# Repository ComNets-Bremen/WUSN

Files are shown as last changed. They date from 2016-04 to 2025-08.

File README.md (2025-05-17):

# MoleNet: A Wireless Underground Sensor Network Platform

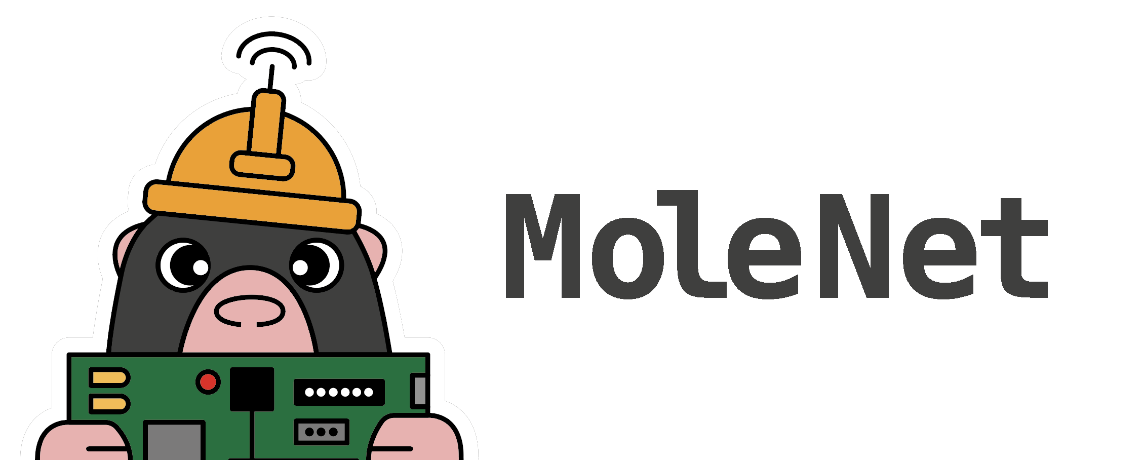
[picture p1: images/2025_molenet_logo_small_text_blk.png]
MoleNet Logo


**MoleNet** is a versatile Wireless Underground Sensor Network (WUSN) platform designed for education and low-power environmental monitoring.
This repository contains all relevant resources, including PCB layouts, source code, and examples to test and evaluate the platform.

Further information can be found on the official [MoleNet Website](https://molenet.org/)!

> ⚠️ **Note:** This is an active project. The files and directory structure are subject to change.

## New ESP32-based MoleNet!

After a long journey, we are finally at a point where we are testing the current version on a larger scale.
The latest version of MoleNet features several key improvements:

- **ESP32-S3 microcontroller**: A powerful yet energy-efficient processor that supports various development ecosystems including [MicroPython](https://micropython.org/), [Arduino](https://www.arduino.cc/), and [RiotOS](https://www.riot-os.org/)
- **SDI-12 sensor interface**: Compatible with high-quality environmental sensors
- **Micro-SD card support**: Enables extensive local data storage
- **SX1276-based LoRa transceiver**: Provides long-range wireless communication
- **On-board BME280 sensor**: Measures temperature, barometric pressure, and humidity [BME280](https://www.bosch-sensortec.com/products/environmental-sensors/humidity-sensors-bme280/)
- **Low-power design**: Ensures long battery life for extended deployments
- **qwiic connectivity**: Simplifies integration of I2C-based sensors, as, for
  example, available here: [Sparkfun](https://www.sparkfun.com/qwiic)

## Older Versions

Documentation for the ATMEGA-based MoleNet boards can be found in the [documentation directory](docs/MoleNet_ATMEGA.md).

## Changelog

The list of changes and the evolution of MoleNet is listed in the
[changelog](CHANGELOG.md).

## Publications

The following list gives some MoleNet-related publications:

- Gellhaar, M., Dede, J., Koehler, H., & Förster, A. (2016, February). Design and Evaluation of Underground Wireless Sensor Networks for Reforestation Monitoring. [In EWSN (pp. 229-230)](https://dl.acm.org/doi/10.5555/2893711.2893747).
- Zaman, I., Dede, J., Gellhaar, M., Koehler, H., & Foerster, A. (2016). Molenet: A new sensor node for underground monitoring. [IEEE SenseApp](https://www.researchgate.net/publication/309397324_MoleNet_A_New_Sensor_Node_for_Underground_Monitoring).
- Zaman, I., Gellhaar, M., Dede, J., Koehler, H., & Foerster, A. (2016, November). Design and evaluation of MoleNet for wireless underground sensor networks. In 2016 IEEE 41st conference on local computer networks workshops (LCN workshops) (pp. 145-147), [2016 IEEE 41st Conference on Local Computer Networks Workshops (LCN Workshops), Dubai, United Arab Emirates, 2016, pp. 145-147](https://doi.org/10.1109/LCN.2016.040).
- Dede, J., Helms, D., & Förster, A. (2021). MoleNet: An Underground Sensor Network for Soil Monitoring. [Electronic Communications of the EASST, 80](https://doi.org/10.14279/tuj.eceasst.80.1132)
- Sambo, D. W., Dede, J., Mitton, N., & Förster, A. (2023). FuzDeMa: A portable Fuzzy-based Decision-Making tool for reliable communication in Wireless Underground Sensor Networks. [ITU Journal on Future and Evolving Technologies, 4(3), 419-433](https://www.doi.org/10.52953/IXIP2995).

## I Want to Have MoleNet!

MoleNet is a dynamic project that is constantly evolving. At its current stage, we do not offer a ready-to-use, fully certified product with complete end-user support.

If you would like to contribute to the development of MoleNet and need hardware for testing and further development, you have two options:

1. **Build the hardware yourself.** All the necessary resources can be found in this repository.
2. **Order evaluation boards** from our partner [Intergalactic Circuits](https://intergalactic-circuits.de) for personal use.

## Contributors

Many students and researchers contribute to the MoleNet project.
See the full list of contributors in [CONTRIBUTORS.md](CONTRIBUTORS.md).

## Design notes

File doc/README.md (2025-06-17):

# Documentation

This directory contains the documentation of MoleNet. For the previous
versions, please refer to the [ATMEGA](ATMEGA) or [stm32](stm32) directory, respectively.

# The Hardware

MoleNet 6.1 with all available components assembled. Click on the image for a
high resolution version.

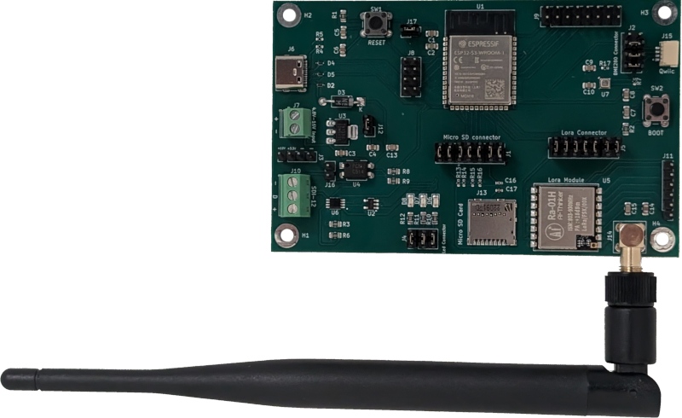
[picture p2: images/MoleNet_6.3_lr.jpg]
The MoleNet 6.3 hardware


## Available Components

- LoRa (SX1276) via Ra-01H module
- BME280
- SD-card holder
- qwiic for external I2C components
- LEDs
- SDI-12 for environmental sensors
- Additional pins (analog and digital)

## Components and their Connections

MoleNet contains various different on-board parts. The following tables lists
the connections and other relevant information for the major parts. For further
details, refer to [schematics of the board](../PCB-Layouts/). The table lists
the part of the board revision 6.3.

| **Part** | **Part Number** | **Description** | **Pins** |
|---|---|---|---|
| SW1 | SKHHARA010 | Reset button (enable) for ESP32 | EN |
| SW2 | SKHHARA010 | Boot mode button for ESP32 | GPIO0 |
| U1 | [ESP32-S3-WROOM-1-N16](https://www.espressif.com/sites/default/files/documentation/esp32-s3-wroom-1_wroom-1u_datasheet_en.pdf) | ESP32-S3 | |
| U3 | [TLV76133DCYR](https://www.ti.com/product/de-de/TLV761/part-details/TLV76133DCYR) | Voltage regulator 3V3 | |
| U5 | Ra-01H | LoRa Module ([SX1276](https://www.semtech.com/products/wireless-rf/lora-connect/sx1276)) | RESET=GPIO15, NSS=GPIO48, MOSI=GPIO47, MISO=GPIO21, SCK=GPIO14, DIO0=GPIO46 |
| U7 | [BME280](https://www.bosch-sensortec.com/products/environmental-sensors/humidity-sensors-bme280/) | Sensor for humidity, barometric pressure and ambient temperature | I2C, SCL=GPIO8, SDA=GPIO9, address=0x76 |
| D6 | NCD0805R1 | User LED | GPIO38 |
| D7 | NCD0805R1 | User LED | GPIO2 |
| D8 | NCD0805R1 | Power LED | Power |
| J1 | | Enable SD-card via jumpers | Power=GPIO7 (optional), MOSI=GPIO11, MISO=GPIO13, SCK=GPIO12, CS=GPIO10 |
| J2 | | Enable BME280 connection via jumpers | |
| J3 | | Power out | GND, 3V3, Vin |
| J4 | | Enable LEDs via jumpers | |
| J5 | | Enable LoRa via jumpers | |
| J6 | | USB connector | |
| J7 | | Power in | |
| J8 | | Misc. pins (ADC etc.) | |
| J9 | | Unused GPIOs | |
| J10 | | SDI-12 connector | Uses the following GPIOs: Power=GPIO1, SDI_RX_ENABLE=GPIO36, SDI_RX=GPIO18, SDI_TX_ENABLE=GPIO35, SDI_TX=GPIO17, SDI_MARKING=GPIO37 |
| J11 | | Remaining DIOs from LoRa transceiver | |
| J12 | | Power connector for energy measurements of the entire board. Connect via jumper | |
| J13 | | Micro SD card holder | |
| J14 | SMA-KWE902 | SMA connector for LoRa | |
| J15 | | qwiic connector for I2C devices | SCL=GPIO8, SDA=GPIO9 (shared with BME280) |
| J16 | | Power SDI-12 interface via jumper. Alternative: switch using GPIO1 | |
| J17 | | Jumper for ESP32 power supply. Used to measure only the power consumption of the ESP. Connect via jumper. | |

## Pins on the ESP32

For the usage of the pins, please refer to the hardware section in this
document or the schematics of the corresponding versions available in [the PCB-Layouts directory](../PCB-Layouts/).

# Setup using Arduino

1) Install **Arduino IDE** -> [arduino.cc](https://www.arduino.cc/en/software/)
2) Install the **esp32** package by Espressif via the **Boards Manager** in the IDE
3) Select the **ESP32S3 Dev Module** as the board
4) Select the corresponding USB port
5) Set USB CDC On Boot: Enabled
6) Set USB Mode: USB-OTG (Tiny USB)

**⚠️ Attention: Different ports!**

Different ports are created at various times when the MoleNet platform is connected to the computer. One port is to flash the firmware, while the second is to access the MoleNet Platform’s serial port. The first is the default after a reset. The second is usually entered if the boot button is pressed during reset or when powering up the board.

Usually, you have to setup the board twice according to the settings above. Be
aware that the port identifier can change depending on your operating system.

# Setup using MicroPython

Please use the documentation for the ESP32 available at
[micropython.org](https://micropython.org/download/ESP32_GENERIC_S3/).

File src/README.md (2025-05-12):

MoleNet Sourcecode
==================

The sourcecode of MoleNet. For older Versions, i.e. the ATMEGA-based versions,
please check the directory [ATMEGA-based](ATMEGA-based).

The other directories contain the code examples for the ESP32-based versions.

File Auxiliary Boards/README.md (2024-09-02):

This folder contains files for auxiliary pcbs related to Molenet project.

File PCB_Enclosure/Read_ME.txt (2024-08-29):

The PCB Enclousre is designed for the Molenet_V5.2 PCB Design. The enclosure is designed in Freecad 0.19.

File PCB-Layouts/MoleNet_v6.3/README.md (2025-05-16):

This folder contain Kicad files of Molenet V6.3 Board.

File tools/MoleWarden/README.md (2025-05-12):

MoleWarden - The MoleNet Maintanance Tool
=========================================

This tool is kind of proof of concept. It should automatize the repeating tasks
for

- Setting up and testing new devices
- Repeating testing existing devices (returned from test campaigns etc.)
- Install the MicroPython VM
- Keep track of the devices: When have they been tested last time?

Start the script
================

This script is tested using Debian Linux.

1) Create a venv: `python -m venv venv`
2) Activate the venv: `. ./venv/bin/activate`
3) Install the requirements: `pip install -r requirements.txt`
4) Run the script: `./run.py`

Update the requirements.txt
===========================

To update the [requirements.txt](requirements.txt), follow those steps:

1) Make sure pipreqs is installed: `pip install pipreqs`
2) Save the requirements: `pipreqs .`

Ideally, everything should be located in a `venv`, `pipenv` etc.

Authors
=======

- Jens Dede <jd@comnets.uni-bremen.de>, Sustainable Communication Networks,
  University of Bremen

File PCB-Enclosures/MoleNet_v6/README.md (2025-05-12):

A case / desktop stand for MoleNet v6
=====================================

printed with 15% infill no support needed.

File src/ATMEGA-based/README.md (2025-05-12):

# This directory contains the sourcecode for the ATMEGA-based MoleNet boards

## MoleNet_1.0

This directory contains the first working version with the most important
functionalities

## MoleNet_1.1

Current development version with some improvements in the libraries

## MoleNet_2.0

This directory contains the improved version, supporting static routing, wireless configuration and many other functionalities

## Maintenance

This directory contains a maintenance app for MoleNet to
- Get / set the time
- Set the node id
- Erase the flash

## wusnExampleServer

An (outdated) webserver based on Django to store and display the measurements
collected by MoleNet 1.0 boards.

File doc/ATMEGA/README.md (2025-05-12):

# ATMEGA-based MoleNet

The first versions of MoleNet were quite similar to Arduino Uno boards.
Therefore, programming was based on that ecosystem. Those steps are required to
get MoleNet v1, v2 and v3 up and running.

## Prerequisites

The following Arduino libraries are required:

- LowPower: <https://github.com/LowPowerLab/LowPower>
- RFM69: <https://www.github.com/lowpowerlab/rfm69>
- RV8523: <https://github.com/watterott/Arduino-Libs>
- spieep: <https://bitbucket.org/spirilis/spieep/>

## MoleNet (rev. 1.0)

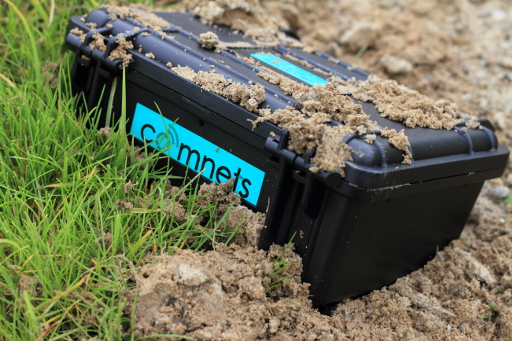
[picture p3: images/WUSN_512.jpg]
The WUSN node


### Settings for the Arduino IDE

Arduino IDE:

- Tools -> Board: "Arduino Pro or Pro Mini"
- Tools -> Processor: "ATmega328 (3.3V, 8MHz)"
- Tools -> Port: (USB port to which the programmer is attached)

Baud-rates:

- reading from MoleNet node: 1200 Baud (don't change!!!)
- reading from MoleNet simple Gateway: 115200 Baud
- setting the RTC: 9600 Baud (could also be changed)

### Data Format (simple Gateway)

The app just listens for packets and print the payload with correct formatting
The data format is as follows:

    #[PACKETNUMBER][NODEID] 'D'YEAR/MONTH/DAY 't'HOUR:MINUTE 'W'VWCRAWVALUE 'T'TEMPRAWVALUE CHECKSUM SUCCESSINDICATOR   ['RX_RSSI:'VALUE] - 'ACK sent.'

example:

    #[2][2] D16/3/30 t15:36 W0468 T0594 68 1    [RX_RSSI:-28] - ACK sent.

### Set the RTC time (Set_RTC)
The program prints current time of RTC to serial port every second. The time
can be changed by sending the new value using the serial line and terminate it
with a carriage return. Possible commands are:

- y : change the year, enter full year (e.g., 2016)
- M : change the month
- d : change the day
- h : change the hour
- m : change the minute
- s : change the second
- w : change the weekday (0: Monday, 1: Tuesday...)

### Manually trigger a measurement

Pull pin `Int1` at the RTC to ground. One tip is enough

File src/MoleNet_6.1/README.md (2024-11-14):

This directory contains the code and library files that are used for testing Molenet V6.1 Board.

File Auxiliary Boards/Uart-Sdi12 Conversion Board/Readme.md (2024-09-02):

This folder contains Kicad project files for Uart-Sdi12 conversion pcb.

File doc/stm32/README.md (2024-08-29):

This manual worked on Manjaro Linux, no guarantee for other distros/operations systems.
# Installing Micropython on STM32 board

1. Install micropython unix from https://github.com/micropython/micropython
    1. Clone repository

        ```
        git clone https://github.com/micropython/micropython
        ```
    2. Build micropython

        ```
        $ cd ports/unix
        $ make submodules
        $ make
        ```
    3. check installation

        ```
        $ ./micropython
        ```
    4. Run complete testsuite

        ```
        $ make test
        ```
2. Install STM32 version
    1. Build:

        ```
        $ cd ports/stm32
        $ make submodules
        $ make
        ```
    2. Install pyusb if not done already

        ```
        $ pip3 install pyusb
        ```
    3. put board in DFU mode
        1. Either by running the command `machine.bootloader()` in REPL
        2. Or by pulling BOOT0 to 3.3V and reset the board
    4. Flash the code via USB DFU to your device

        ```
        $ make BOARD=NUCLEO_L073RZ deploy-stlink
        ```
    5. If 4. doesn’t work:
        1. install STM32CubeProgrammer
        2. press connect and go to Erasing & Programming then install /micropython/ports/stm32/build-NUCLEO_L073RZ/firmware.bin  which you built in step 4

# Running Code

1. Connect board to PC
2. Find the path the Board is connected to
    1. usually it is at ttyACM0
    2. sudo dmesg | grep tty often helps, the entire list of devices can be found using /sys/class/tty
3. For testing purposes you can install rshell
    1. run rshell -p /dev/ttyACM0 (adjust the path name accordingly)
    2. enter the command repl
    3. now you can run some commands for testing, for example:
        1. Hello World

            ```
            print(„Hello world“)
            ```
        2. Toggle LED:

            ```
            >>> import pyb
            >>> pyb.LED(1).on()
            >>> pyb.LED(1).off()
            ```
4. Now configure your IDE i.e. VS Code by installing the pymakr extension
    1. If you have troubles, try adding yourself to the dialout group

        ```
        sudo usermod -a -G dialout <your-username>
        ```
5. If 4 doesn’t work, files can be uploaded via rshell by using the command

    ```
    cp filename.py /pyboard
    ```

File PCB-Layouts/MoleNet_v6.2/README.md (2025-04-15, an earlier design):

This folder contain Kicad files of Molenet V6.2 Board.

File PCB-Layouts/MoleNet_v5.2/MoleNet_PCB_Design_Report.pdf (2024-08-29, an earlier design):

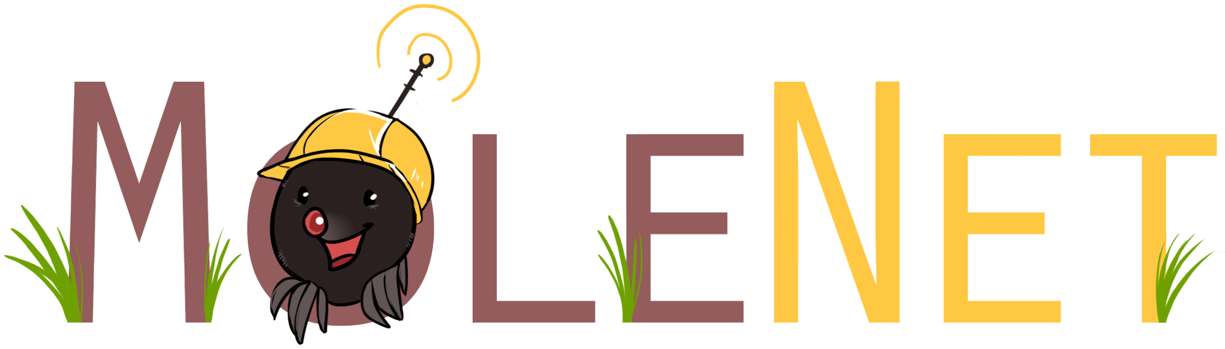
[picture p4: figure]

# MoleNet PCB Design

## Eenesh Chavan

Comnets | PCB Design

## Contents

1 PCB Design | 2
1.1 SMD components | | 2
1.2 | Trace Width | | 2
1.3 RTC Backup Calculation | | 4
1.4 DRC | | 4

## List of Figures

1 | MoleNet PCB V5.2 | | 2
2 | Trace width calculation | | 3
3 | Trace Length | | 3
4 | Trace Impedance Matching | | 4
5 | DRC parameters | | 5
6 | DRC Result | | 5

1

Comnets | PCB Design

## 1. PCB Design

The MoleNet PCB V5.2 was designed in KiCad 6.0.

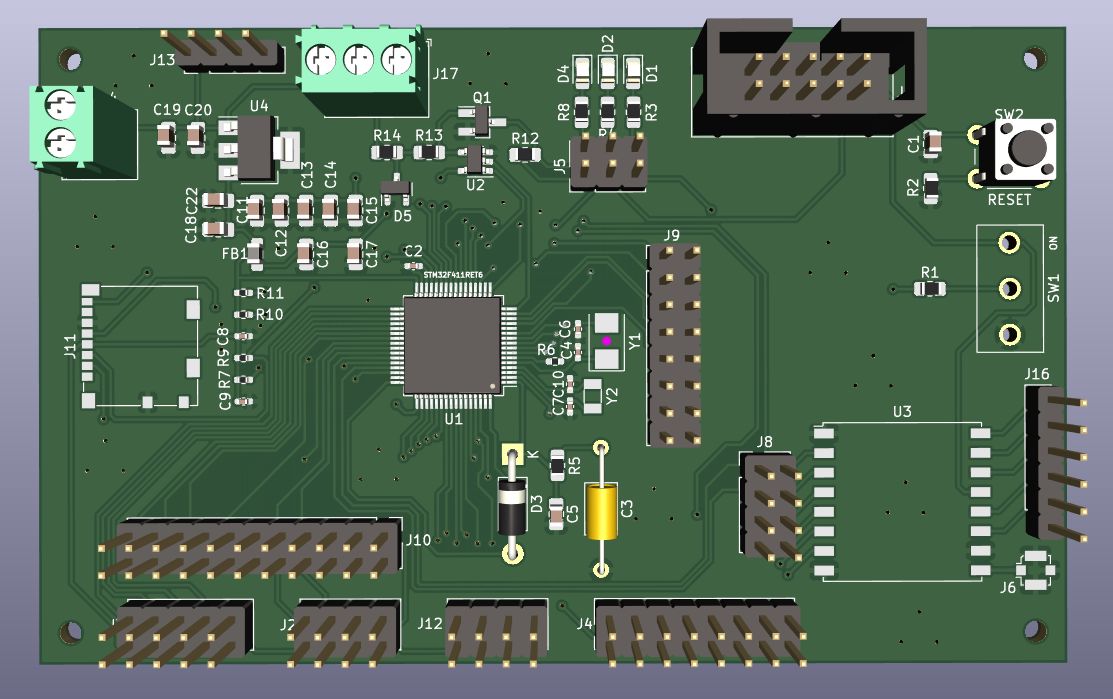
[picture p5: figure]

Figure 1: MoleNet PCB V5.2

### 1.1. SMD components

The Hand solder pad footprint has been used for the 0402 and 0805 SMD components. That is the reason the pads are elongated below the components.

The parts used on the PCB are currently (03/08/2022) all available on JLCPCB Assembly Parts Library. The list of the parts chosen can be found here: [1]. This list is not the exported BOM of the designed PCB, but this sheet was maintained to have an updated Part list during the designing process.

### 1.2. Trace Width

The trace width for all the traces used is 0.254 mm. The value used was based on the Calculator Tools (available in KiCad 6.0) result 2.

2

Comnets | PCB Design

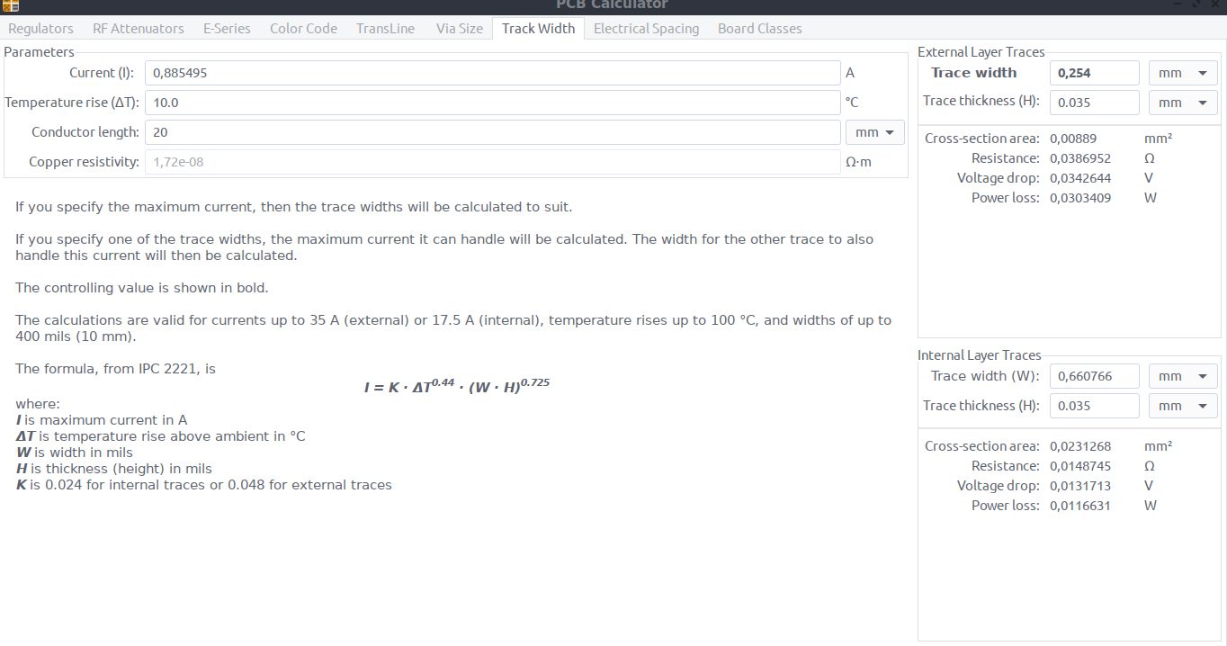
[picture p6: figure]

Figure 2: Trace width calculation

The length of the Trace connecting the RF output port of the RFM Module and the U. FL connector is 4.10 mm 3.

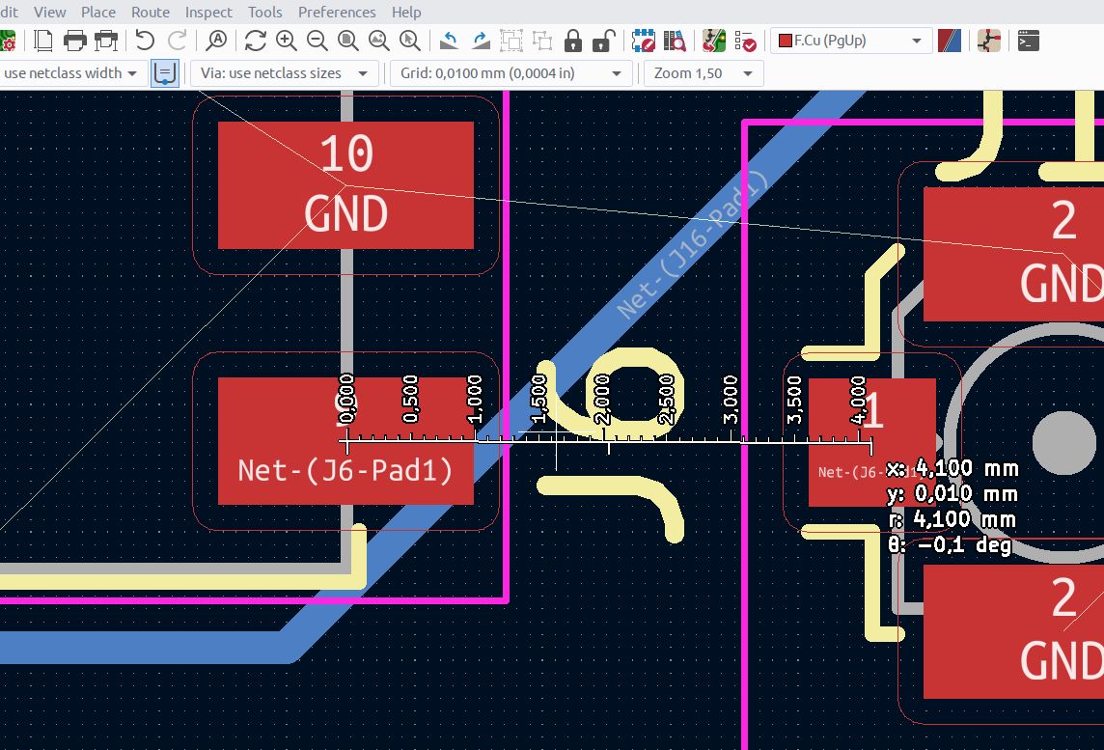
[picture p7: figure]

Figure 3: Trace Length

The width of the RF Trace was chosen as per the result from the Calculator Tools result, to keep the impedance of the trace equal to 50Ohms for impedance matching 4.

3

Comnets | PCB Design

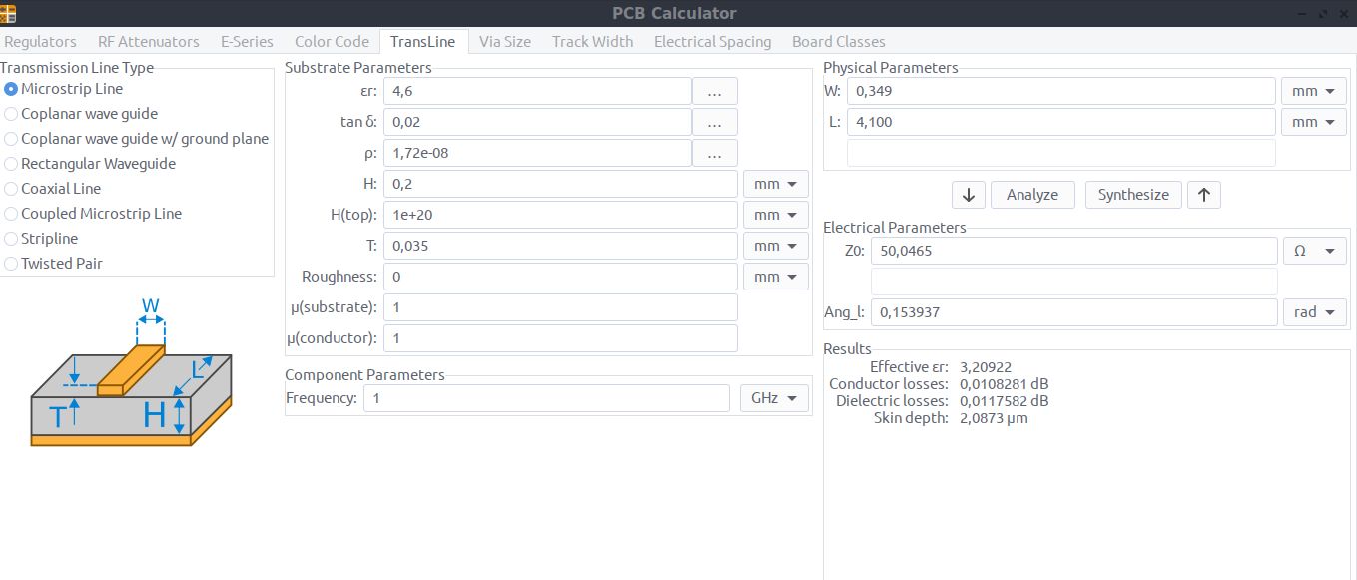
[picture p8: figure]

Figure 4: Trace Impedance Matching

### 1.3. RTC Backup Calculation

The Backup power supply to maintain the RTC function of the MCU is designed to last around 10days. The VBAT supply ckt. uses 1F supercapacitor for this. The capacity of the capacitor is calculated as:

C = I.t/∆V

I = 1.6uA

t = 864000s

∆V = 1.1V

The value for I and ∆V was chosen based on the Table 31, on page 76 of the STM32F411x Datasheet [2]. The circuit is made from the reference: [3].

### 1.4. DRC

There were no errors or warnings in the DRC (in KiCad). The parameters for the DRC were set according to the JLCPCB PCB Manufacturing Capabilities found here: [4].

4

Comnets | PCB Design

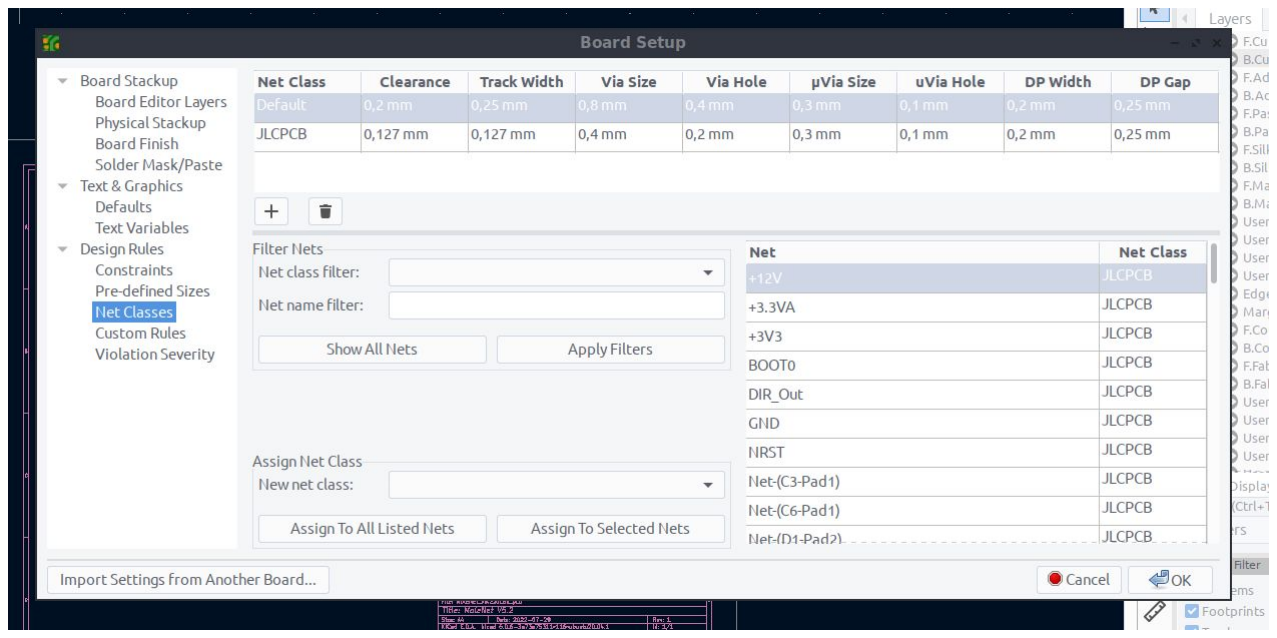
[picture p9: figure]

Figure 5: DRC parameters

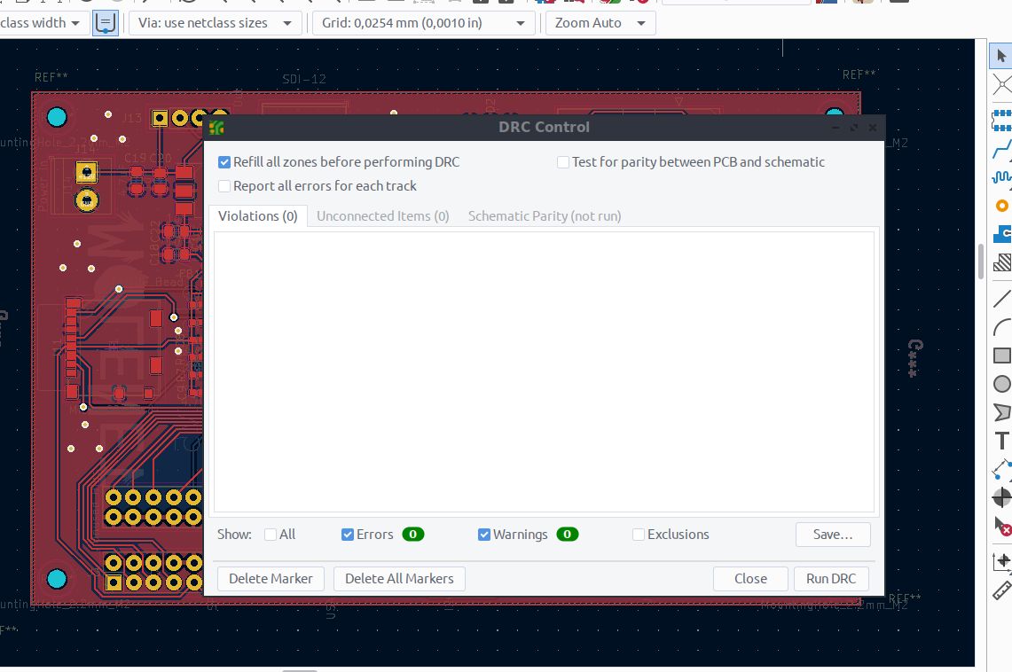
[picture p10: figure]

Figure 6: DRC Result

## References

[1] Eenesh Chavan. Part List. url: https://docs.google.com/spreadsheets/d/1JT8qHO8G_W_1jqCkwKPx2EyGsKR18wwE71jqyKe1d2M/edit?usp=sharing (https://docs.google.com/spreadsheets/d/1JT8qHO8G_W_1jqCkwKPx2EyGsKR18wwE71jqyKe1d2M/edit?usp=sharing) (visited on 08/03/2022).
[2] STMicroelectronics. STM32F411RET6 Datasheet. url: https://www.st.com/en/microcontrollers-microprocessors/stm32f411.html# (https://www.st.com/en/microcontrollers-microprocessors/stm32f411.html#) (visited on 08/03/2022).
[3] electronics.stackexchange. RTC backup on STM32. url: https://electronics.stackexchange.com/questions/129405/supercap-charging-circuit-for-rtc-backup-on-stm32 (https://electronics.stackexchange.com/questions/129405/supercap-charging-circuit-for-rtc-backup-on-stm32) (visited on 08/03/2022).
[4] JLCPCB. PCB Manufacturing Assembly Capabilities. url: https://jlcpcb.com/capabilities/pcb-capabilities (https://jlcpcb.com/capabilities/pcb-capabilities) (visited on 08/03/2022).

5

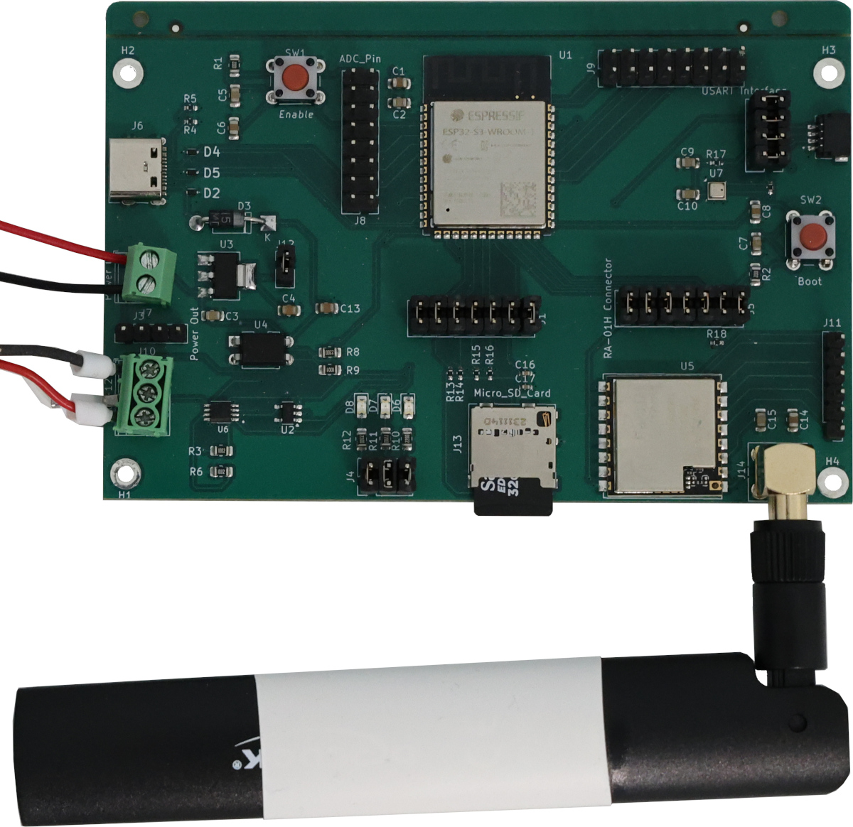
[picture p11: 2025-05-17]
images/MoleNet_6.1.jpg

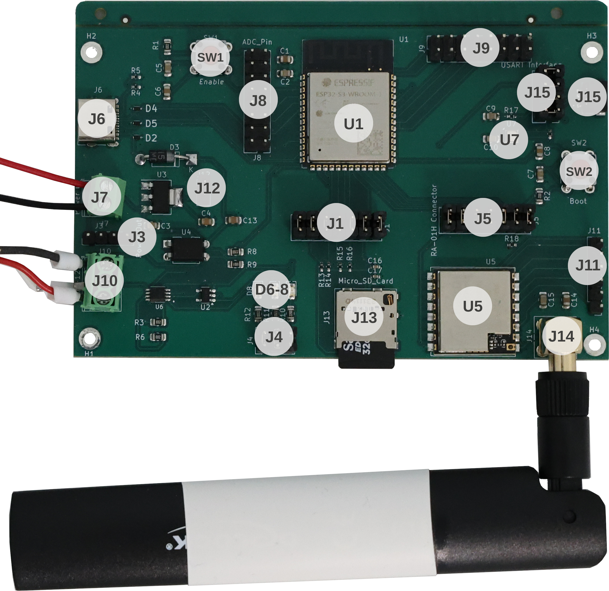
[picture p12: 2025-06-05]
images/MoleNet_6.1_labels_hq.jpg

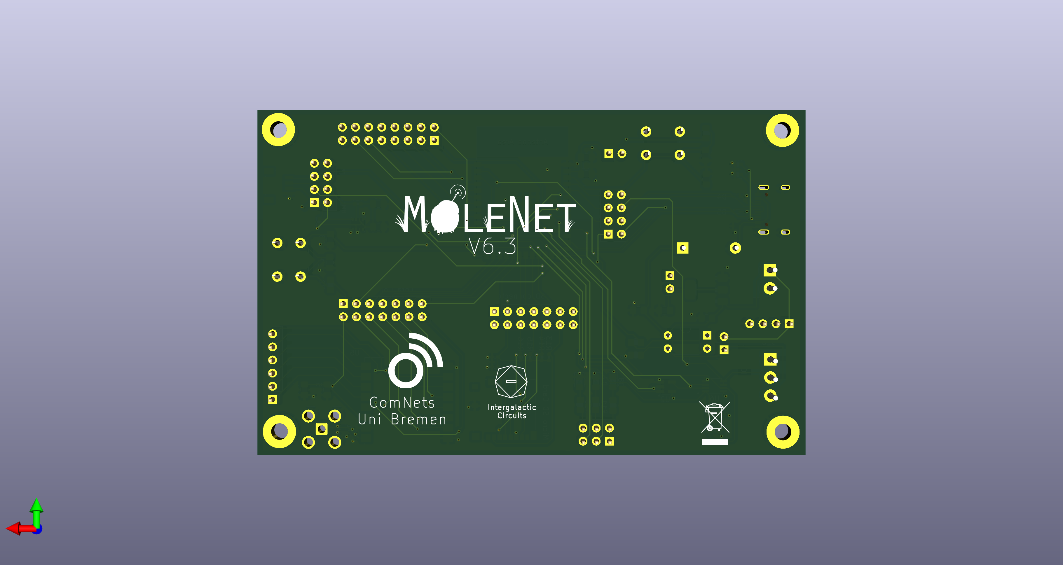
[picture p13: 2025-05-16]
PCB-Layouts/MoleNet_v6.3/Back_View_Molenet_V6.3_15_05_25.png

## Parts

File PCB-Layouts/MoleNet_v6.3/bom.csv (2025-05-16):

Designator | Footprint | Quantity | Value | LCSC Part #
C1, C14 | 0805 | 2 | 22uF
C10, C5, C7, C9 | 0805 | 4 | 0.1uF
C13 | 0805 | 1 | 10uF
C15, C2 | 0805 | 2 | 100nF
C16 | 0402 | 1 | 22uF
C17 | 0402 | 1 | 100nF
C3, C6, C8 | 0805 | 3 | 1uF
C4 | 0805 | 1 | 2.2uF
D2, D4, D5 | LESD5D50CT1G | 3 | LESD5D5.0CT1G
D3 | D_DO-41_SOD81_P10.16mm_Horizontal | 1 | 1N5819
D6, D7, D8 | 0805 | 3 | LED
H1, H2, H3, H4 | MountingHole_3.2mm_M3_Pad | 4 | MountingHole_Pad
J1 | PinHeader_2x07_P2.54mm_Vertical | 1 | Micro SD connector
J10 | TerminalBlock_Phoenix_PT-1,5-3-3.5-H_1x03_P3.50mm_Horizontal | 1 | SDI-12
J11 | PinHeader_1x06_P2.54mm_Vertical | 1 | RA_01_DIO
J12, J16, J17 | PinHeader_1x02_P2.54mm_Vertical | 3 | Conn_01x02
J13 | microSD_HC_Molex_104031-0811 | 1 | Micro SD Card
J14 | SMA_Amphenol_901-143_Horizontal | 1 | Conn_Coaxial
J15 | SPARKFUN_PRT-14417 | 1 | Qwiic
J2 | PinHeader_2x04_P2.54mm_Vertical | 1 | BME280 Connector
J3 | PinHeader_1x04_P2.54mm_Vertical | 1 | Power Out
J4 | PinHeader_2x03_P2.54mm_Vertical | 1 | Led Connector
J5 | PinHeader_2x07_P2.54mm_Vertical | 1 | Lora Connector
J6 | USB_C_Receptacle_G-Switch_GT-USB-7010ASV | 1 | USB_C_Receptacle_USB2.0
J7 | TerminalBlock_Phoenix_PT-1,5-2-3.5-H_1x02_P3.50mm_Horizontal | 1 | 4.8V-16V Input
J8 | PinHeader_2x04_P2.54mm_Vertical | 1 | ~
J9 | PinHeader_2x08_P2.54mm_Vertical | 1 | Unused Pin
R1, R2, R3, R6 | 0805 | 4 | 10k
R10, R11, R12, R8 | 0805 | 4 | 220
R13, R14, R15, R16 | 0402 | 4 | 10K
R17, R7 | 0402 | 2 | 4.7K
R4, R5 | 0402 | 2 | 5.1k
R9 | 0805 | 1 | 1k
SW1 | SW_PUSH_6mm_H4.3mm | 1 | RESET
SW2 | SW_PUSH_6mm_H4.3mm | 1 | BOOT
U1 | ESP32-S3-WROOM-1 | 1 | ESP32-S3-WROOM-1
U2 | SC-74A-5_1.55x2.9mm_P0.95mm | 1 | 74AHC1G00
U3 | SOT-223-3_TabPin2 | 1 | TLV76133DCY
U4 | DIP-4_W7.62mm | 1 | PC817
U5 | Ai-Thinker-Ra-01-LoRa | 1 | Lora Module
U6 | SOP65P400X130-8N | 1 | 74LVC2G241
U7 | Bosch_LGA-8_2.5x2.5mm_P0.65mm_ClockwisePinNumbering | 1 | BME280

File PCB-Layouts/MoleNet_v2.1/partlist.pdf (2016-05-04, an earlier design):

partlist

Page 1

Part | Value | RS | Reichelt | Comments
C1 | 4,7uF | 711-1223 | RAD 4,7/35
C2 | 1uF | 789-9251 | Z5U-5 1,0µ
C3 | 1uF | 789-9251 | Z5U-5 1,0µ
C4 | 100nF | 699-5027 | Z5U-2,5 100N
C5 | 100nF | 699-5027 | Z5U-2,5 100N
C6 | 100nF | 699-5027 | Z5U-2,5 100N
C7 | 22pF | 811-8360 | KERKO 22P
C8 | 22pF | 811-8360 | KERKO 22P
C9 | 100nF | 699-5027 | Z5U-2,5 100N
C10 | 100nF | 699-5027 | Z5U-2,5 100N
C11 | 100nF | 699-5027 | Z5U-2,5 100N
C12 | 100nF | 699-5027 | Z5U-2,5 100N
IC1 | 25LC512 | 454-179 | 25LC512-I/P | at the moment very expensive at Reichelt!!!
IC1 | IC-Socket 8pin | 197-2647 | GS 8P
JP1 | PINHD-1X2 | 156-049 | SL 1X50G 2,54
JP2 | PINHD-2X3 | 279-9853 | | pinhead 2x3 (similar to JP6) + jumper or: jumper switches from RS
JP3 | PINHD-1X3 | 156-049 | SL 1X50G 2,54
JP4 | PINHD-1X3 | 156-049 | SL 1X50G 2,54
JP5 | PINHD-1X4 | 156-049 | SL 1X50G 2,54
JP6 | PINHD-2X5 | 251-8294 | SL 2X50G 2,54
JP7 | PINHD-1X6 | 156-049 | SL 1X50G 2,54
JP8 | PINHD-1X3 | 156-049 | SL 1X50G 2,54
K1 | | | AST 025-03
L1 | 10mH | 489-0009 | 09P 10M
Q1 | BS250 | 215-6688 | BS 250
Q2 | BS170 | 671-4736 | BS 170
Q3 | 8MHz | 478-9347 | 8,0000-HC49U-S
R1 | 10k | 148-736 | METALL 10,0K
R2 | 100k | 148-972 | METALL 100K
RTC | | | | Watterott: 20111062
U1 | MCP1703-5002E/DB | 669-4897 | MCP 149-2-002-F0 | SOT-223 package
U2 | ATMEGA328P-PU | 696-2260 | ATMEGA 328P-PU

partlist

Page 2

U2 | IC-Socket 28pin | 801-796 | GS 28P-S
U3 | RFM69CW | | | Pollin: 810 302
X1 | SMA-142-0711-821/826 | 616-3422 | SMA BU P

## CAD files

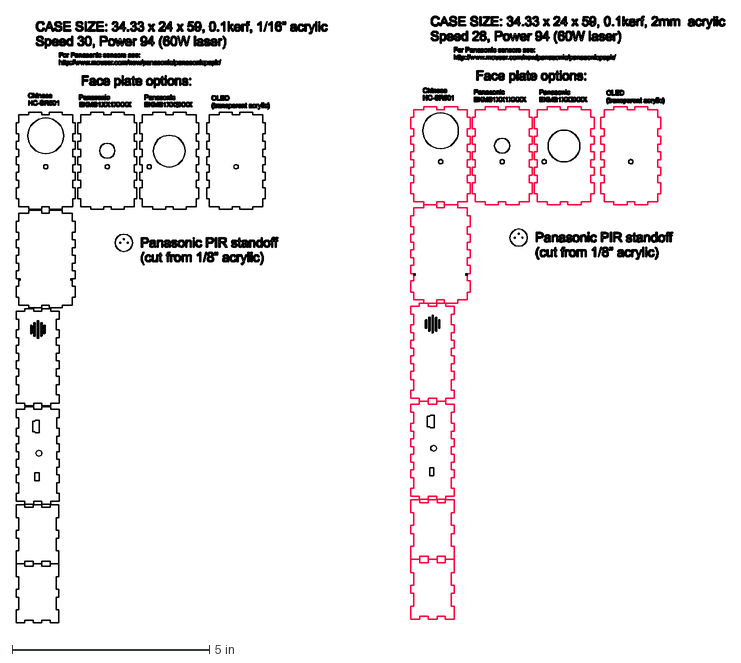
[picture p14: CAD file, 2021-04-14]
experiments/LoRa_Gateway_for_WUSN/Modified Libraries/RFM69_LowPowerLab/Examples/MotionMote/LasercutCase_R3.dxf
18.0 x 15.4 in

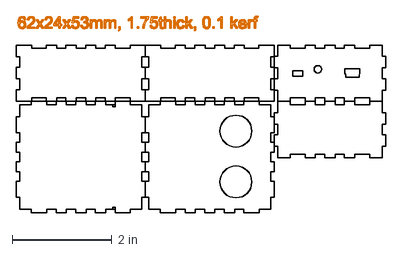
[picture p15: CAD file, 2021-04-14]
experiments/LoRa_Gateway_for_WUSN/Modified Libraries/RFM69_LowPowerLab/Examples/SonarMote/SonarMote_lasercut plans_1.75mm acrylic.dxf
7.41 x 3.94 in

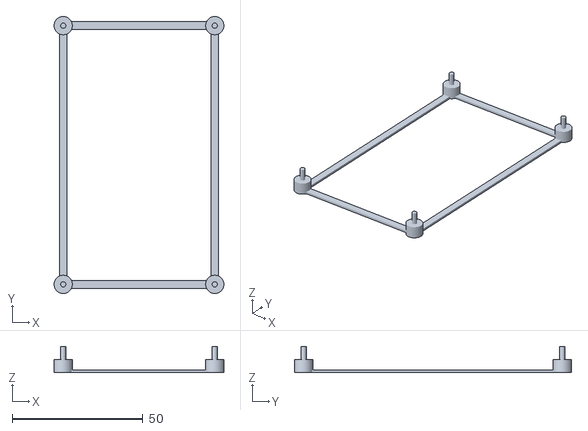
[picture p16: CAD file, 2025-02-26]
PCB-Enclosures/MoleNet_v6/Simple_Desk_Saver/Simple_Molenet_Desk_Saver.stl
65.0 x 106.0 x 10.0

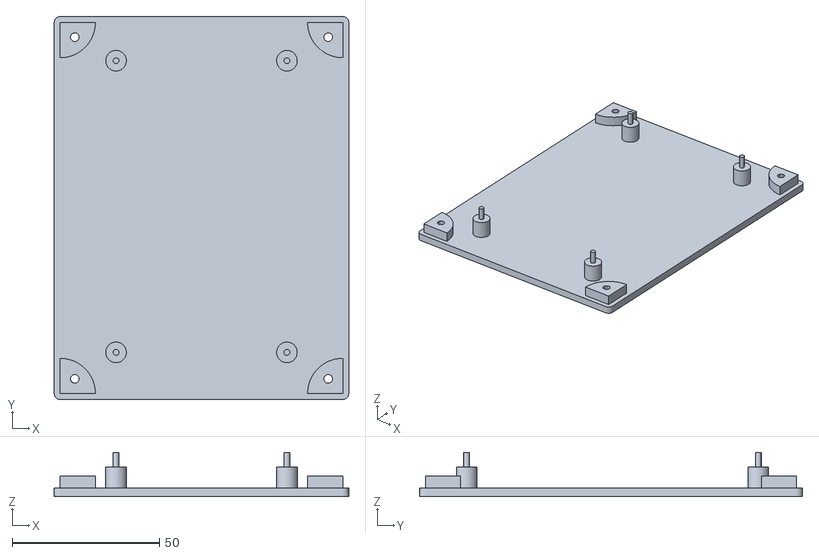
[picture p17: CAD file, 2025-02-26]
PCB-Enclosures/MoleNet_v6/Mounting_Plate/Molenet_V6_style_previousversion_2mm_Pillars.stl
100.0 x 130.0 x 15.0

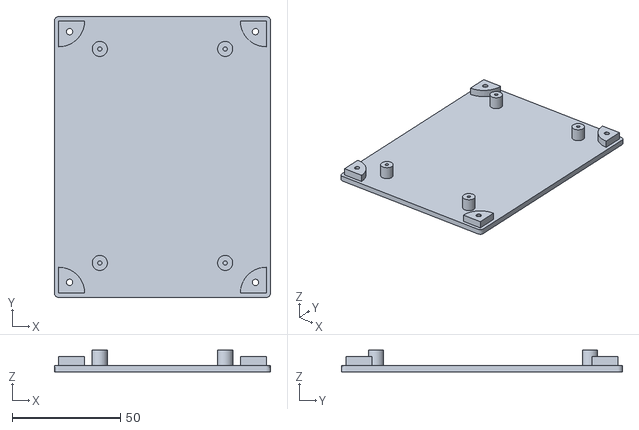
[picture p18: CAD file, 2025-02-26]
PCB-Enclosures/MoleNet_v6/Mounting_Plate/Molenet_V6_style_previousversion_2mm_holes.stl
100.0 x 130.0 x 10.0

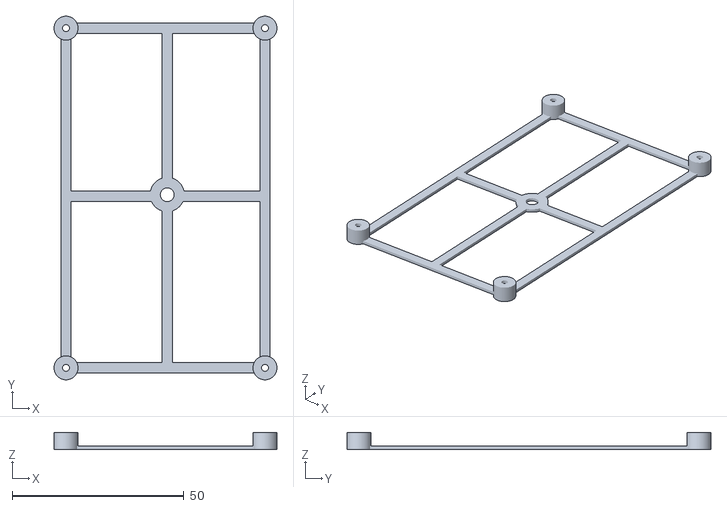
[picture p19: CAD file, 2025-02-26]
PCB-Enclosures/MoleNet_v6/Mounting_Plate/Simple_Molenet_V6_Mount_Single_Screw_2mm_Holes.stl
65.0 x 106.0 x 5.00

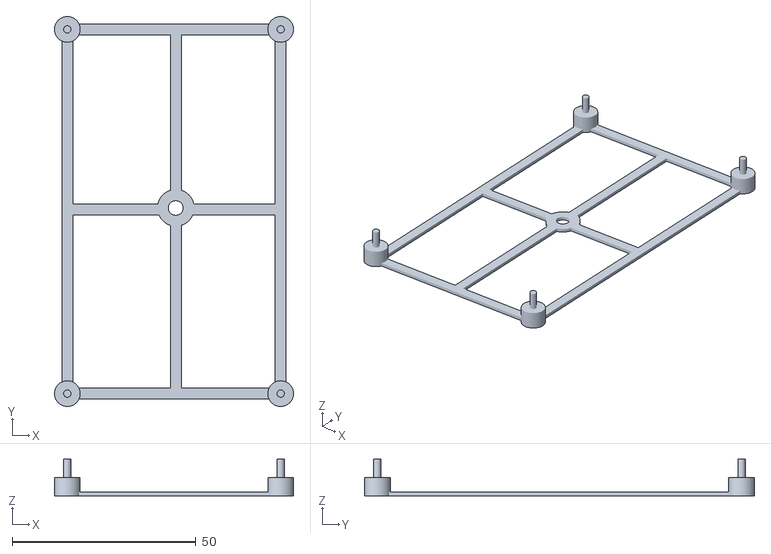
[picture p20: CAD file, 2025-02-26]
PCB-Enclosures/MoleNet_v6/Mounting_Plate/Simple_Molenet_V6_Mount_Single_Screw_Pillars.stl
65.0 x 106.0 x 10.0

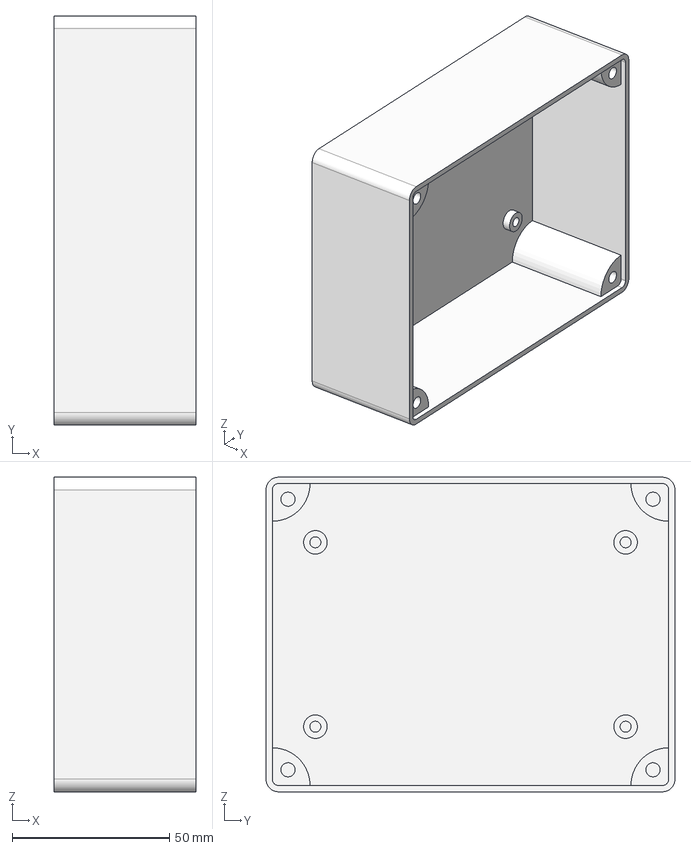
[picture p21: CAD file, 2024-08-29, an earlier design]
PCB-Enclosures/MoleNet_v5.2/PCB_Enclosure-Body.step
45.0 x 130.0 x 100.0 mm

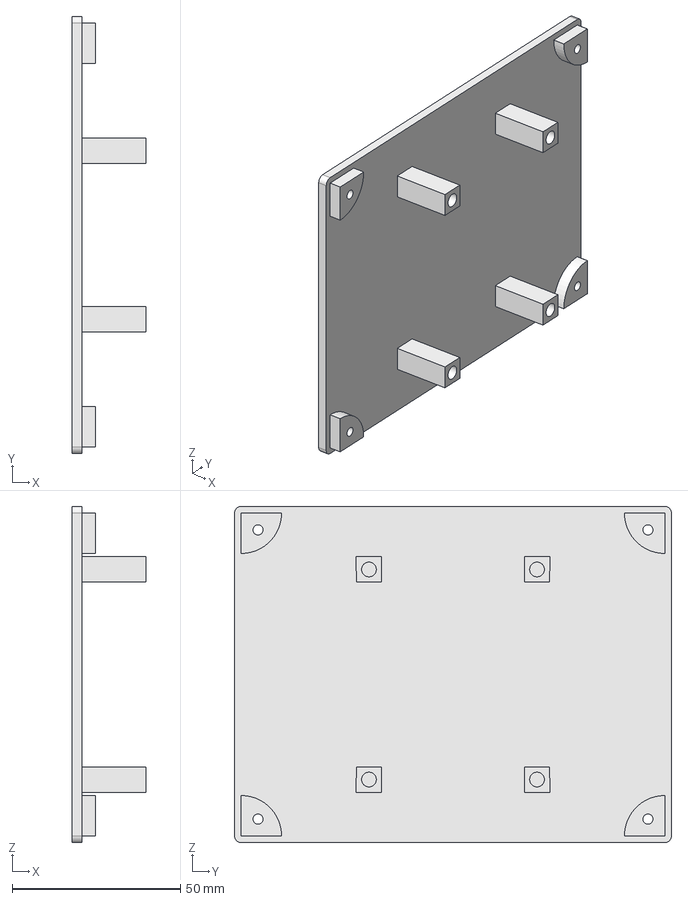
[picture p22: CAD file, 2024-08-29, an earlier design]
PCB-Enclosures/MoleNet_v5.2/PCB_Enclosure.FCStd
22.0 x 130.0 x 100.0 mm

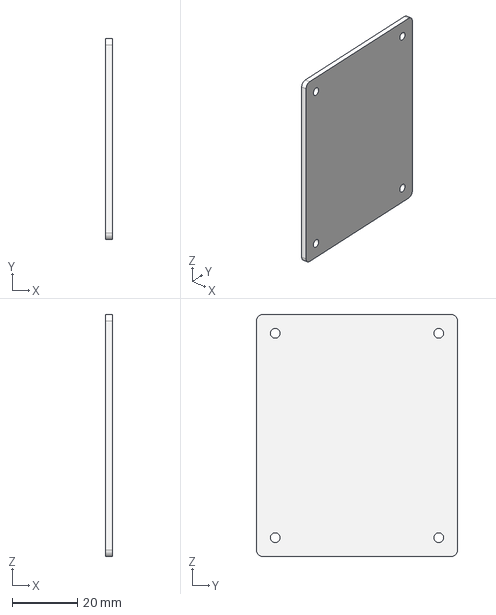
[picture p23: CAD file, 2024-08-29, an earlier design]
PCB-Enclosures/MoleNet_v5.2/PCB_Enclosure-Body002.step
2.00 x 61.5 x 74.0 mm

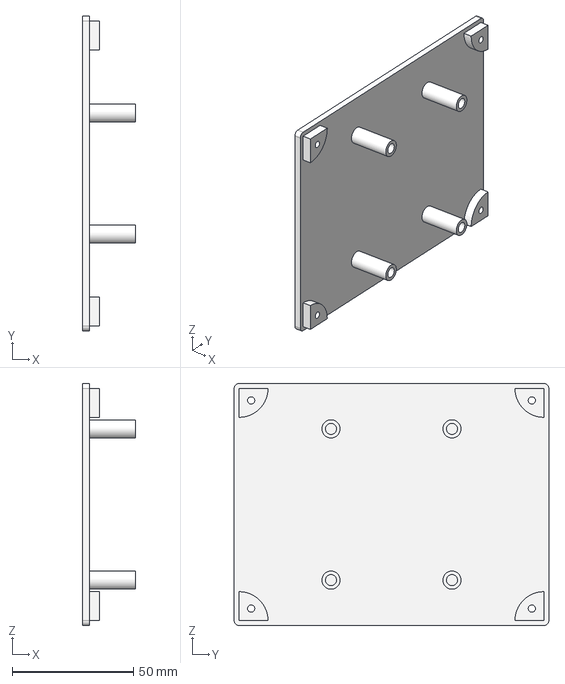
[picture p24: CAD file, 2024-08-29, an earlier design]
PCB-Enclosures/MoleNet_v5.2/PCB_Enclosure-Body001.step
22.0 x 130.0 x 100.0 mm

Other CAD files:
PCB-Enclosures/MoleNet_v5.2/PCB_Enclosure-Body003.step

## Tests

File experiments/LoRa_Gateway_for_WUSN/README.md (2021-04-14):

# LoRa Gateway for WUSN

LoRa Gateway for WUSN, created by Daniel Helms <dhelms@uni-bremen.de>, https://github.com/B00mb0x/LoRa_Gateway_for_WUSN

It is based on the PyCom boards / ESP32 with LoRa transceiver. https://pycom.io/

## Versions

This repository contains two versions of the gateway:

1) **Deepsleep** is a Python based version which uses the deep sleep
functionality. This version has a higher delay and should not be used for
scenarios, where messages are sent frequently.

2) **Lightsleep** is an Arduino-based version of the gateway. It requires more
energy but also higher packet rates.

## Field experiment
The measured data of the field experiment can be found in the folder Field_Experiment

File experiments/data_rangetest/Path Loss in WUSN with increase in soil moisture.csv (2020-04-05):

Distance(m) | Path Loss at 15% moisture(dBm) | Path Loss at 20% moisture(dBm) | Path Loss at 25% moisture(dBm) | Path Loss at 30% moisture(dBm) | Path Loss at 35% moisture(dBm) | Path Loss at 40% moisture(dBm) | Path Loss at 45% moisture(dBm) | Path Loss at 50% moisture(dBm)
1 | 6.8864027368 | 8.8712269051 | 12.7435628885 | 15.3584636433 | 17.3061728707 | 18.8497287574 | 20.1269693065 | 21.2177421733
2 | 44.3525257904 | 51.6108034796 | 55.9150434693 | 59.0757628112 | 61.6480041713 | 63.8684815963 | 65.8570735615 | 67.68174414
3 | 57.6570160806 | 65.7749035886 | 71.0511891112 | 75.1339904783 | 78.5464053888 | 81.5257846081 | 84.2006164803 | 86.6484084422
4 | 65.3716970945 | 73.2456432976 | 78.4224528168 | 82.4550150442 | 85.8364764852 | 88.792240364 | 91.4456763375 | 93.872178947
5 | 71.0797973323 | 78.7092827128 | 83.7602837335 | 87.7144410816 | 91.0416637523 | 93.9573366754 | 96.5797564032 | 98.9814550644
6 | 75.6566998413 | 83.0748911227 | 88.0125791488 | 91.8945440306 | 95.1711817479 | 98.0491751924 | 100.6423000888 | 103.0204876455
7 | 79.4925779001 | 86.7277574302 | 91.5637966734 | 95.3796715215 | 98.6093688472 | 101.4520537066 | 104.0175215076 | 106.3733807952
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

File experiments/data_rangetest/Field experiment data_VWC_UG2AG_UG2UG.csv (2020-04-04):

Time | VWC | UG2AG | UG2UG
'10/11/19 16:17:29' | 41.2 | -76 | -103
'10/11/19 16:32:28' | 41.2 | -75 | -103
'10/11/19 16:32:28' | 41.2 | -75 | -103
'10/11/19 16:47:28' | 41.16 | -76 | -103
'10/11/19 16:47:28' | 41.16 | -75 | -104
'10/11/19 17:02:28' | 41.18 | -75 | -103
'10/11/19 17:02:29' | 41.18 | -75 | -103
'10/11/19 17:17:28' | 41.16 | -75 | -104
'10/11/19 17:17:29' | 41.16 | -75 | -103
'10/11/19 17:32:28' | 41.16 | -74 | -102
'10/11/19 17:32:29' | 41.16 | -75 | -104
'10/11/19 17:47:28' | 41.24 | -75 | -102
'10/11/19 17:47:29' | 41.24 | -75 | -106
'10/11/19 18:02:28' | 41.2 | -75 | -104
'10/11/19 18:02:29' | 41.2 | -74 | -102
'10/11/19 18:17:28' | 41.24 | -74 | -104
'10/11/19 18:17:28' | 41.24 | -75 | -103
'10/11/19 18:32:28' | 41.18 | -75 | -103
'10/11/19 18:32:29' | 41.18 | -74 | -104
'10/11/19 18:47:28' | 41.2 | -74 | -102
'10/11/19 18:47:28' | 41.2 | -75 | -102
'10/11/19 19:02:28' | 41.18 | -74 | -105
'10/11/19 19:02:29' | 41.18 | -75 | -104
'10/11/19 19:17:28' | 41.24 | -75 | -103
'10/11/19 19:17:29' | 41.24 | -74 | -104
'10/11/19 19:32:28' | 41.26 | -75 | -104
'10/11/19 19:32:29' | 41.26 | -75 | -103
'10/11/19 19:47:28' | 41.2 | -74 | -103
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

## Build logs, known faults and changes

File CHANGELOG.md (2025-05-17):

# Changelog

## Hardware

The different layouts are located in the [PCB-Layouts](PCB-Layouts) directory.
Each directory (should) contain a `*_schematic.pdf` file with the corresponding
schematic.

### MoleNet v6.3

- Changed the LoRa reset pin to GPIO15: This one keeps the state during reset
  and therefore, keeps the LoRa module in sleep mode
- Add more logos at the back
- Improved the labels on the PCB

**Known issues**

- Not yet

### MoleNet v6.2

- Fixed the SDI-12 interface
- Fixed some labels (reset button, BME enable pins)
- Increase size of mounting holes from M2 to M3

**Known issues**

- Reset pin of LoRa not working. Bugfix: Keep the jumper for reset on J5 empty

### MoleNet v6.1

- Fixed the broken LED
- Add a QWIC connector for I2c-based devices
- Add an on-board BME280 temperature, humidity, ambient pressure sensor
- SD card power can be switched via a GPIO

### MoleNet v6.0

Redesign based on ESP32-S3, first version:

- The ESP supports MicroPython and Arduino
- All major components can be disconnected
- Direct ESP32 support for RTC
- SDI-12 interface, SD-card reader, native USB-port

**Known issues**

- Missing resistor on LED D7 (center)
- SDI-12 interface not working

### MoleNet v5.2.2

Change in USART interface, new HF connector

### MoleNet v5.2

Add more jumpers for the LEDs

### MoleNet v5.1

Minor improvements, add connections for jumpers to completely disconnect the
transceiver module

### MoleNet v5.0

Redesign with the STM32L073RZT6 and an on-board SD-card interface,
well-optimized to low power applications.

### MoleNet v3.0

A redesign now based on the ATMEGA1284P, using an on board analog battery monitor, an MCP7940M RTC, improved SDI-12 interface, power enable pins etc.
This version offers more computing capabilities compared to the previous ones.

### MoleNet v2.1

Minor improvements for the SDI-12 sensor interface

### MoleNet v2.0

This version has additional GPIO (analog and digital) available. Further, the
EEPROM access has been improved.

### MoleNet v1.0

First version of MoleNet. This version is based on an ATMEGA328P-PU and is
programmed using the Arduino IDE. Further, it has an RFM69VW radio transceiver,
an EEPROM, an SDI-12 sensor interface and a connector for an external RV8523 RTC
module.

## Software

TODO

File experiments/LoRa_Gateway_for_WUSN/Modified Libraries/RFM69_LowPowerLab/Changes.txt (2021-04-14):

Changed line 110 in RFM69.cpp from SPI.begin() to SPI.begin(5,19,27,26)

Added uint8_t slaveSelectPin, uint8_t interruptPin, bool isRFM69HW to initialize

commented out some Settings between lines 485 and 492

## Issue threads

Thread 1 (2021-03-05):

replace SPIEEP

jdede, 2021-03-05:
The node lib for accessing the EEPROM uses an old version which is not supported / available any more. Replace this lib by a newer one.

jdede, 2021-06-30:
Connected to #5 : Use the lib to implement a proper ring buffer

jdede, 2025-05-12:
Outdated code, we focus on the ESP32-based boards.

Closed 2025-05-12.

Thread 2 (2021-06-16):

Check SDI-12 interface

jdede, 2021-06-16:
Depending on the SDI-12 sensor, the power consumption increases drastically. Check and fix

jdede, 2025-05-12:
Outdated hardware. We will not fix this issue as we focus on the ESP32-based boards.

Closed 2025-05-12.

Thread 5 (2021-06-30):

Packets not sent in order / packets missing

jdede, 2021-06-30:
Data packets are not properly resent after being stored in die EEPROM:

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

Solution: implement a proper ring buffer

jdede, 2025-05-12:
Outdated code, will not be fixed. We focus on the ESP32-S3-based MoleNet versions.

Closed 2025-05-12.

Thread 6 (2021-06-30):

Improvement of success code: always 1, convert success code to int

jdede, 2021-06-30:
The received success code is always `1` but should be different in case of a successful transmission, c.f. https://github.com/ComNets-Bremen/WUSN/blob/66d6b345920135b9d19f20454e2d9cff508c35cf/sources/MoleNet_1.0/MoleNet_node/MoleNet_node.ino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

    //suc == '0' : crc-check and transmission failed
    //suc == '1' : crc-check successful, but transmission failed
    //suc == '2' : crc-check failed, transmission successful
    //suc == '3' : crc-check and transmission successful

furthermore, the success code is handles as a char, not as an int.

jdede, 2025-05-12:
Outdated software. We focus on the ESP32-based versions of MoleNet

Closed 2025-05-12.

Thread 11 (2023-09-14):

Micropython: Is the SD-Card working?

jdede, 2023-09-14:

Wolfestin123, 2023-09-14:
If you're encountering errors and have come across SD card designs in TI reference designs, it's worth noting that some of them may not include populated or mounted pull-up resistors for the SD_CLK signal. To troubleshoot the issue further, you can try disabling or removing the pull-up resistor associated with the SD_CLK signal. This can be done by unmounting the SD_CLK pull-up resistor from the circuit.

FarukKollar, 2023-10-16:
Found problem in the Sd card connection in the schematics. Pin 7 and 8 was swapped according to reference designs. Corrected the pins. Afterwards checked with different size Sd cards to write and read, it works as expected. (Faruk&Karun)

B00mb0x, 2024-02-16:
Works for MoleNetv6

jdede, 2024-02-16:
Here is a MWE for MoleNetv6 & Python.

```
import machine, os
sd = machine.SDCard(slot=2, sck=machine.Pin(12), miso=machine.Pin(13), mosi=machine.Pin(11), cs=machine.Pin(10))
sd.info()
os.mount(sd, "/sd")
os.listdir('/sd')
os.umount("/sd")
```

Closed 2024-02-16.

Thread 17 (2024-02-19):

MoleNetv6: Arduino testing

jdede, 2024-02-19:
Test the following things:

- [ ] Upload
- [ ] Blinking
- [ ] Debug output
- [ ] RTC
- [ ] SD-card
- [ ] SDI-12
- [ ] LoRa
- [ ] Low power / wakeup

jdede, 2025-05-12:
I think there were some examples for Arduino, but I can not find them in the repo. @B00mb0x , @FarukKollar  do you know where they are?

B00mb0x, 2025-05-13:
@jdede I have only ever worked with MicroPython, so unfortunately no.

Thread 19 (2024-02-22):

Low power / wakeup

Wolfestin123, 2024-02-22:

jdede, 2024-02-22:
Please add some content: Is the low power working or failing?

Wolfestin123, 2024-02-29:
The power consumption measurement of MoleNet V6 is attached in the pdf below.
[MoleNet - V6_power_consumption.pdf](https://github.com/ComNets-Bremen/WUSN/files/14448364/MoleNet.-.V6_power_consumption.pdf)
The code used :
`
from machine import deepsleep
from machine import lightsleep
from time import sleep

print('Im awake. Going to sleep in 10 seconds')
sleep(10)
print('Going to 10 sec light sleep now')
lightsleep(10000)
sleep(10)
print('Going to 10 sec deep sleep now')
deepsleep(10000)

`

jdede, 2024-02-29:
2 mA with LoRa and SD powered up is too high. Please set the LoRa-module into deep sleep mode and check the current drawn by the pull-up resistors.

Wolfestin123, 2024-04-03:
I have put the LoRa module to sleep and measured the current consumption. The results indicate a reduction in current consumption of the LoRa chip (RA-01H) by **2mA** during sleep. Please find the attached code and results for reference.
[MoleNet - V6_power_consumption_with_LORA_sleep.pdf](https://github.com/ComNets-Bremen/WUSN/files/14852768/MoleNet.-.V6_power_consumption_with_LORA_sleep.pdf)

`import LoRaSender
import LoRaReceiver

from config import *
from machine import Pin, SPI, SoftSPI
from sx127x import SX127x
from machine import lightsleep
from time import sleep
from machine import deepsleep

device_spi = SoftSPI(
    baudrate = 200000,
    polarity = 0, phase = 0, bits = 8, firstbit = SPI.MSB,
    sck = Pin(device_config['sck'], Pin.OUT, Pin.PULL_DOWN),
    mosi = Pin(device_config['mosi'], Pin.OUT, Pin.PULL_UP),
    miso = Pin(device_config['miso'], Pin.IN, Pin.PULL_UP))

Pin(device_config['reset'], Pin.OUT, value=1)
lora = SX127x(device_spi, pins=device_config, parameters=lora_parameters)

print("going to light sleep")

lightsleep(10000) # 10 seconds light sleep
print("lora on")
sleep(20)

lora.sleep()  # Lora is on sleep mode
print("lora off")

lightsleep(10000) # 10 seconds light sleep

deepsleep(20000) # 20 seconds deep sleep

`

jdede, 2025-05-12:
Correct me if I'm wrong: The reason for this issue was the wrong voltage regulator. With the newer version, this should be fine. @Wolfestin123 @FarukKollar @B00mb0x can you confirm?

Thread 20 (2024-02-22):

One SPI for LoRa and SD?

jdede, 2024-02-22:
Right now, we use two SPI for the SD and the LoRa. Is it possible to use a shared SPI? Please evaluate:

- Any drawbacks regarding performance?
- SPI speed compatible?
- Other restrictions?

Maybe we can combine MOSI, MISO, SCK of both and get three additional pins for the next board?

B00mb0x, 2024-02-22:
-     Other restrictions?
 The builtin SDCard library doesn't return the SPI object. So in order to use SD and LoRa on the same SPI you have to either sideload an old SDCard library written in micropython or terminate the SPI connection after each usage.

jdede, 2025-05-12:
Okay, so we keep it as it is. Thanks for taking care :-)

Closed 2025-05-12.

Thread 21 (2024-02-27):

Add an BME280?

jdede, 2024-02-27:
Does it make sense to add an BME280 (temp, hum, pressure) to the board:

- high quality and low power sensor
- good to monitor the inside conditions of the board
- Easy start with some hardware directly attached to the board

What do you think @B00mb0x @FarukKollar @Wolfestin123 ? Alternative ideas?

Wolfestin123, 2024-02-27:
In my suggestion Utilizing the BME280 sensor in I2C mode would be advantageous as it avoids potential hardware limitations. Additionally, its low sleep and standby current consumption (less than 1 µA) enhances its suitability for this application.

FarukKollar, 2024-02-28:
I also think it is a good idea. We can use on board sensor for test and possible troubleshooting in future. We can add jumpers to the pins and left it connected if we want to observe the condition of the board under ground, otherwise we can disconnect by removing jumpers.

Closed 2025-04-17.

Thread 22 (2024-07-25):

Missing resistor for LoRa interface

jdede, 2024-07-25:
Karun just reminded me: We require an additional resistor for LoRa. Right now, this is fixed in Software. Did someone take care of this?

FarukKollar, 2025-04-04:
It is added for the next version of board.

Closed 2025-04-17.

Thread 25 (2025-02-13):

Check size of mounting holes

jdede, 2025-02-13:
They seem to bee quite narrow with 2.2mm

FarukKollar, 2025-04-04:
You're right. I increased the mounting hole size to 3.2mm for the nest versions.

Closed 2025-04-17.

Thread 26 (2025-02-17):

Add Information for headers and power + & - on silkscreen

Hawkeye-253481, 2025-02-17:
Some headers are "upside down" in comparison to the shematic. For the power terminal maybe add + & - and also the possible input voltage range if it gets to small maybe put that information on the backside

FarukKollar, 2025-04-04:
@Hawkeye-253481 , I am not sure what do you mean by headers are "upside down"?
I already added the + & - signs for the ordered V6.2. I will try to fit the voltage range as well for the next version.

Closed 2025-04-17.

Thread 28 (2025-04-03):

check labels für led D6

jdede, 2025-04-03:
-  Label D6: GPIO_9_LED
-  J5: Mapping to GPIO_38

-> Please adapt the labels für D6 accordingly. Also X-check the others.

FarukKollar, 2025-04-17:
Labels are corrected.

Closed 2025-04-17.

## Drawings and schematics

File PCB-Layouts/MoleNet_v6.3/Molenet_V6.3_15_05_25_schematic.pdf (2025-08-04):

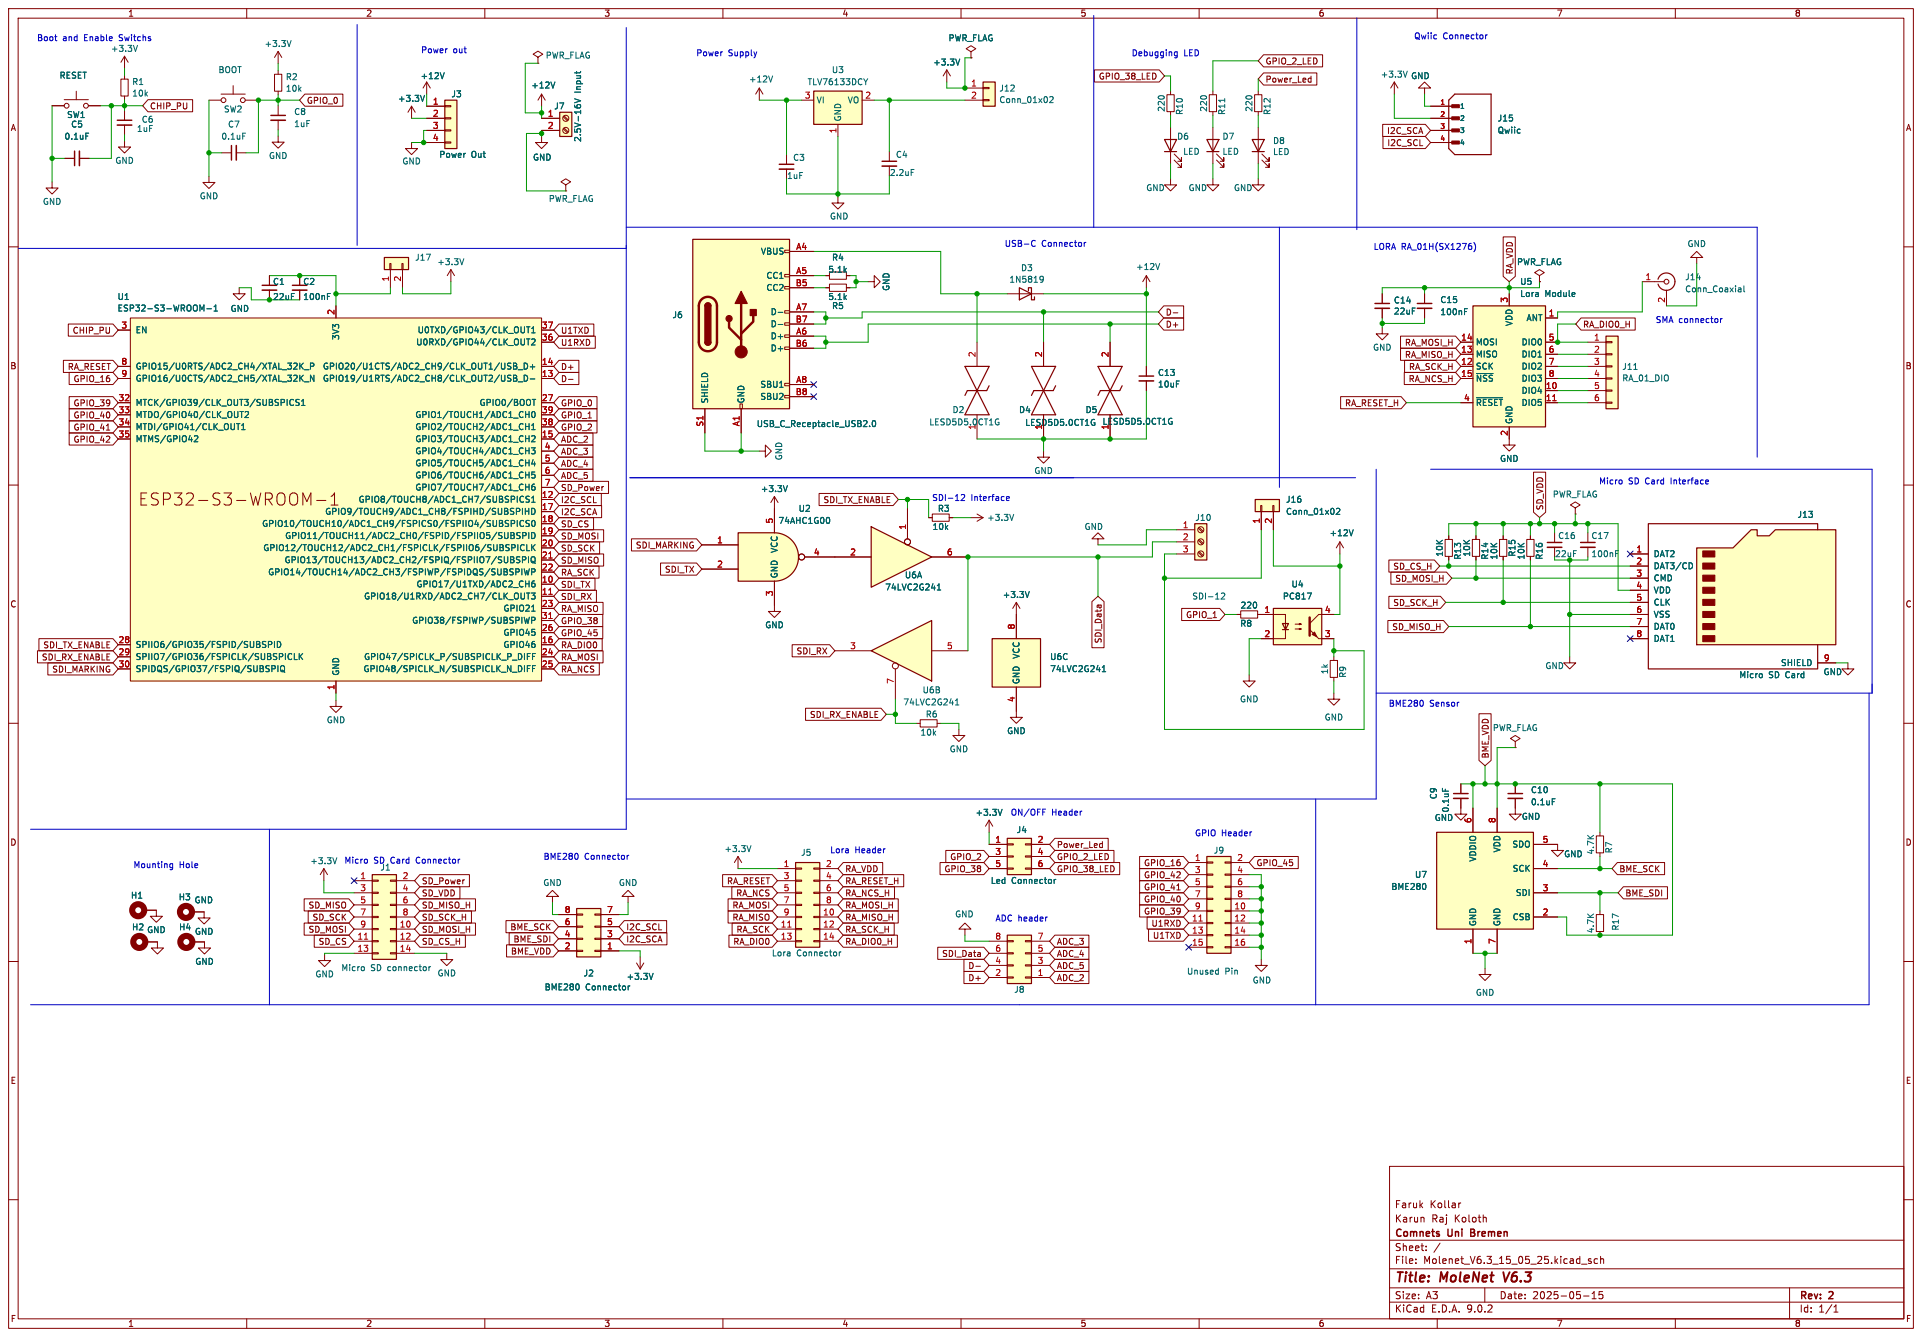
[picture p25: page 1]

Boot and Enable Switchs

1 U0TXD/GPIO43/CLK_OUT1 37 U0RXD/GPIO44/CLK_OUT2 36 GPIO20/U1CTS/ADC2_CH9/CLK_OUT1/USB_D+ 14 GPIO19/U1RTS/ADC2_CH8/CLK_OUT2/USB_D- 13 GPIO0/BOOT 27 GPIO1/TOUCH1/ADC1_CH0 39 GPIO2/TOUCH2/ADC1_CH1 38 GPIO3/TOUCH3/ADC1_CH2 15 GPIO4/TOUCH4/ADC1_CH3 4 GPIO5/TOUCH5/ADC1_CH4 5 GPIO6/TOUCH6/ADC1_CH5 6 GPIO7/TOUCH7/ADC1_CH6 7 GPIO8/TOUCH8/ADC1_CH7/SUBSPICS1 12 GPIO9/TOUCH9/ADC1_CH8/FSPIHD/SUBSPIHD 17 GPIO10/TOUCH10/ADC1_CH9/FSPICS0/FSPIIO4/SUBSPICS0 18 GPIO11/TOUCH11/ADC2_CH0/FSPID/FSPIIO5/SUBSPID 19 GPIO12/TOUCH12/ADC2_CH1/FSPICLK/FSPIIO6/SUBSPICLK 20 GPIO13/TOUCH13/ADC2_CH2/FSPIQ/FSPIIO7/SUBSPIQ 21 GPIO14/TOUCH14/ADC2_CH3/FSPIWP/FSPIDQS/SUBSPIWP 22 GPIO17/U1TXD/ADC2_CH6 10 GPIO18/U1RXD/ADC2_CH7/CLK_OUT3 11 GPIO21 23 GPIO38/FSPIWP/SUBSPIWP 31 GPIO45 26 GPIO46 16 GPIO47/SPICLK_P/SUBSPICLK_P_DIFF 24 GPIO48/SPICLK_N/SUBSPICLK_N_DIFF 25 U1ESP32-S3-WROOM-1 GND GND GND GND
GND ESP32-S3-WROOM-1

1 U0TXD/GPIO43/CLK_OUT1 37 U0RXD/GPIO44/CLK_OUT2 36 GPIO20/U1CTS/ADC2_CH9/CLK_OUT1/USB_D+ 14 GPIO19/U1RTS/ADC2_CH8/CLK_OUT2/USB_D- 13 GPIO0/BOOT 27 GPIO1/TOUCH1/ADC1_CH0 39 GPIO2/TOUCH2/ADC1_CH1 38 GPIO3/TOUCH3/ADC1_CH2 15 GPIO4/TOUCH4/ADC1_CH3 4 GPIO5/TOUCH5/ADC1_CH4 5 GPIO6/TOUCH6/ADC1_CH5 6 GPIO7/TOUCH7/ADC1_CH6 7 GPIO8/TOUCH8/ADC1_CH7/SUBSPICS1 12 GPIO9/TOUCH9/ADC1_CH8/FSPIHD/SUBSPIHD 17 GPIO10/TOUCH10/ADC1_CH9/FSPICS0/FSPIIO4/SUBSPICS0 18 GPIO11/TOUCH11/ADC2_CH0/FSPID/FSPIIO5/SUBSPID 19 GPIO12/TOUCH12/ADC2_CH1/FSPICLK/FSPIIO6/SUBSPICLK 20 GPIO13/TOUCH13/ADC2_CH2/FSPIQ/FSPIIO7/SUBSPIQ 21 GPIO14/TOUCH14/ADC2_CH3/FSPIWP/FSPIDQS/SUBSPIWP 22 GPIO17/U1TXD/ADC2_CH6 10 GPIO18/U1RXD/ADC2_CH7/CLK_OUT3 11 GPIO21 23 GPIO38/FSPIWP/SUBSPIWP 31 GPIO45 26 GPIO46 16 GPIO47/SPICLK_P/SUBSPICLK_P_DIFF 24 GPIO48/SPICLK_N/SUBSPICLK_N_DIFF 25 H2 H4 GND

J13 Micro SD Card GND

7 SDO 5 SCK 4 SDI 3 CSB 2 U7 BME280 C10

7 SDO 5 SCK 4 SDI 3 CSB 2 C10

ON/OFF Header ADC header

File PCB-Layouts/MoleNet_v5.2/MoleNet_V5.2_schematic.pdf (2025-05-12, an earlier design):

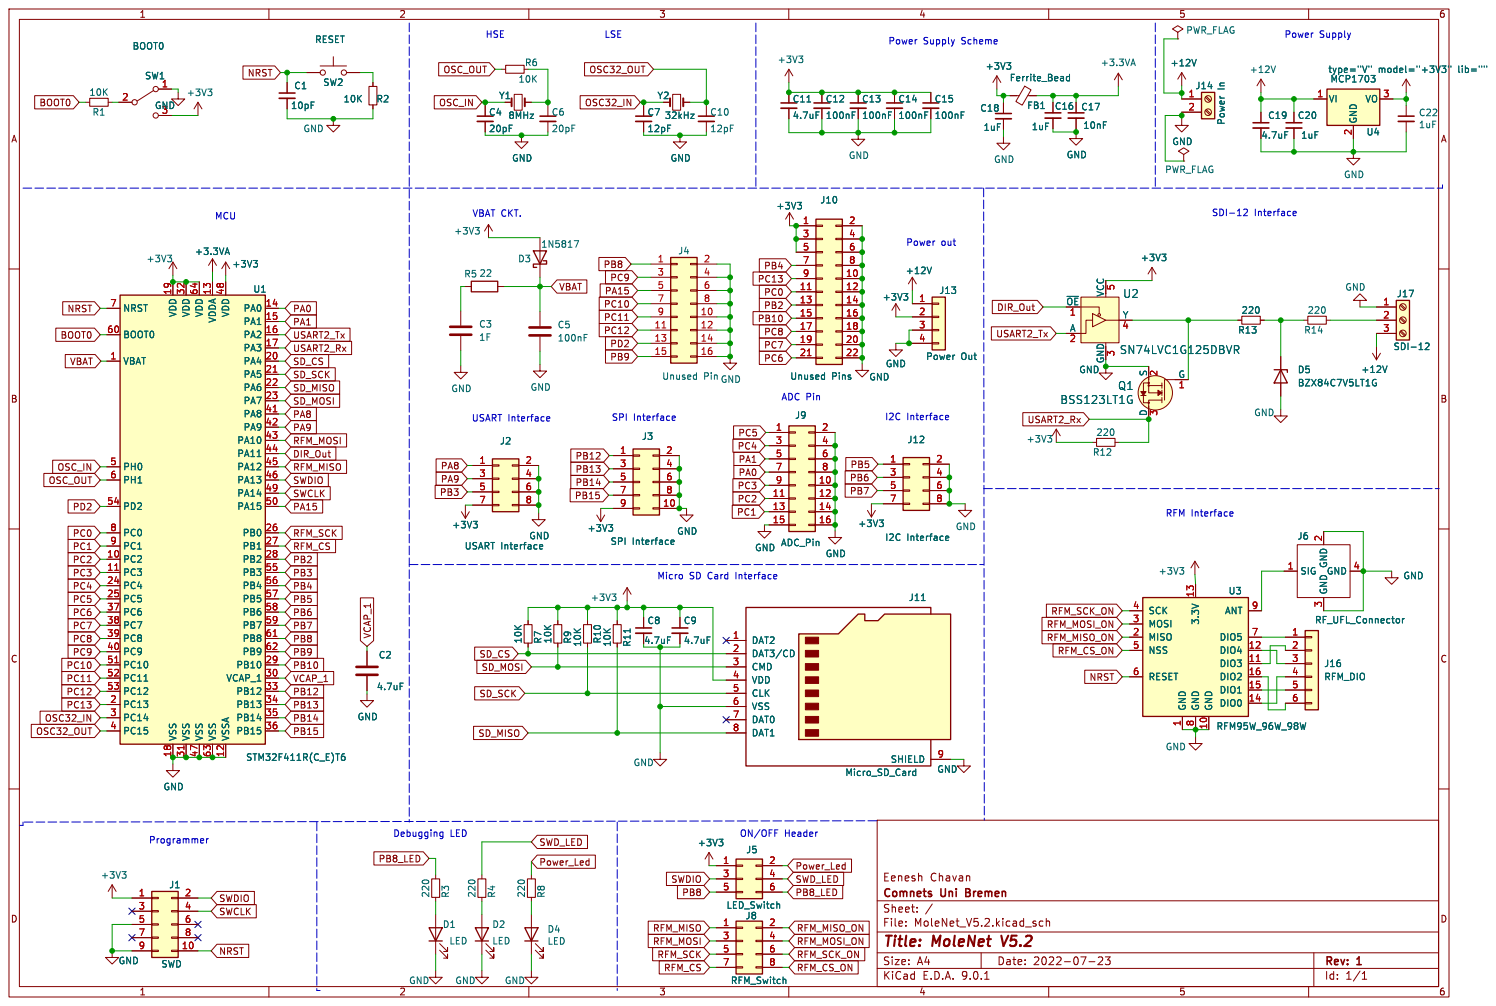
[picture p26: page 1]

Power Supply Power Supply Scheme

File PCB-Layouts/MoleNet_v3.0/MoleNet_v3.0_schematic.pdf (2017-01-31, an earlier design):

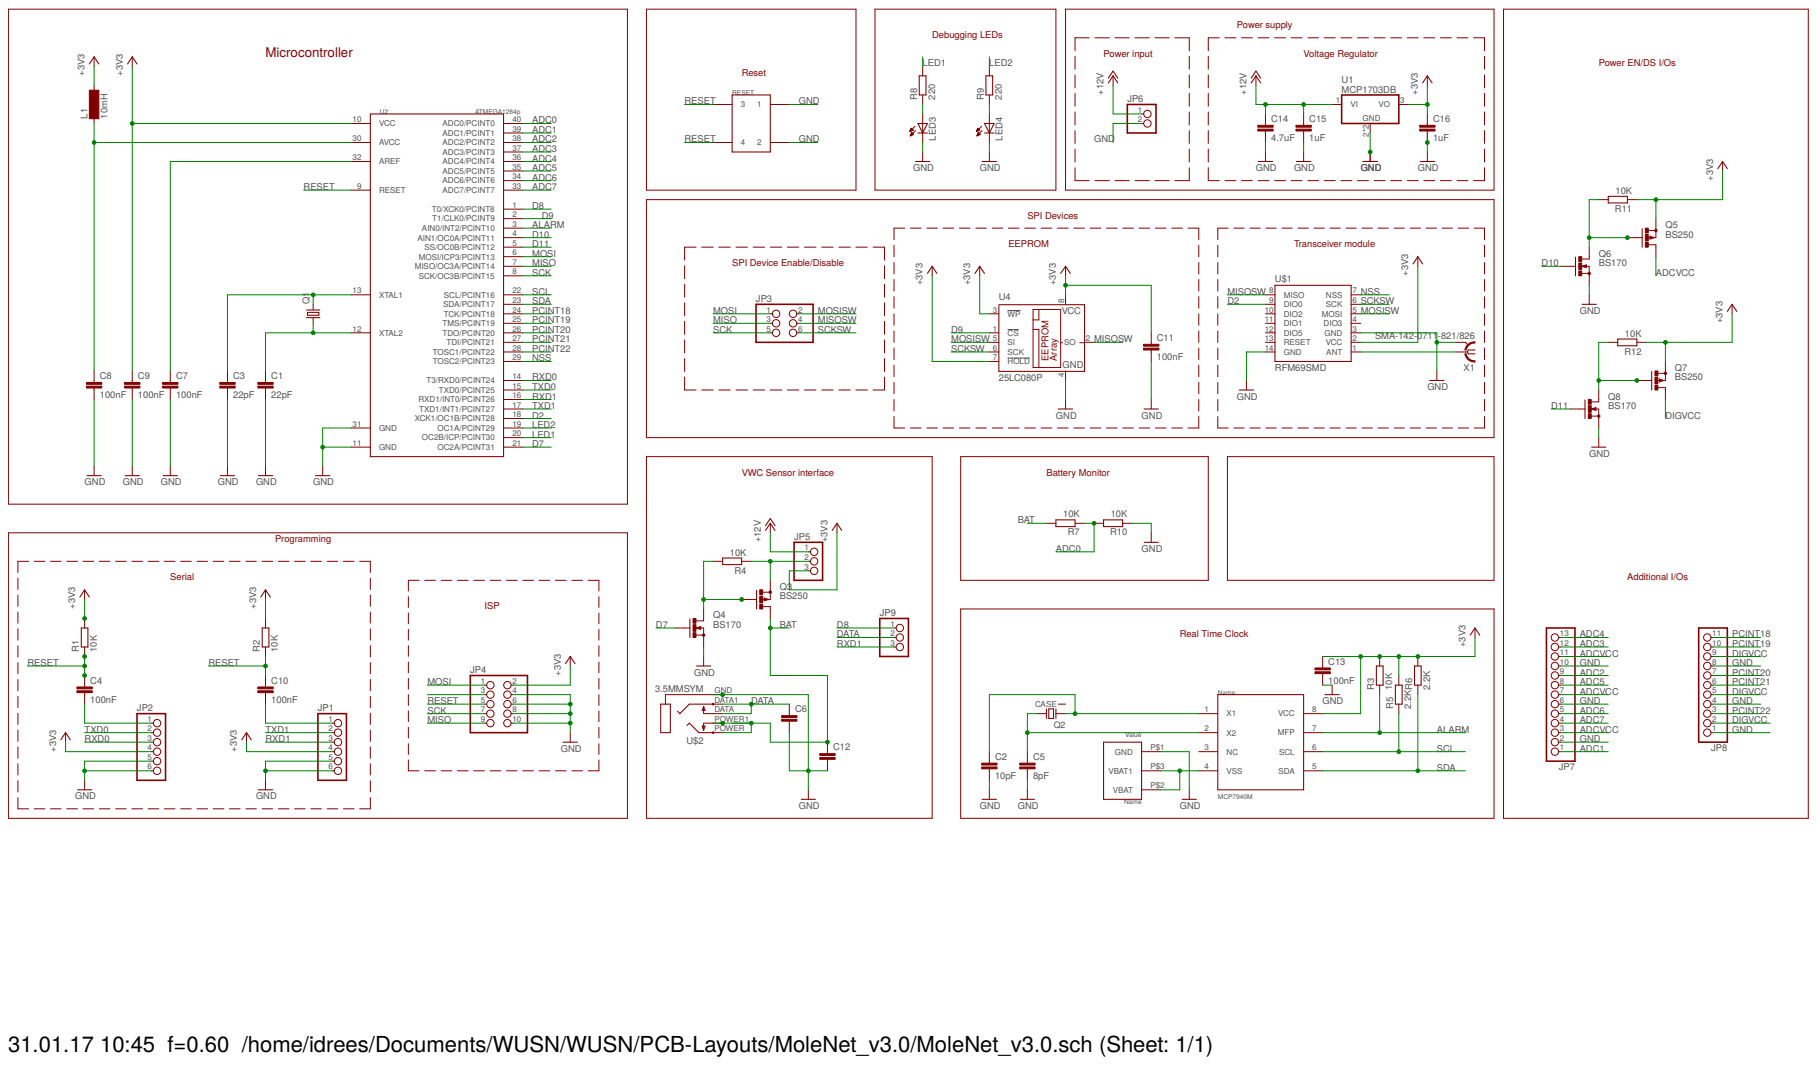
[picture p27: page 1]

Power EN/DS I/Os

31.01.17 10:45 f=0.60 /home/idrees/Documents/WUSN/WUSN/PCB-Layouts/MoleNet_v3.0/MoleNet_v3.0.sch (Sheet: 1/1)

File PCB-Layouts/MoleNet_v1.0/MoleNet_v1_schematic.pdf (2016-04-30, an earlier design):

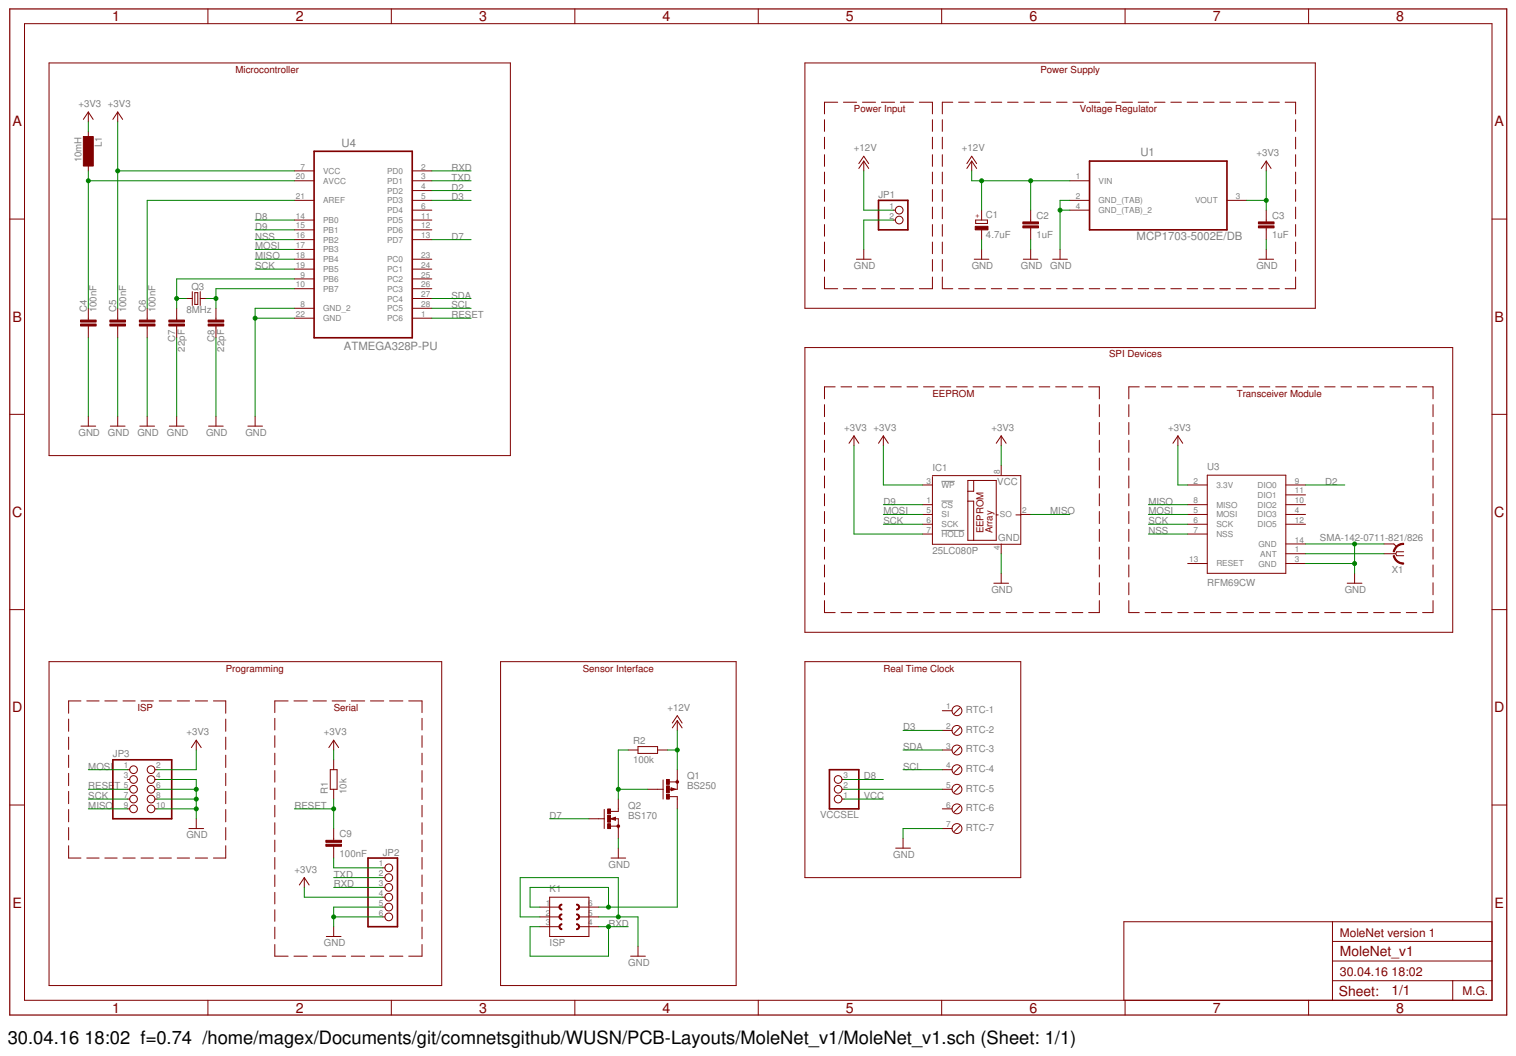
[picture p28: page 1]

4 | GND

MoleNet version 1

30.04.16 18:02 f=0.74 /home/magex/Documents/git/comnetsgithub/WUSN/PCB-Layouts/MoleNet_v1/MoleNet_v1.sch (Sheet: 1/1)

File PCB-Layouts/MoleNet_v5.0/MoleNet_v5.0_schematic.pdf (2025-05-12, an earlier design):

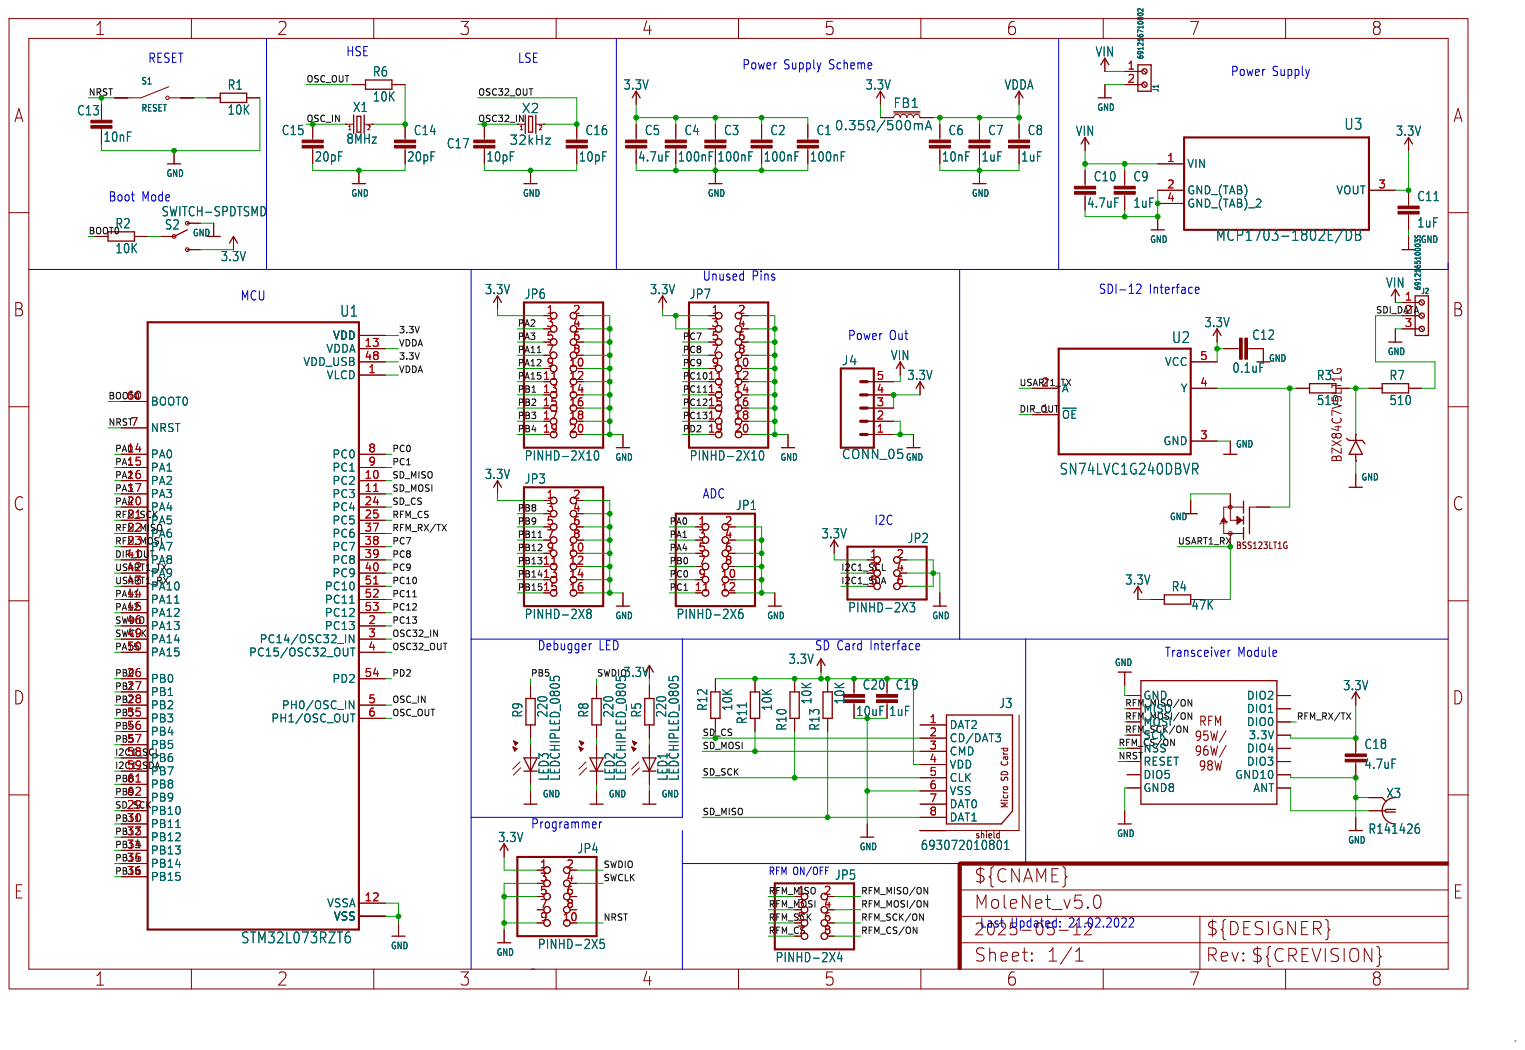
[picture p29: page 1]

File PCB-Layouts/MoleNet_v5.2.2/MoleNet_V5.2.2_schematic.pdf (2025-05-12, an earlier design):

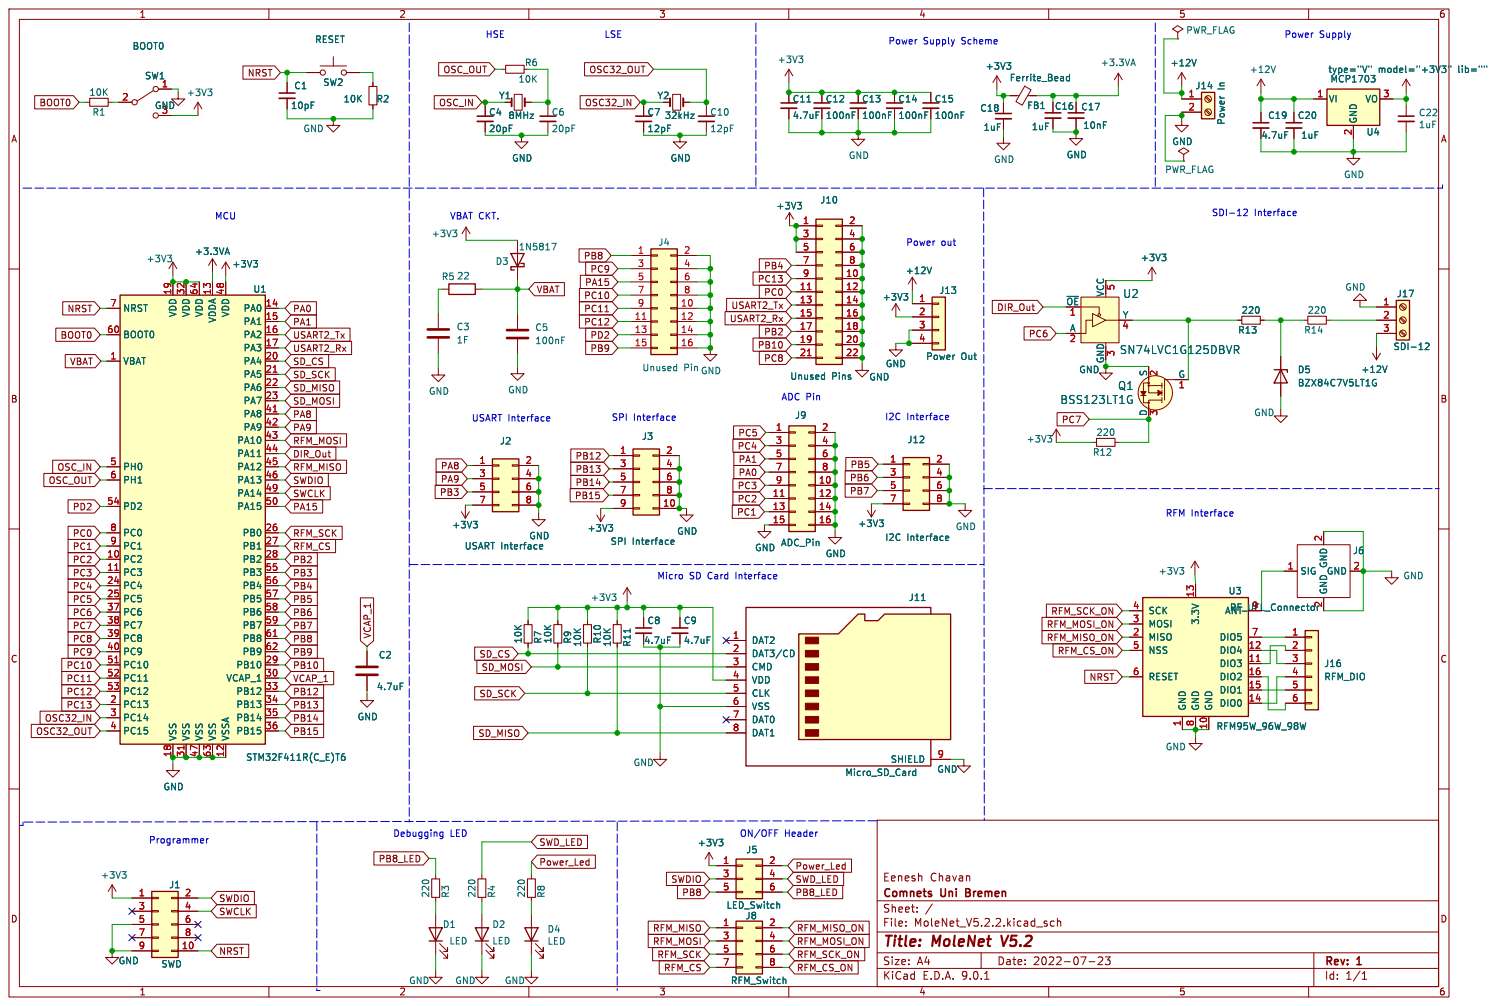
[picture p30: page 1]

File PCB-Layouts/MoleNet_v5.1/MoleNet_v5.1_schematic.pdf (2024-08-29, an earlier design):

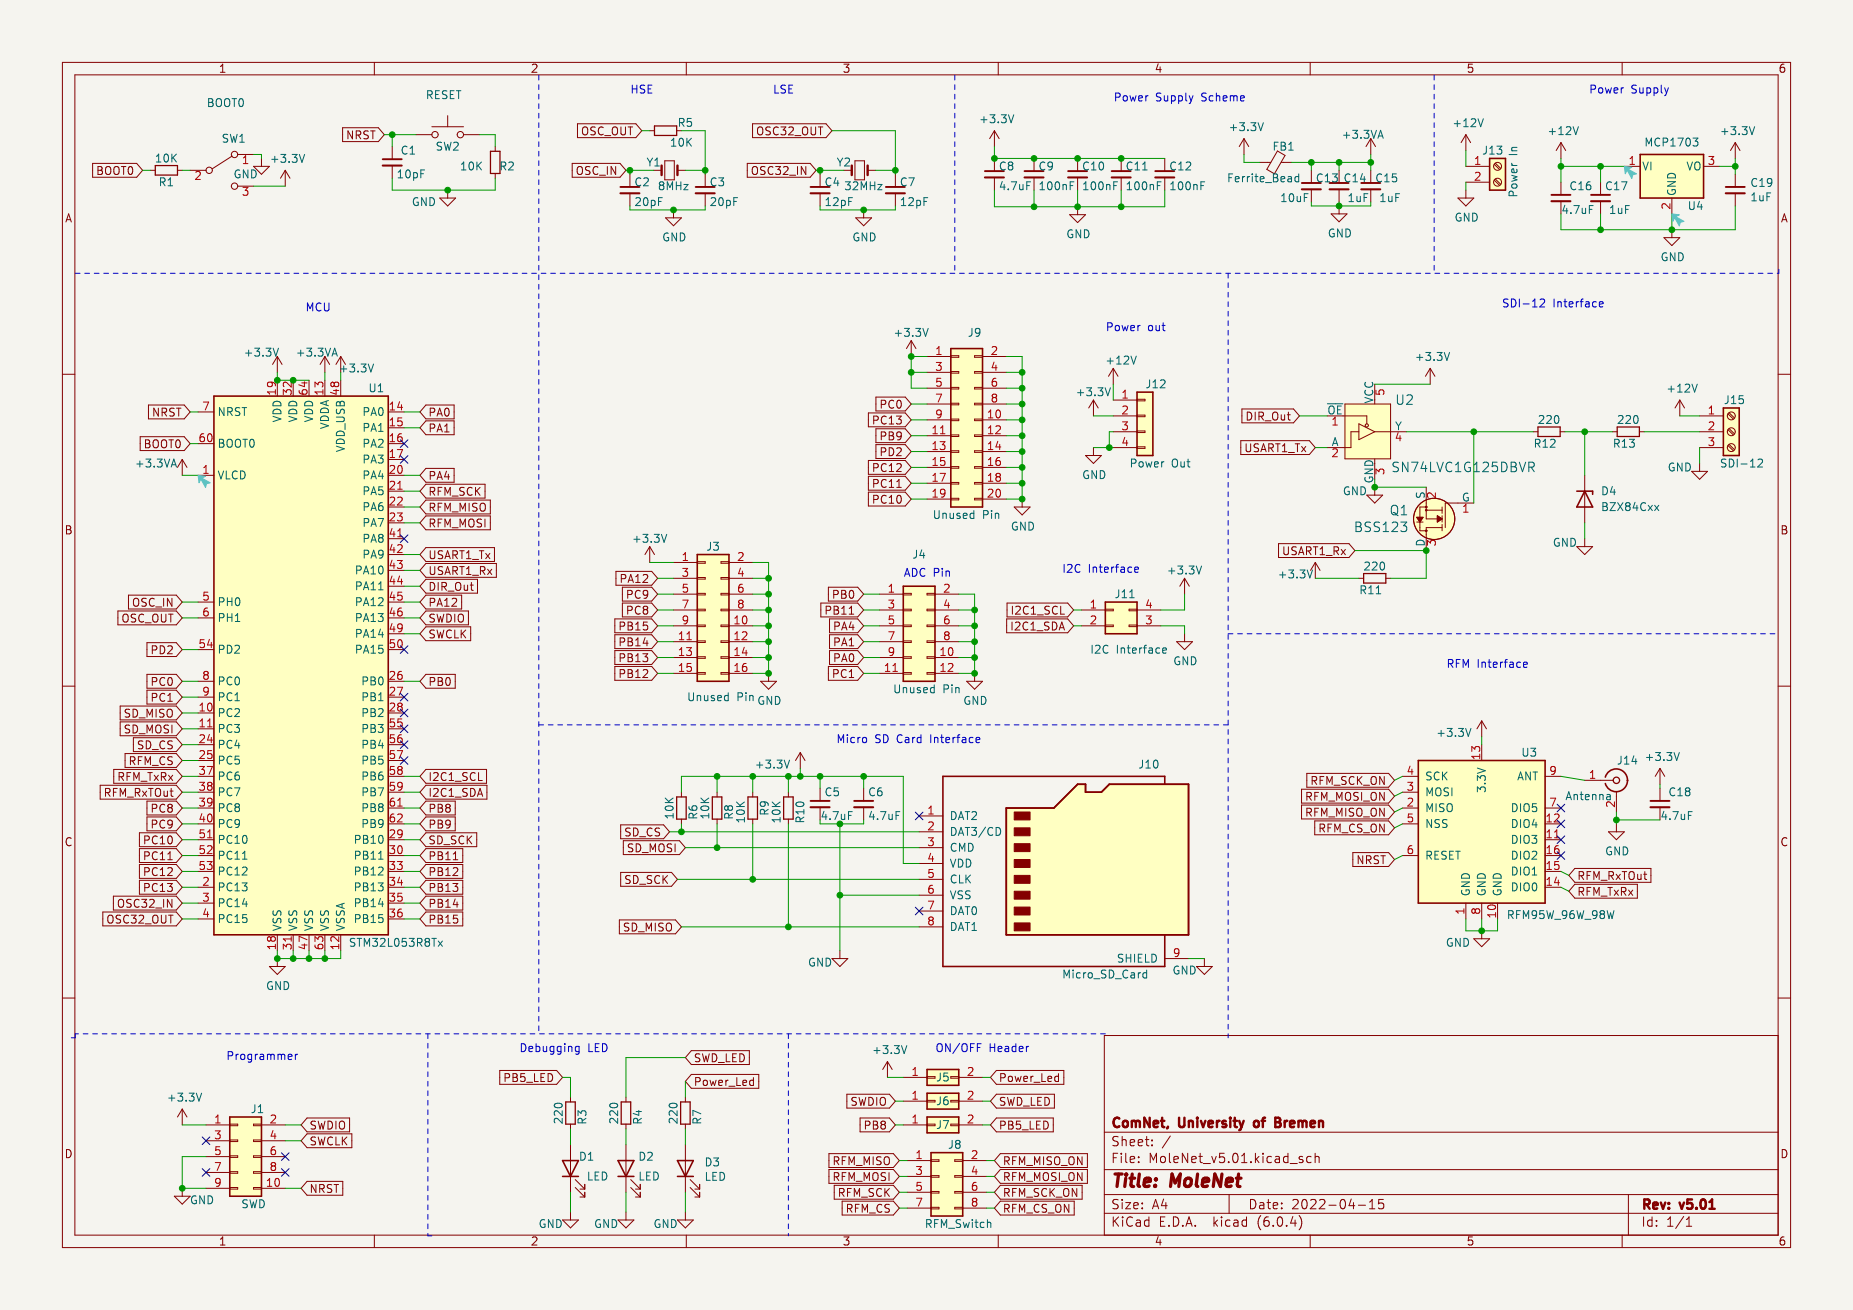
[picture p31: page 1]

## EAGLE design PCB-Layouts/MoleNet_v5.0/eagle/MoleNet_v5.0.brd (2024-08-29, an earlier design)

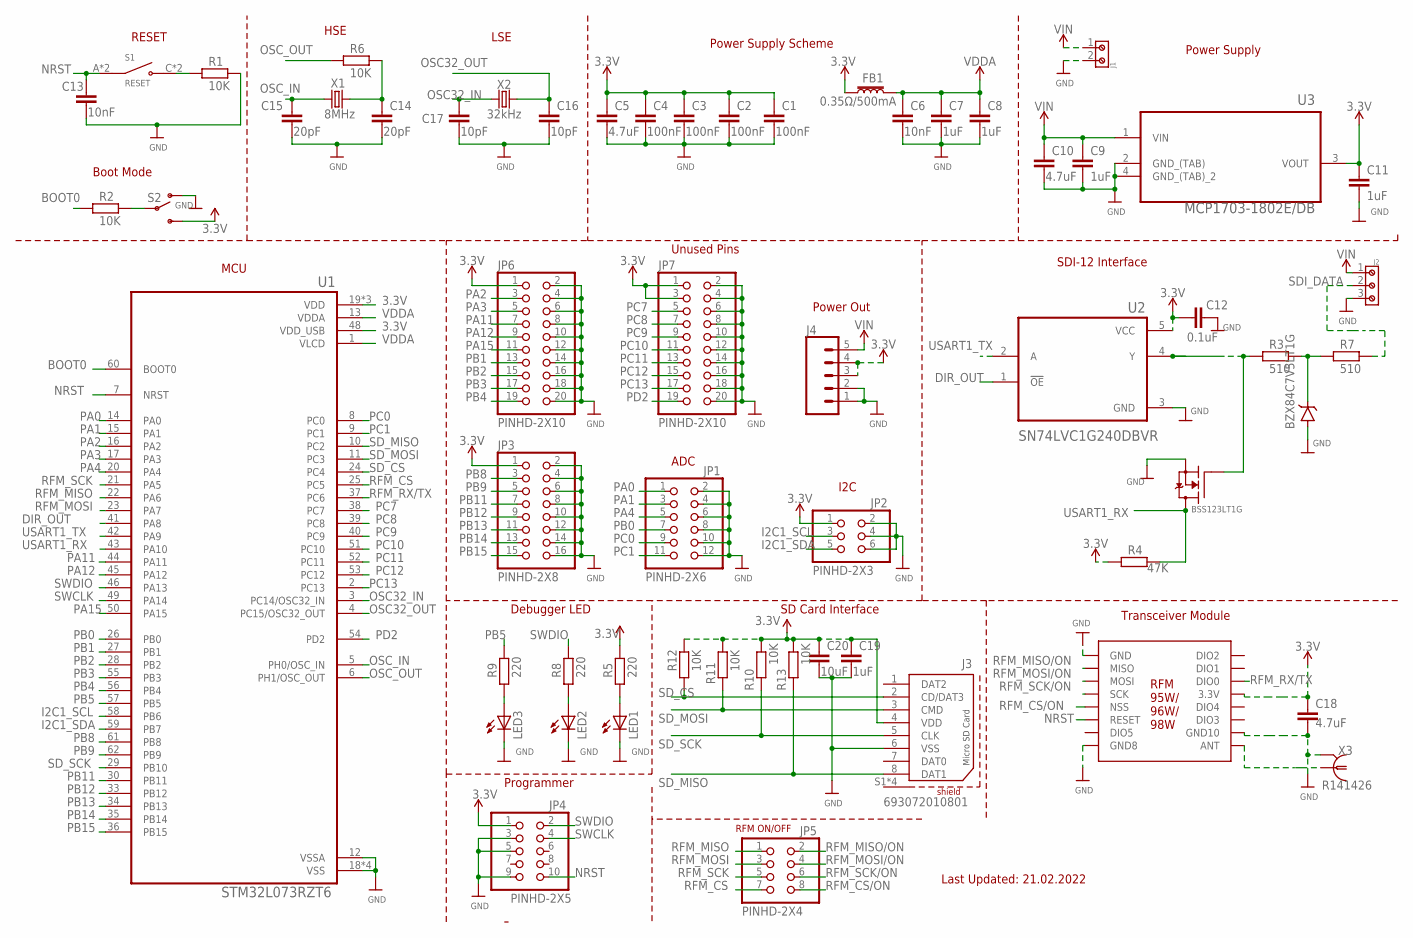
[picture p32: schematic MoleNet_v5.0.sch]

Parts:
C1, C2, C3, C4: 100nF; C0805
C5, C10, C18: 4.7uF; C0805
C6, C13: 10nF; C0805
C7, C8, C9, C11, C19: 1uF; C0805
C12: 0.1uF; C0805
C14, C15: 20pF; C0805
C16, C17: 10pF; C0805
C20: 10uF; C0805
FB1: 0.35Ω/500mA; 0603
J1: 691216710002
J2: 691216510003S
J3: 693072010801
J4: CONN_05; 1X05
JP1: PINHD-2X6; 2X06
JP2: PINHD-2X3; 2X03
JP3: PINHD-2X8; 2X08
JP4: PINHD-2X5; 2X05
JP5: PINHD-2X4; 2X04
JP6, JP7: PINHD-2X10; 2X10
LED1, LED2, LED3: LEDCHIPLED_0805; CHIPLED_0805
R1, R2, R6, R10, R11, R12, R13: 10K; R0805
R3, R7: 510; R0805
R4: 47K; R0805
R5, R8, R9: 220; R0805
S1: RESET; SW_TS-1187A-B-A-B
S2: SWITCH-SPDTSMD; SWITCH_SPDT_SMD
U1: STM32L073RZT6; QFP50P1200X1200X160-64N
U2: SN74LVC1G240DBVR; SOT95P280X145-5N
U3: MCP1703-1802E/DB; SOT230P700X180-4N
U$18: RFM95W/96W/98W
U$32: BSS123LT1G_STYLE-21; BZX84C7V5LT1G
U$34: BZX84C7V5LT1G_STYLE-8; BZX84C7V5LT1G
X1: 8MHz; HC49/S
X2: 32kHz; CRYSTAL-SMD-3.2X1.5MM
X3: R141426

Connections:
3.3V: C1.1, C2.1, C3.1, C4.1, C5.1, C11.1, C12.2, C18.1, C19.1, C20.1, FB1.1, J3.4 (VDD), J4.3, J4.4, JP2.1, JP3.1, JP4.1, JP6.1, JP7.1, JP7.3, R4.1, R5.2, R10.2, R11.2, R12.2, R13.2, S2.3 (S), U1.19 (VDD), U1.32 (VDD), U1.48 (VDD_USB), U1.64 (VDD), U2.5 (VCC), U3.3 (VOUT), U$18.13 (3.3V)
BOOT0: R2.1, U1.60 (BOOT0)
DIR_OUT: U1.41 (PA8), U2.1 (!OE)
GND: C1.2, C2.2, C3.2, C4.2, C5.2, C6.2, C7.2, C8.2, C9.2, C10.2, C11.2, C12.1, C13.2, C14.2, C15.2, C16.2, C17.2, C18.2, C19.2, C20.2, J1.2, J2.3, J3.6 (VSS), J4.1, J4.2, JP1.2, JP1.4, JP1.6, JP1.8, JP1.10, JP1.12, JP2.2, JP2.4, JP2.6, JP3.2, JP3.4, JP3.6, JP3.8, JP3.10, JP3.12, JP3.14, JP3.16, JP4.3, JP4.5, JP4.9, JP6.2, JP6.4, JP6.6, JP6.8, JP6.10, JP6.12, JP6.14, JP6.16, JP6.18, JP6.20, JP7.2, JP7.4, JP7.6, JP7.8, JP7.10, JP7.12, JP7.14, JP7.16, JP7.18, JP7.20, LED1.C, LED2.C, LED3.C, R1.2, S2.1 (O), U1.12 (VSSA), U1.18 (VSS), U1.31 (VSS), U1.47 (VSS), U1.63 (VSS), U2.3 (GND), U3.2 (GND_(TAB)), U3.4 (GND_(TAB)_2), U$18.1 (GND), U$18.8 (GND8), U$18.10 (GND10), U$32.P$2 (S), U$34.P$1 (A), X3.2, X3.3 (2), X3.4 (2), X3.5 (2)
I2C1_SCL: JP2.3, U1.58 (PB6)
I2C1_SDA: JP2.5, U1.59 (PB7)
unnamed: R1.1, S1.C (NO), S1.D (NO)
unnamed: R3.2, R7.1, U$34.P$3 (C)
unnamed: R3.1, U2.4 (Y), U$32.P$1 (G)
unnamed: R2.2, S2.2
unnamed: C14.1, R6.2, X1.2
unnamed: U$18.9 (ANT), X3.1
unnamed: LED1.A, R5.1
unnamed: LED2.A, R8.1
unnamed: LED3.A, R9.1
NRST: C13.1, JP4.10, S1.A (COM), S1.B (COM), U1.7 (NRST), U$18.6 (RESET)
OSC32_IN: C17.1, U1.3 (PC14/OSC32_IN), X2.P$1 (1)
OSC32_OUT: C16.1, U1.4 (PC15/OSC32_OUT), X2.P$2 (2)
OSC_IN: C15.1, U1.5 (PH0/OSC_IN), X1.1
OSC_OUT: R6.1, U1.6 (PH1/OSC_OUT)
PA0: JP1.1, U1.14 (PA0)
PA1: JP1.3, U1.15 (PA1)
PA2: JP6.3, U1.16 (PA2)
PA3: JP6.5, U1.17 (PA3)
PA4: JP1.5, U1.20 (PA4)
PA11: JP6.7, U1.44 (PA11)
PA12: JP6.9, U1.45 (PA12)
PA15: JP6.11, U1.50 (PA15)
PB0: JP1.7, U1.26 (PB0)
PB1: JP6.13, U1.27 (PB1)
PB2: JP6.15, U1.28 (PB2)
PB3: JP6.17, U1.55 (PB3)
PB4: JP6.19, U1.56 (PB4)
PB5: R9.2, U1.57 (PB5)
PB8: JP3.3, U1.61 (PB8)
PB9: JP3.5, U1.62 (PB9)
PB11: JP3.7, U1.30 (PB11)
PB12: JP3.9, U1.33 (PB12)
PB13: JP3.11, U1.34 (PB13)
PB14: JP3.13, U1.35 (PB14)
PB15: JP3.15, U1.36 (PB15)
PC0: JP1.9, U1.8 (PC0)
PC1: JP1.11, U1.9 (PC1)
PC7: JP7.5, U1.38 (PC7)
PC8: JP7.7, U1.39 (PC8)
PC9: JP7.9, U1.40 (PC9)
PC10: JP7.11, U1.51 (PC10)
PC11: JP7.13, U1.52 (PC11)
PC12: JP7.15, U1.53 (PC12)
PC13: JP7.17, U1.2 (PC13)
PD2: JP7.19, U1.54 (PD2)
RFM_CS: JP5.7, U1.25 (PC5)
RFM_CS/ON: JP5.8, U$18.5 (NSS)
RFM_MISO: JP5.1, U1.22 (PA6)
RFM_MISO/ON: JP5.2, U$18.2 (MISO)
RFM_MOSI: JP5.3, U1.23 (PA7)
RFM_MOSI/ON: JP5.4, U$18.3 (MOSI)
RFM_RX/TX: U1.37 (PC6), U$18.14 (DIO0)
RFM_SCK: JP5.5, U1.21 (PA5)
RFM_SCK/ON: JP5.6, U$18.4 (SCK)
SDI_DATA: J2.2, R7.2
SD_CS: J3.2 (CD/DAT3), R12.1, U1.24 (PC4)
SD_MISO: J3.8 (DAT1), R13.1, U1.10 (PC2)
SD_MOSI: J3.3 (CMD), R11.1, U1.11 (PC3)
SD_SCK: J3.5 (CLK), R10.1, U1.29 (PB10)
SWCLK: JP4.4, U1.49 (PA14)
SWDIO: JP4.2, R8.2, U1.46 (PA13)
USART1_RX: R4.2, U1.43 (PA10), U$32.P$3 (D)
USART1_TX: U1.42 (PA9), U2.2 (A)
VDDA: C6.1, C7.1, C8.1, FB1.2, U1.1 (VLCD), U1.13 (VDDA)
VIN: C9.1, C10.1, J1.1, J2.1, J4.5, U3.1 (VIN)

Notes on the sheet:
Last Updated: 21.02.2022
RFM ON/OFF
SDI-12 Interface
MCU
Power Supply
HSE
LSE
Boot Mode
RESET
Power Supply Scheme
Transceiver Module
Programmer
SD Card Interface
ADC
I2C
Power Out
Unused Pins
Debugger LED

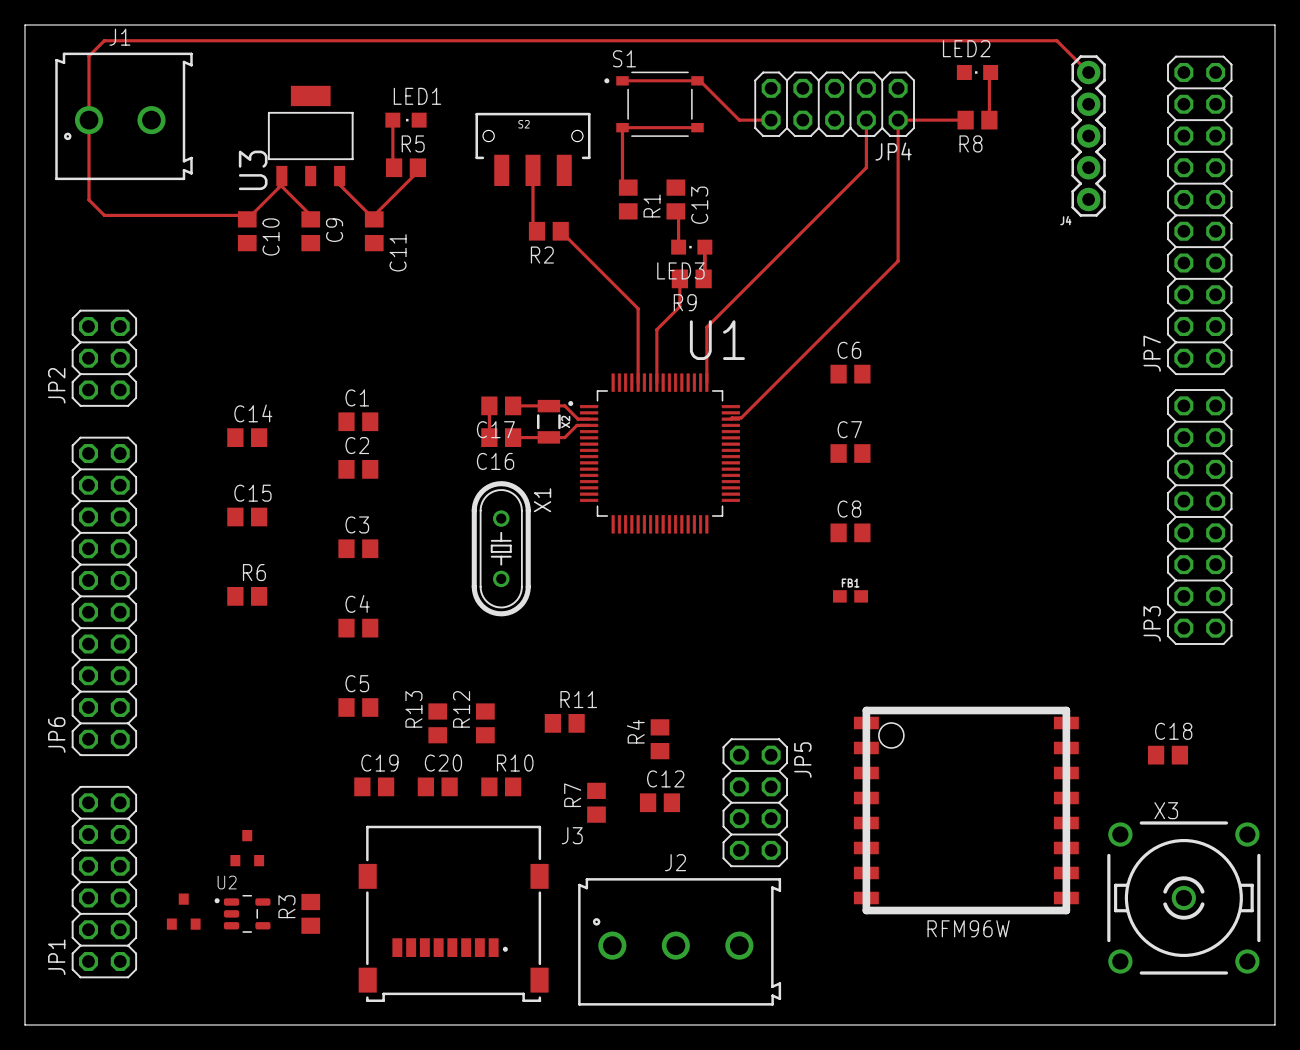
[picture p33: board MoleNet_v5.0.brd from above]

Board: 2 copper layers, 100.0 x 80.0 mm, 59 parts (0 on the bottom side), 71 nets.

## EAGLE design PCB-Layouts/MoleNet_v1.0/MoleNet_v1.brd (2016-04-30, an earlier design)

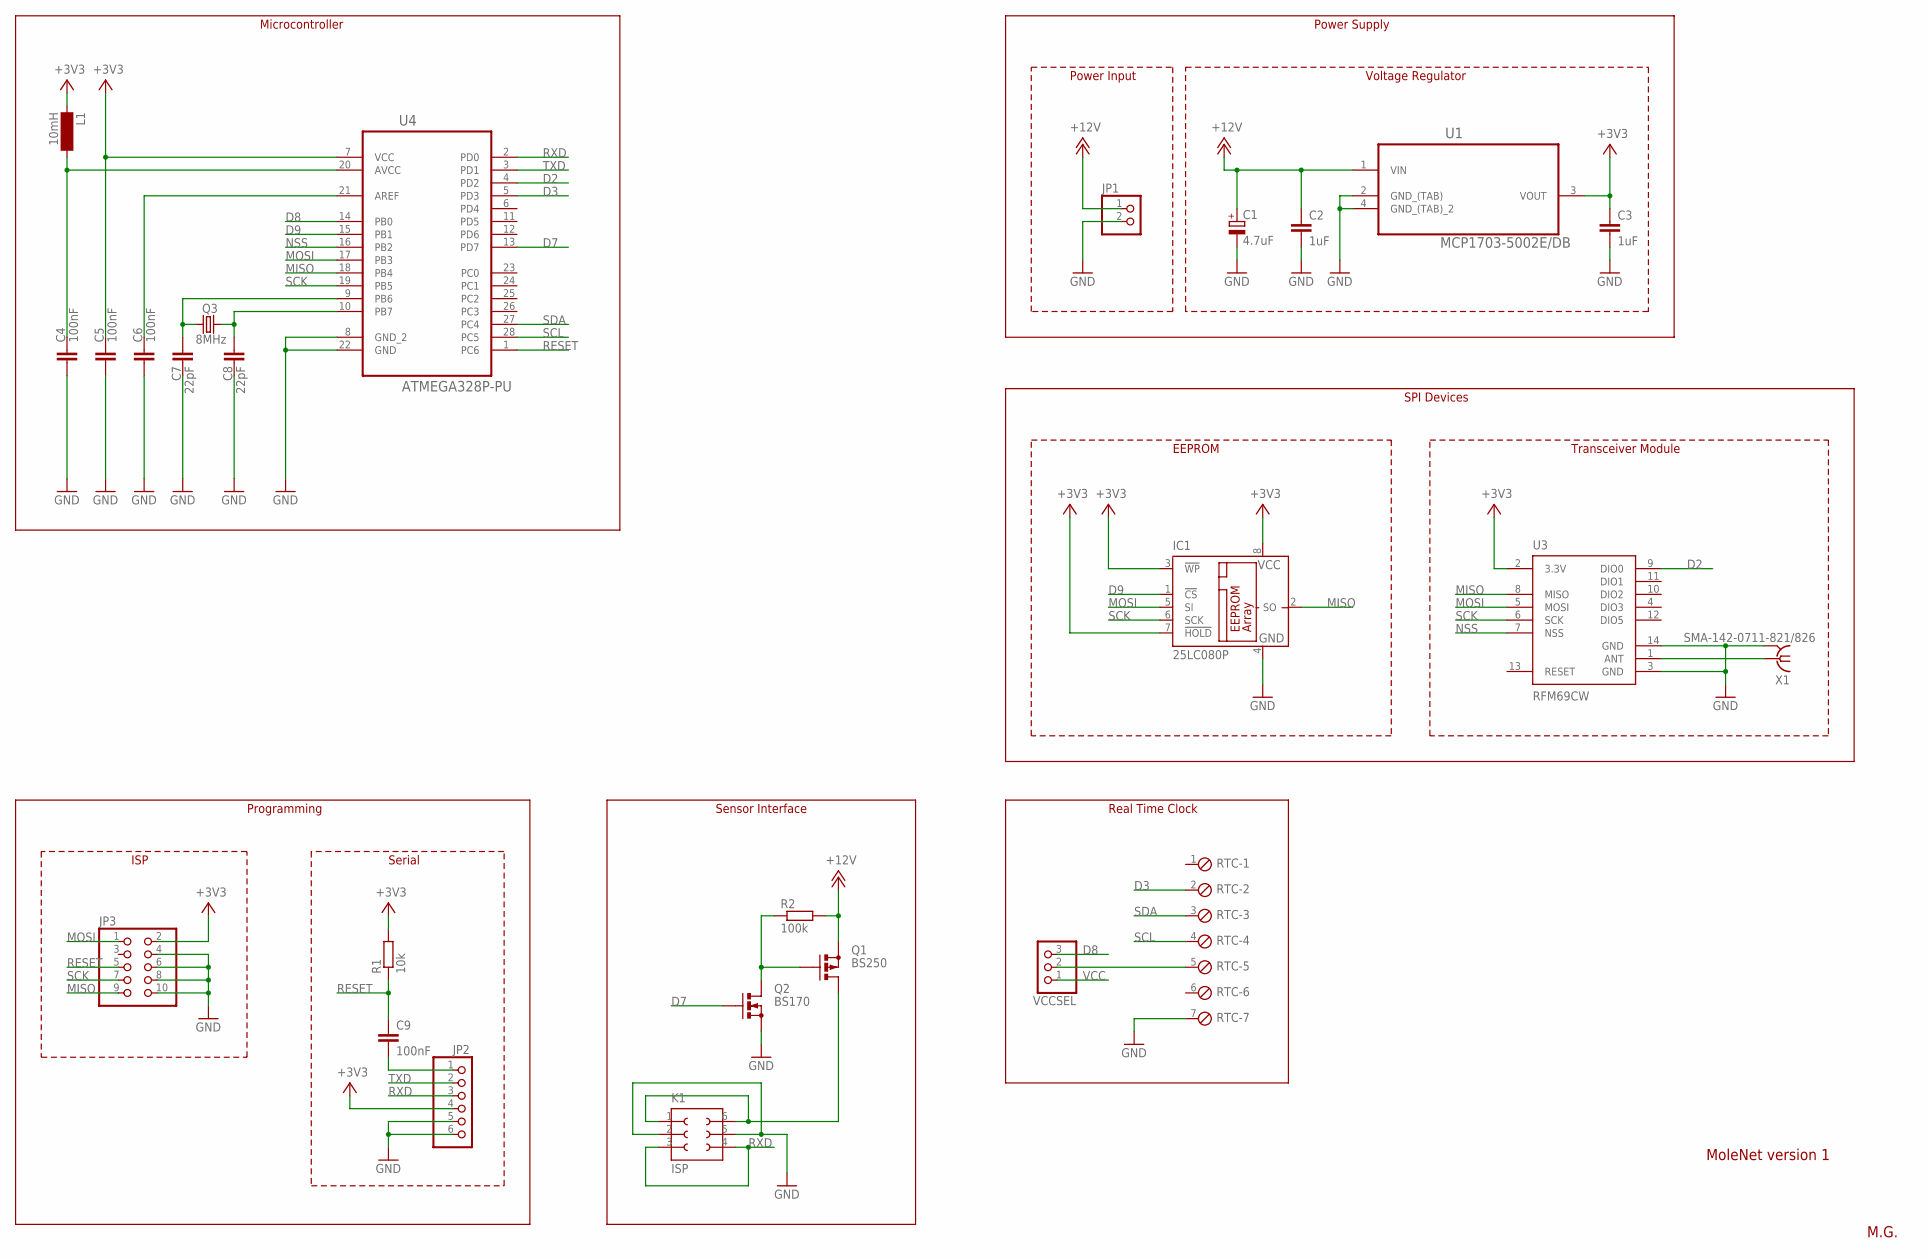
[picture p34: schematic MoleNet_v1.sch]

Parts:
C1: 4.7uF; E2,5-6
C2, C3: 1uF; C025-025X050
C4, C5, C6, C9: 100nF; C025-025X050
C7, C8: 22pF; C025-025X050
IC1: 25LC080P; DIL8
JP1: PINHD-1X2; 1X02
JP2: PINHD-1X6; 1X06
JP3: PINHD-2X5; 2X05
K1: ISP; 691411710003
L1: 10mH; BS11
Q1: BS250; SOT54E
Q2: BS170; SOT54E
Q3: 8MHz; HC18U-V
R1: 10k; 0207/10
R2: 100k; 0207/10
RTC: MPT7; 7POL254
U1: MCP1703-5002E/DB; SOT230P700X180-4N
U3: RFM69CW; RFM69CW-XXXS2
U4: ATMEGA328P-PU; DIP254P762X457-28
VCCSEL: PINHD-1X3; 1X03
X1: SMA-142-0711-821/826; J502-ND-142-0711-821/826

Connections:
+12V: C1.+, C2.1, JP1.1, Q1.S, R2.2, U1.1 (VIN)
D2: U3.9 (DIO0), U4.4 (PD2)
D3: RTC.2, U4.5 (PD3)
D7: Q2.G, U4.13 (PD7)
D8: U4.14 (PB0), VCCSEL.3
D9: IC1.1 (!CS), U4.15 (PB1)
GND: C1.-, C2.2, C3.2, C4.2, C5.2, C6.2, C7.2, C8.2, IC1.4 (GND), JP1.2, JP2.5, JP2.6, JP3.4, JP3.6, JP3.8, JP3.10, K1.2, K1.5, Q2.S, RTC.7, U1.2 (GND_(TAB)), U1.4 (GND_(TAB)_2), U3.3 (GND), U3.14 (GND), U4.8 (GND_2), U4.22 (GND), X1.G@1 (2), X1.G@2 (2), X1.G@3 (2), X1.G@4 (2)
MISO: IC1.2 (SO), JP3.9, U3.8 (MISO), U4.18 (PB4)
MOSI: IC1.5 (SI), JP3.1, U3.5 (MOSI), U4.17 (PB3)
unnamed: Q1.G, Q2.D, R2.1
unnamed: K1.1, K1.6, Q1.D
unnamed: C7.1, Q3.1, U4.9 (PB6)
unnamed: C8.1, Q3.2, U4.10 (PB7)
unnamed: C4.1, L1.2, U4.20 (AVCC)
unnamed: C6.1, U4.21 (AREF)
unnamed: C9.2, JP2.1
unnamed: RTC.5, VCCSEL.2
unnamed: U3.1 (ANT), X1.1
NSS: U3.7 (NSS), U4.16 (PB2)
RESET: C9.1, JP3.5, R1.1, U4.1 (PC6)
RXD: JP2.3, K1.3, K1.4, U4.2 (PD0)
SCK: IC1.6 (SCK), JP3.7, U3.6 (SCK), U4.19 (PB5)
SCL: RTC.4, U4.28 (PC5)
SDA: RTC.3, U4.27 (PC4)
TXD: JP2.2, U4.3 (PD1)
VCC: C3.1, C5.1, IC1.3 (!WP), IC1.7 (!HOLD), IC1.8 (VCC), JP2.4, JP3.2, L1.1, R1.2, U1.3 (VOUT), U3.2 (3.3V), U4.7 (VCC), VCCSEL.1

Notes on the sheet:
MoleNet version 1
M.G.
Microcontroller
Power Supply
SPI Devices
Real Time Clock
Sensor Interface
Programming
ISP
Serial
EEPROM
Transceiver Module
Power Input
Voltage Regulator

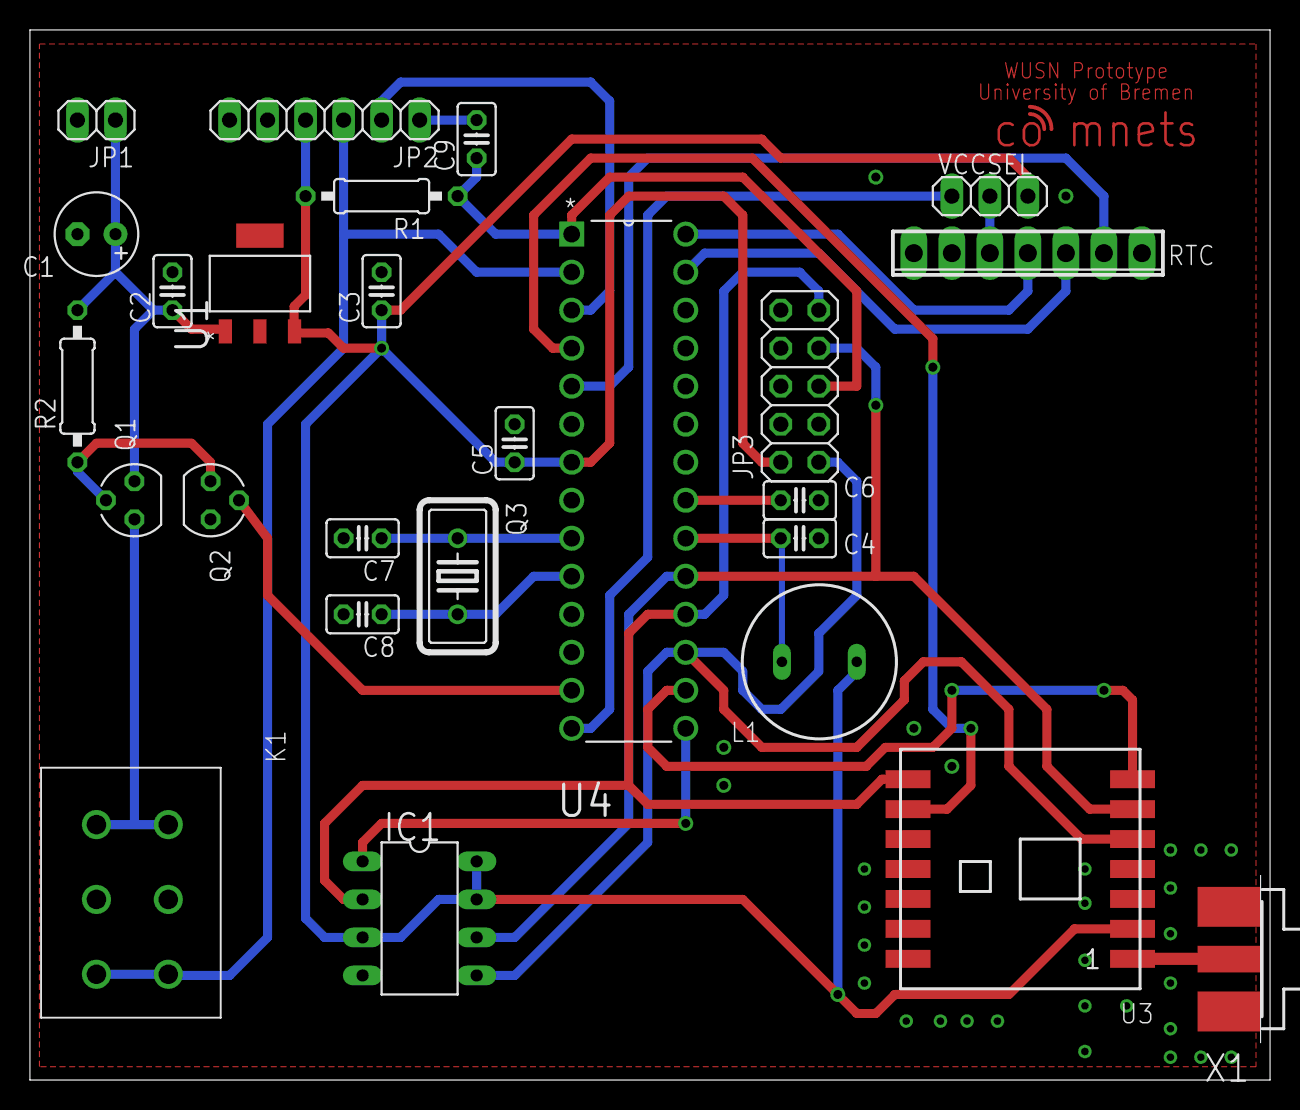
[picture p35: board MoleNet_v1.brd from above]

Board: 2 copper layers, 82.9 x 70.2 mm, 26 parts (0 on the bottom side), 26 nets.

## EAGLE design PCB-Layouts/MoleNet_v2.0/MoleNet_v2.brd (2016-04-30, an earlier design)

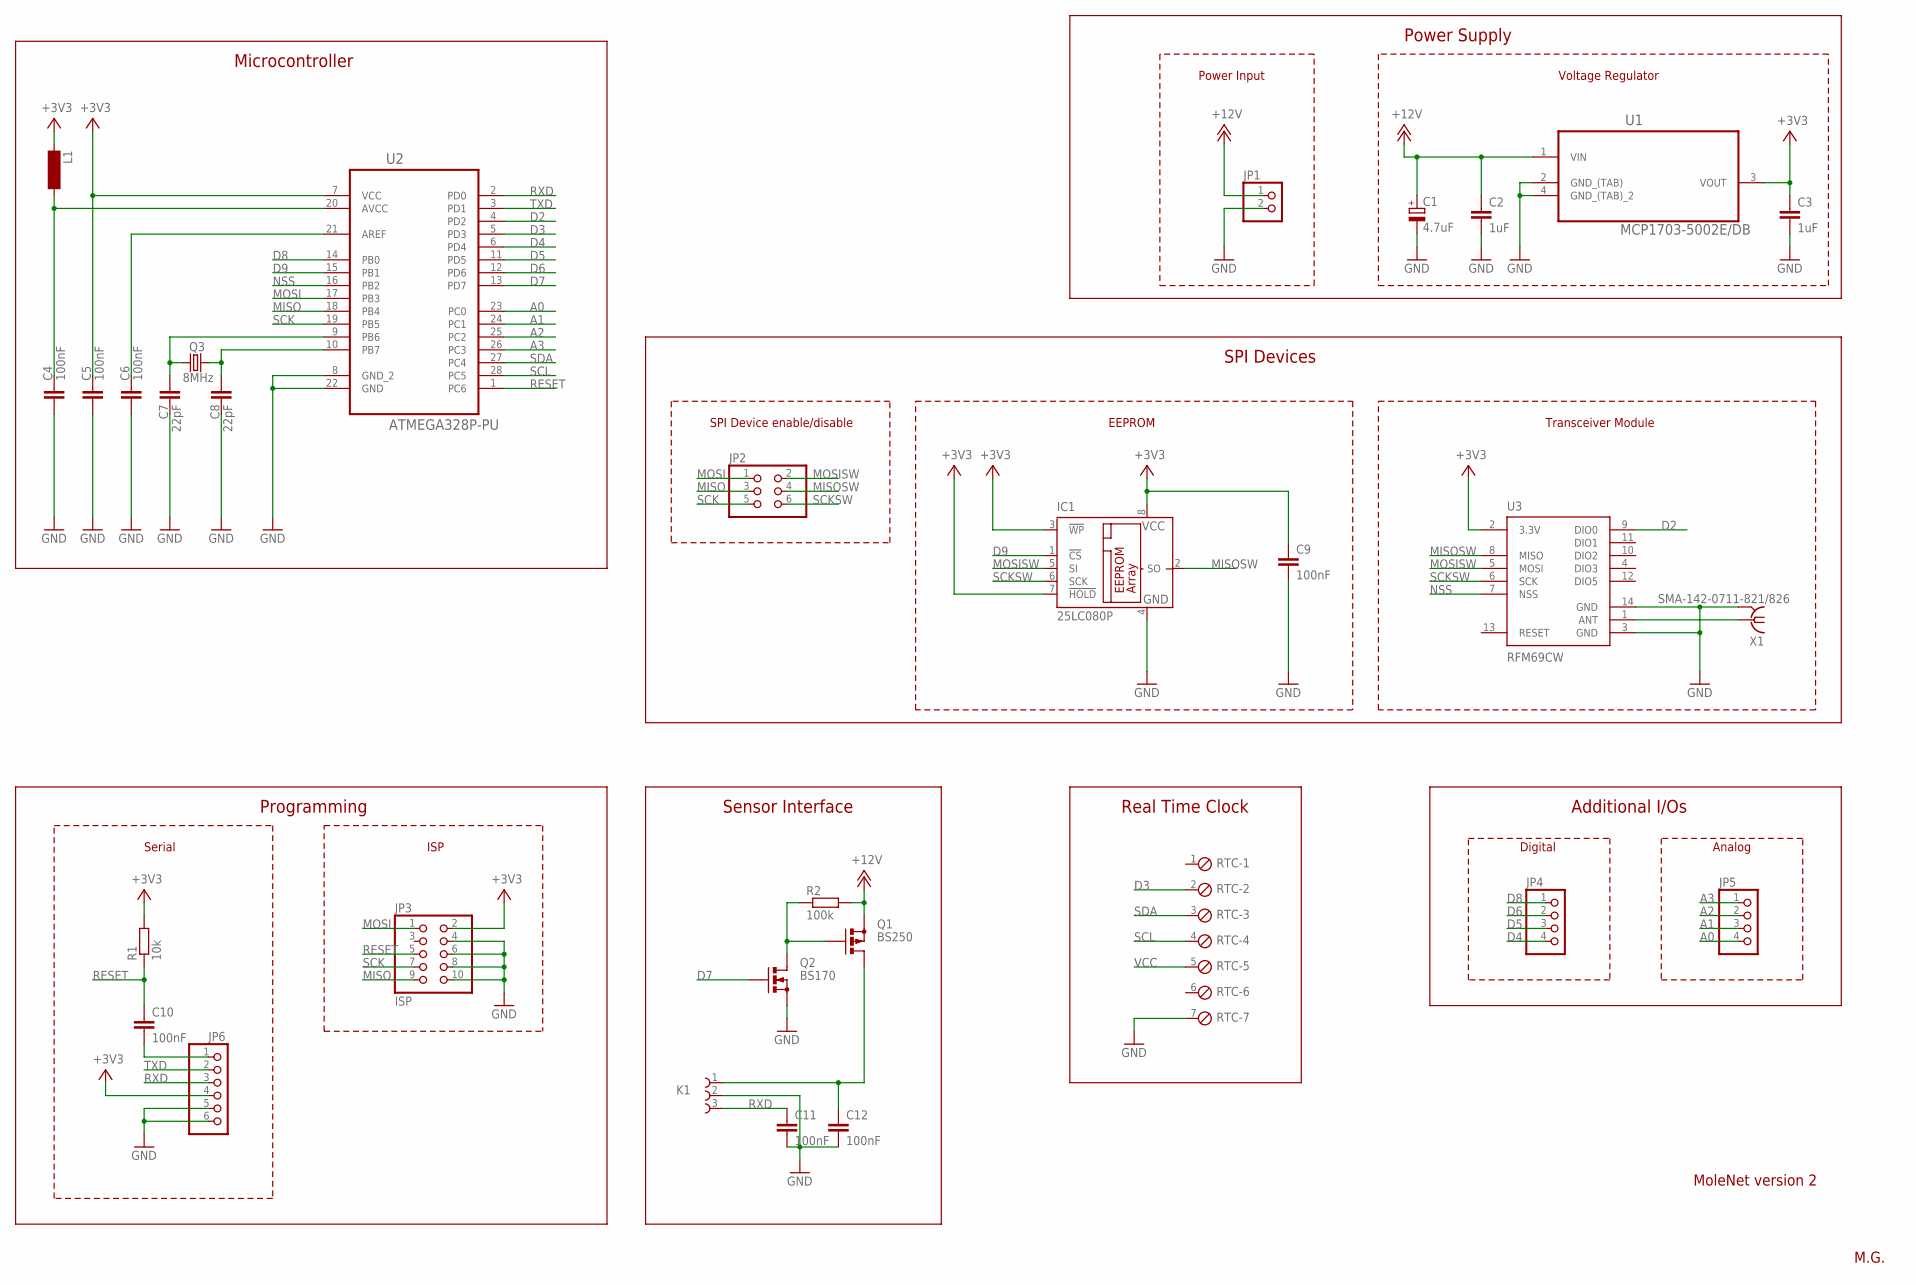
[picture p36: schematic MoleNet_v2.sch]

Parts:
C1: 4.7uF; E2,5-6
C2, C3: 1uF; C025-025X050
C4, C5, C6, C9, C10, C11, C12: 100nF; C025-025X050
C7, C8: 22pF; C025-025X050
IC1: 25LC080P; DIL8
JP1: PINHD-1X2; 1X02
JP2: PINHD-2X3; 2X03
JP3: ISP; 2X05
JP4, JP5: PINHD-1X4; 1X04
JP6: PINHD-1X6; 1X06
K1: 691241710003
L1: BS11
Q1: BS250; SOT54E
Q2: BS170; SOT54E
Q3: 8MHz; HC18U-V
R1: 10k; 0207/10
R2: 100k; 0207/10
RTC: MPT7; 7POL254
U1: MCP1703-5002E/DB; SOT230P700X180-4N
U2: ATMEGA328P-PU; DIP254P762X457-28
U3: RFM69CW; RFM69CW-XXXS2
X1: SMA-142-0711-821/826; J502-ND-142-0711-821/826

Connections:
+12V: C1.+, C2.1, JP1.1, Q1.S, R2.2, U1.1 (VIN)
A0: JP5.4, U2.23 (PC0)
A1: JP5.3, U2.24 (PC1)
A2: JP5.2, U2.25 (PC2)
A3: JP5.1, U2.26 (PC3)
D2: U2.4 (PD2), U3.9 (DIO0)
D3: RTC.2, U2.5 (PD3)
D4: JP4.4, U2.6 (PD4)
D5: JP4.3, U2.11 (PD5)
D6: JP4.2, U2.12 (PD6)
D7: Q2.G, U2.13 (PD7)
D8: JP4.1, U2.14 (PB0)
D9: IC1.1 (!CS), U2.15 (PB1)
GND: C1.-, C2.2, C3.2, C4.2, C5.2, C6.2, C7.2, C8.2, C9.2, C11.2, C12.2, IC1.4 (GND), JP1.2, JP3.4, JP3.6, JP3.8, JP3.10, JP6.5, JP6.6, K1.2, Q2.S, RTC.7, U1.2 (GND_(TAB)), U1.4 (GND_(TAB)_2), U2.8 (GND_2), U2.22 (GND), U3.3 (GND), U3.14 (GND), X1.G@1 (2), X1.G@2 (2), X1.G@3 (2), X1.G@4 (2)
MISO: JP2.3, JP3.9, U2.18 (PB4)
MISOSW: IC1.2 (SO), JP2.4, U3.8 (MISO)
MOSI: JP2.1, JP3.1, U2.17 (PB3)
MOSISW: IC1.5 (SI), JP2.2, U3.5 (MOSI)
unnamed: Q1.G, Q2.D, R2.1
unnamed: C12.1, K1.1, Q1.D
unnamed: C7.1, Q3.1, U2.9 (PB6)
unnamed: C8.1, Q3.2, U2.10 (PB7)
unnamed: C4.1, L1.2, U2.20 (AVCC)
unnamed: C6.1, U2.21 (AREF)
unnamed: C10.2, JP6.1
unnamed: U3.1 (ANT), X1.1
NSS: U2.16 (PB2), U3.7 (NSS)
RESET: C10.1, JP3.5, R1.1, U2.1 (PC6)
RXD: C11.1, JP6.3, K1.3, U2.2 (PD0)
SCK: JP2.5, JP3.7, U2.19 (PB5)
SCKSW: IC1.6 (SCK), JP2.6, U3.6 (SCK)
SCL: RTC.4, U2.28 (PC5)
SDA: RTC.3, U2.27 (PC4)
TXD: JP6.2, U2.3 (PD1)
VCC: C3.1, C5.1, C9.1, IC1.3 (!WP), IC1.7 (!HOLD), IC1.8 (VCC), JP3.2, JP6.4, L1.1, R1.2, RTC.5, U1.3 (VOUT), U2.7 (VCC), U3.2 (3.3V)

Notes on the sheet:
MoleNet version 2
M.G.
Microcontroller
Power Supply
SPI Devices
Programming
Sensor Interface
Real Time Clock
Additional I/Os
Analog
Digital
ISP
Serial
SPI Device enable/disable
EEPROM
Transceiver Module
Power Input
Voltage Regulator

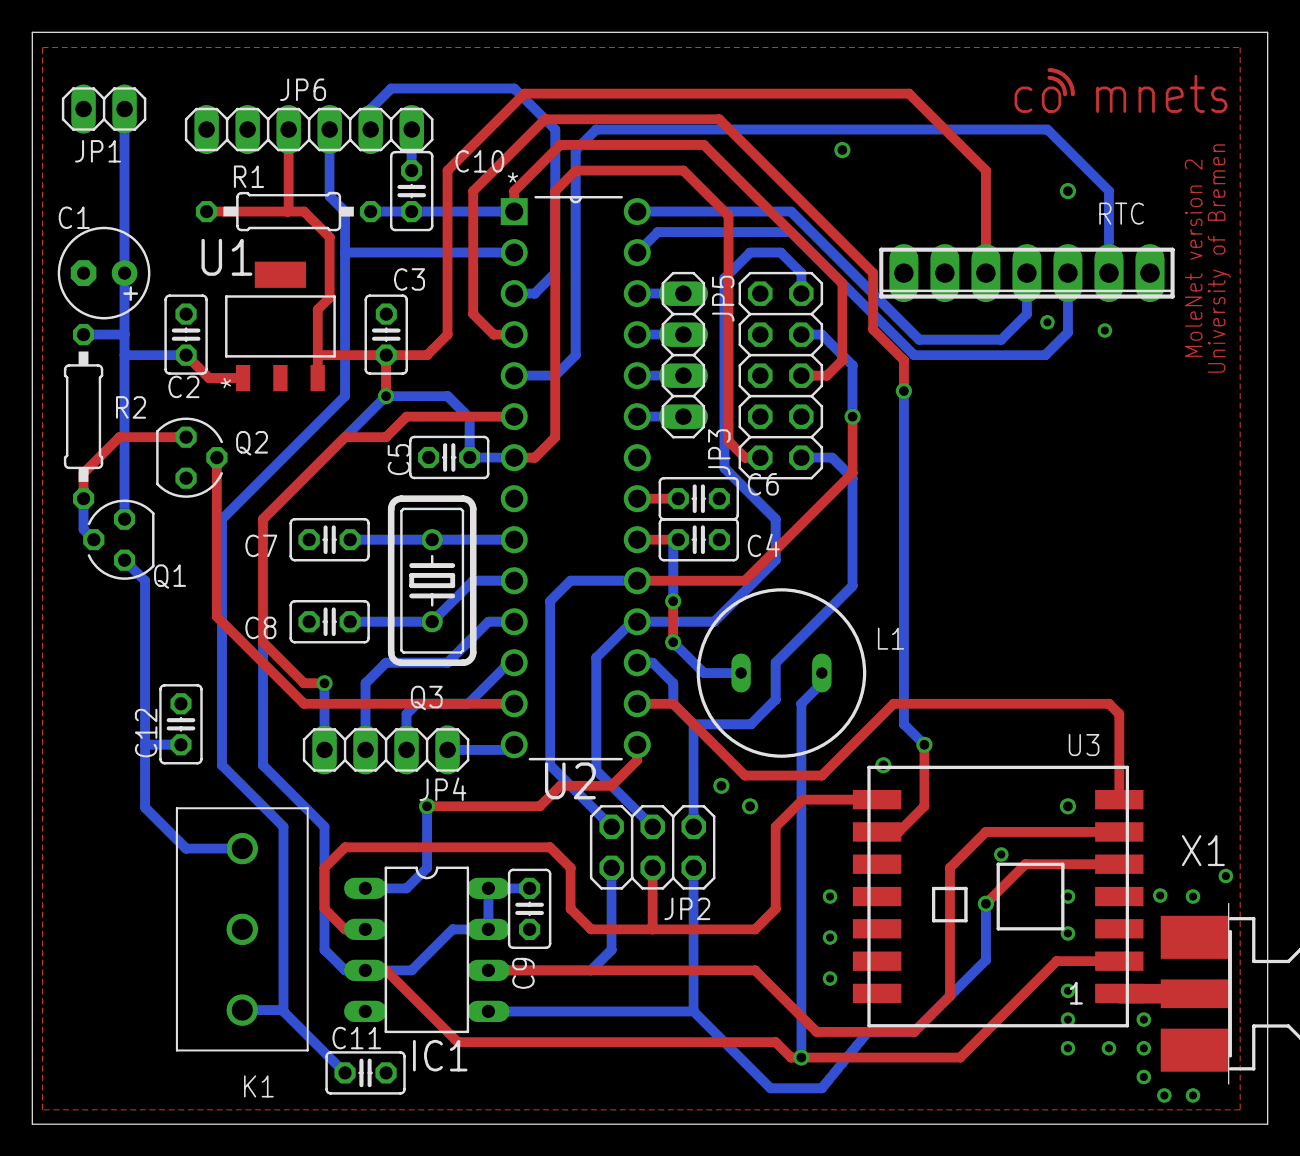
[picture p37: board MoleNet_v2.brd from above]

Board: 2 copper layers, 76.5 x 67.6 mm, 31 parts (0 on the bottom side), 35 nets.

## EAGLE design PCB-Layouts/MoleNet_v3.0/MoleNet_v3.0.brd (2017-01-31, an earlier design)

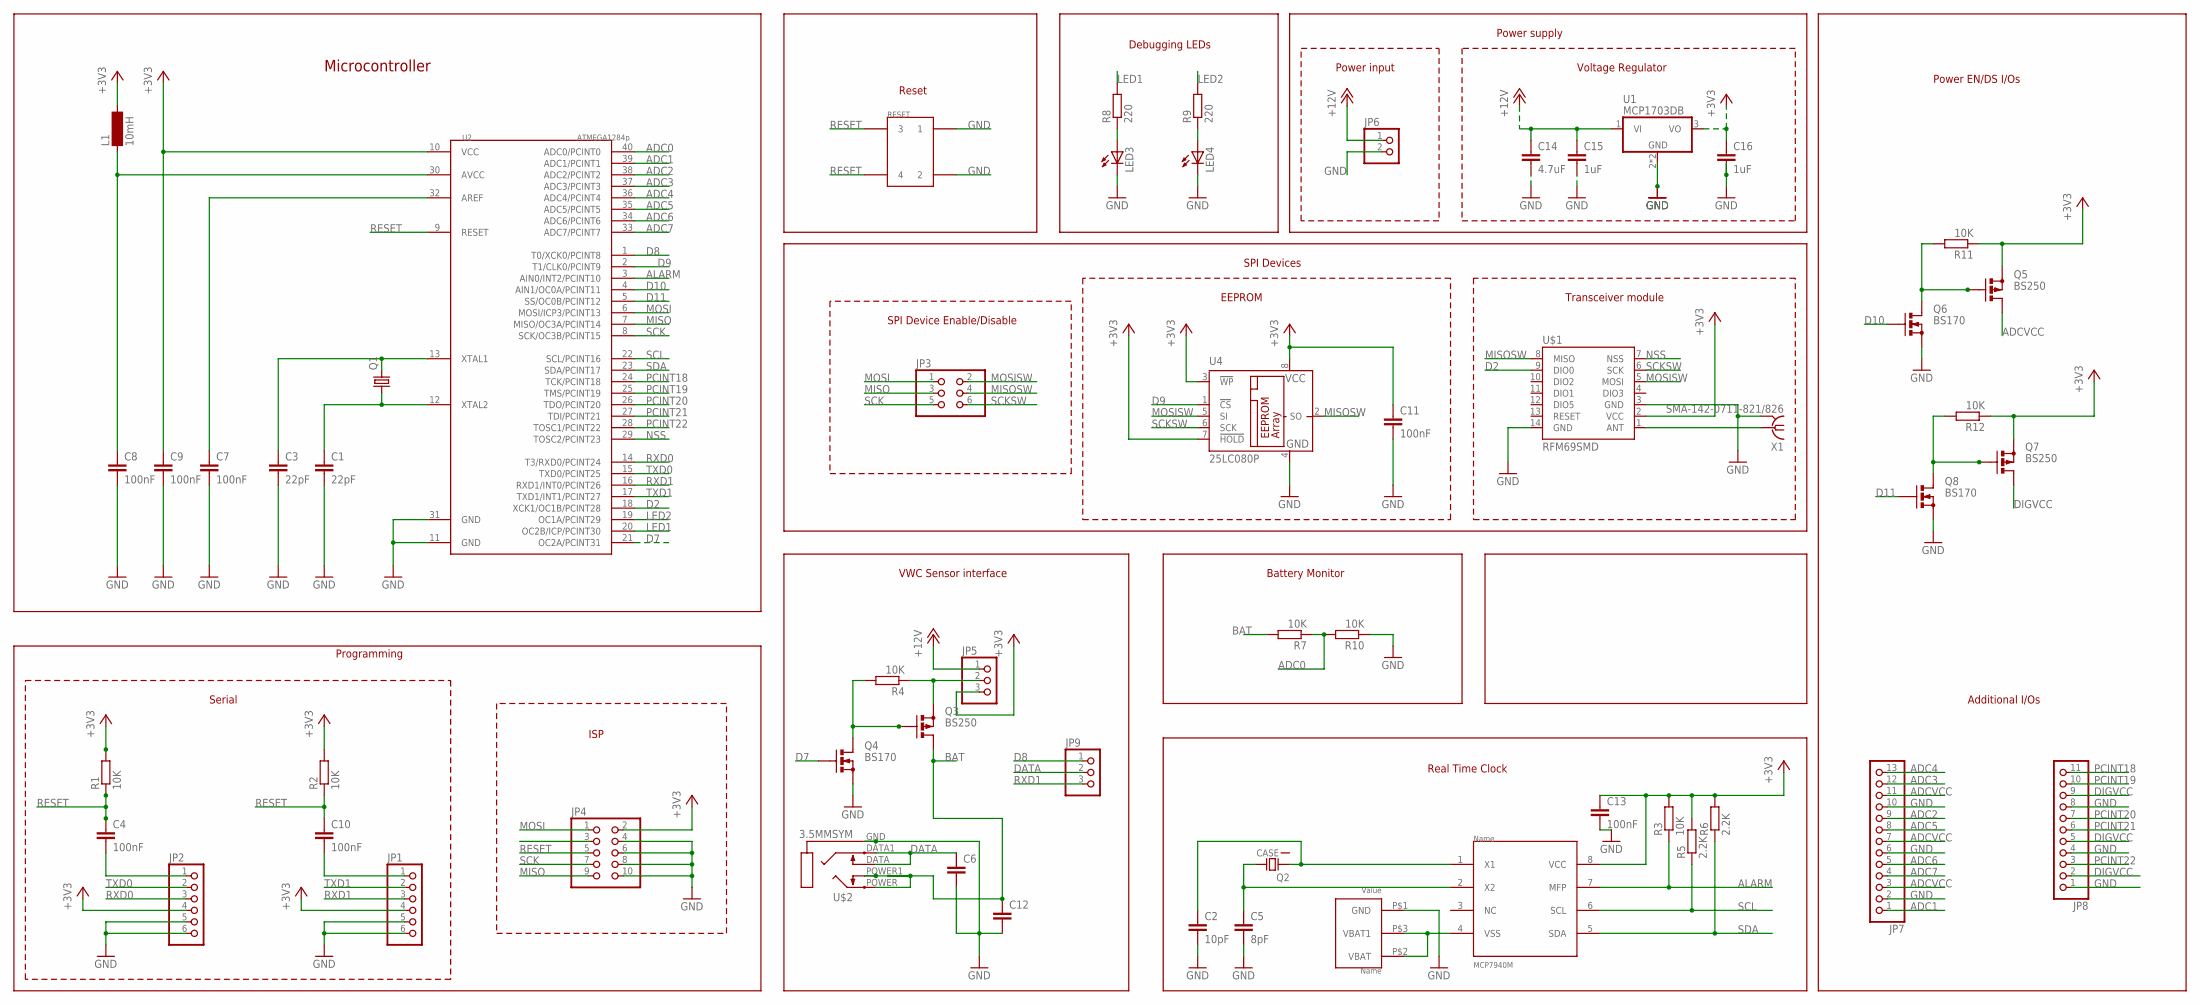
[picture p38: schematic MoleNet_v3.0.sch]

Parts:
C1, C3: 22pF; C025-025X050
C2: 10pF; C025-025X050
C4, C7, C8, C9, C10, C11, C13: 100nF; C025-025X050
C5: 8pF; C025-025X050
C6, C12: C-EU025-025X050; C025-025X050
C14: 4.7uF; C025-025X050
C15, C16: 1uF; C025-025X050
JP1, JP2: PINHD-1X6; 1X06
JP3: PINHD-2X3; 2X03
JP4: PINHD-2X5; 2X05
JP5, JP9: PINHD-1X3; 1X03
JP6: PINHD-1X2; 1X02
JP7: PINHD-1X13; 1X13
JP8: PINHD-1X11; 1X11
L1: 10mH; BS11
LED3, LED4: LEDLD260; LD260
Q1: CRYSTALHC18U-V; HC18U-V
Q2: MS1V-T1K-32.768KHZ/12.5PF/20PPM/TA/QC; MS1V-T1K
Q3, Q5, Q7: BS250; SOT54E
Q4, Q6, Q8: BS170; SOT54E
R1, R2, R3, R4, R7, R10, R11, R12: 10K; 0207/10
R5, R6: 2.2K; 0207/10
R8, R9: 220; 0207/10
RESET: RESDEV; PDIP-4
U1: MCP1703DB; SOT223
U2: ATMEGA1284p; DIL40
U4: 25LC080P; DIL8
U5: MCP7940M; DIP8
U7: BATHOLDER; BATDIP
U$1: RFM69SMD; RFM69
U$2: 3.5MMSYM; PDIP5
X1: SMA-142-0711-821/826; J502-ND-142-0711-821/826

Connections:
+3V3: C9.1, C11.1, C13.1, C16.1, JP1.4, JP2.4, JP4.2, JP5.3, L1.2, Q5.S, Q7.S, R1.2, R2.2, R3.2, R5.2, R6.2, R11.1, R12.1, U1.3 (VO), U2.10 (VCC), U4.3 (!WP), U4.7 (!HOLD), U4.8 (VCC), U5.8 (VCC), U$1.2 (VCC)
+12V: C14.1, C15.1, JP5.1, JP6.1, U1.1 (VI)
ADC0: R7.1, R10.2, U2.40 (ADC0/PCINT0)
ADC1: JP7.1, U2.39 (ADC1/PCINT1)
ADC2: JP7.9, U2.38 (ADC2/PCINT2)
ADC3: JP7.12, U2.37 (ADC3/PCINT3)
ADC4: JP7.13, U2.36 (ADC4/PCINT4)
ADC5: JP7.8, U2.35 (ADC5/PCINT5)
ADC6: JP7.5, U2.34 (ADC6/PCINT6)
ADC7: JP7.4, U2.33 (ADC7/PCINT7)
ADCVCC: JP7.3, JP7.7, JP7.11, Q5.D
ALARM: R3.1, U2.3 (AIN0/INT2/PCINT10), U5.7 (MFP)
BAT: C12.1, JP5.2, Q3.D, Q3.S, R4.1, R7.2, U$2.POWER, U$2.POWER1
D2: U2.18 (XCK1/OC1B/PCINT28), U$1.9 (DIO0)
D7: Q4.G, U2.21 (OC2A/PCINT31)
D8: JP9.1, U2.1 (T0/XCK0/PCINT8)
D9: U2.2 (T1/CLK0/PCINT9), U4.1 (!CS)
D10: Q6.G, U2.4 (AIN1/OC0A/PCINT11)
D11: Q8.G, U2.5 (SS/OC0B/PCINT12)
DATA: C6.1, JP9.2, U$2.DATA, U$2.DATA1
DIGVCC: JP8.2, JP8.5, JP8.9, Q7.D
GND: C1.2, C2.2, C3.2, C5.2, C6.2, C7.2, C8.2, C9.2, C11.2, C12.2, C13.2, C14.2, C15.2, C16.2, JP1.5, JP1.6, JP2.5, JP2.6, JP4.4, JP4.6, JP4.8, JP4.10, JP6.2, JP7.2, JP7.6, JP7.10, JP8.1, JP8.4, JP8.8, LED3.K (C), LED4.K (C), Q4.S, Q6.S, Q8.S, R10.1, RESET.1, RESET.2, U1.2 (GND), U1.4 (GND), U2.11 (GND), U2.31 (GND), U4.4 (GND), U7.P$1 (GND), U$1.3 (GND), U$1.14 (GND), U$2.GND, X1.G@1 (2), X1.G@2 (2), X1.G@3 (2), X1.G@4 (2)
LED1: R8.2, U2.20 (OC2B/ICP/PCINT30)
LED2: R9.2, U2.19 (OC1A/PCINT29)
MISO: JP3.3, JP4.9, U2.7 (MISO/OC3A/PCINT14)
MISOSW: JP3.4, U4.2 (SO), U$1.8 (MISO)
MOSI: JP3.1, JP4.1, U2.6 (MOSI/ICP3/PCINT13)
MOSISW: JP3.2, U4.5 (SI), U$1.5 (MOSI)
unnamed: C3.1, Q1.2, U2.13 (XTAL1)
unnamed: C1.1, Q1.1, U2.12 (XTAL2)
unnamed: C2.1, Q2.1, U5.1 (X1)
unnamed: C5.1, Q2.2, U5.2 (X2)
unnamed: C7.1, U2.32 (AREF)
unnamed: C4.2, JP2.1
unnamed: C8.1, L1.1, U2.30 (AVCC)
unnamed: C10.2, JP1.1
unnamed: U$1.1 (ANT), X1.1
unnamed: Q5.G, Q6.D, R11.2
unnamed: LED3.A, R8.1
unnamed: Q3.G, Q4.D, R4.2
unnamed: LED4.A, R9.1
unnamed: U5.4 (VSS), U7.P$2 (VBAT), U7.P$3 (VBAT1)
unnamed: Q7.G, Q8.D, R12.2
NSS: U2.29 (TOSC2/PCINT23), U$1.7 (NSS)
PCINT18: JP8.11, U2.24 (TCK/PCINT18)
PCINT19: JP8.10, U2.25 (TMS/PCINT19)
PCINT20: JP8.7, U2.26 (TDO/PCINT20)
PCINT21: JP8.6, U2.27 (TDI/PCINT21)
PCINT22: JP8.3, U2.28 (TOSC1/PCINT22)
RESET: C4.1, C10.1, JP4.5, R1.1, R2.1, RESET.3, RESET.4, U2.9 (RESET), U$1.13 (RESET)
RXD0: JP2.3, U2.14 (T3/RXD0/PCINT24)
RXD1: JP1.3, JP9.3, U2.16 (RXD1/INT0/PCINT26)
SCK: JP3.5, JP4.7, U2.8 (SCK/OC3B/PCINT15)
SCKSW: JP3.6, U4.6 (SCK), U$1.6 (SCK)
SCL: R5.1, U2.22 (SCL/PCINT16), U5.6 (SCL)
SDA: R6.1, U2.23 (SDA/PCINT17), U5.5 (SDA)
TXD0: JP2.2, U2.15 (TXD0/PCINT25)
TXD1: JP1.2, U2.17 (TXD1/INT1/PCINT27)

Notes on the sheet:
Microcontroller
Programming
Serial
ISP
VWC Sensor interface
Real Time Clock
SPI Device Enable/Disable
EEPROM
Transceiver module
SPI Devices
Voltage Regulator
Power input
Power supply
Reset
Debugging LEDs
Battery Monitor
Additional I/Os
Power EN/DS I/Os

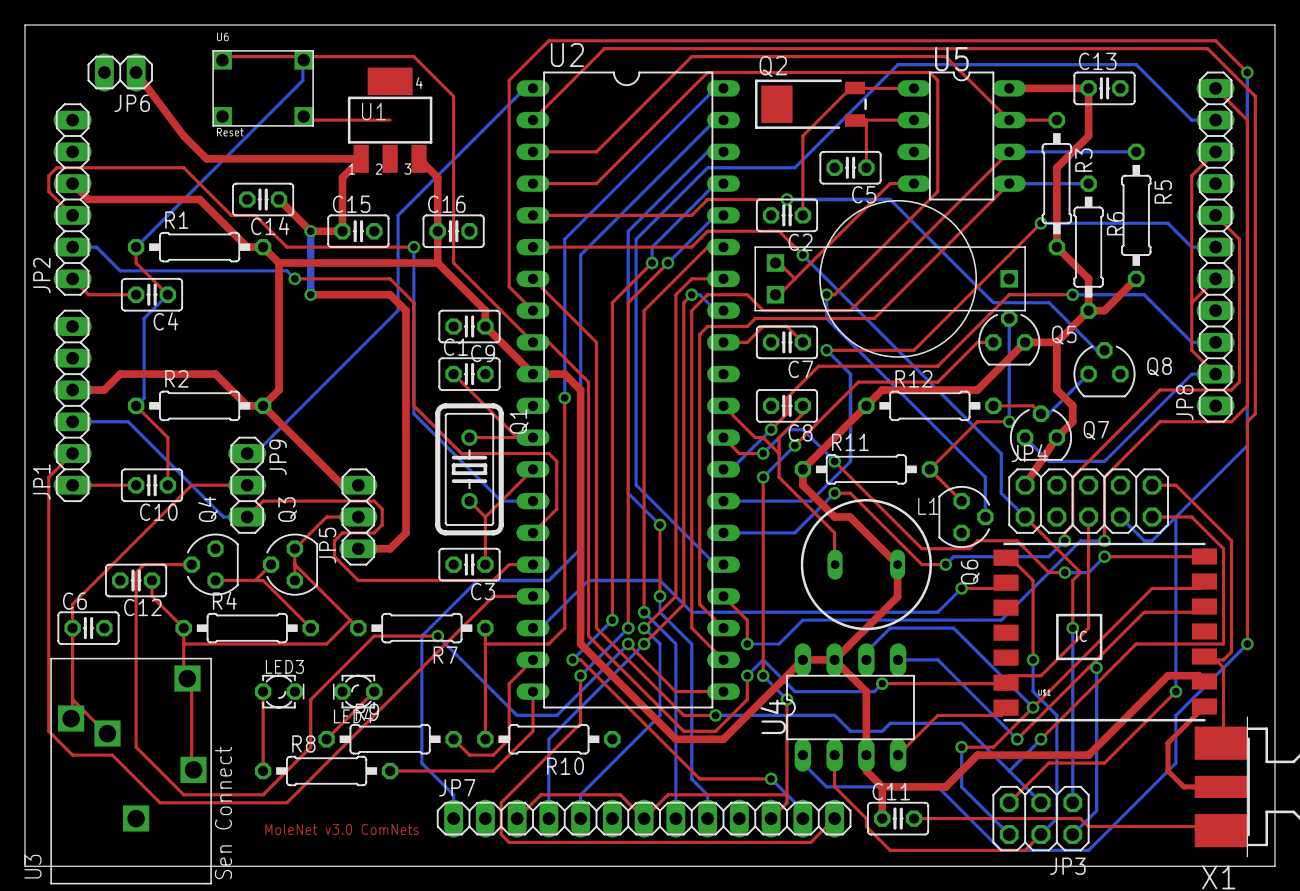
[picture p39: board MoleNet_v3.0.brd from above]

Board: 2 copper layers, 100.0 x 67.3 mm, 57 parts (0 on the bottom side), 58 nets.

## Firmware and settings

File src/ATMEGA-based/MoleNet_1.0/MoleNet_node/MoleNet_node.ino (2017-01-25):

#include <Wire.h>

#include <SPI.h>

/******************************************************************************
 * MoleNet - A Wireless Underground Sensor Network
 *
 * Copyright (C) 2016, Communication Networks, University of Bremen, Germany
 *
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
 * This file is part of MoleNet
 *
 ******************************************************************************/

/*
Program for the Prototype
read out sensor data and time/date information, store the data and transmit it
once a day at the time given by TTIME
transmission occurs directly after the read-out 
*/

/*
 * TODOs and open issues:
 * 
 * - Use Google Protobuffer (maybe https://github.com/nanopb/nanopb)?
 * - Do not use so many global variables
 * - What happens if the EEPROM is full? -> cyclic buffer?
 * - Store the NodeID in the EEPROM
 * - Use a simple console for the following points:
 *   - Set Date / Time
 *   - Clear eeprom
 *   - Maybe set the node id
 *   - Implement with a serial.read() and serial.setTimeout() (with maybe 5 seconds)
 * 
*/

#include <avr/io.h>
#include <avr/power.h>
#include <LowPower.h>			//from: https://github.com/LowPowerLab/LowPower
#include <RFM69.h>    		//from: https://www.github.com/lowpowerlab/rfm69
#include <RV8523.h>				//from: https://github.com/watterott/Arduino-Libs
#include <RV8523ALARM.h>	//own library
#include <SPIEEP.h>				//from: https://bitbucket.org/spirilis/spieep/
#include <avr/interrupt.h>
#include "./definitions.h"

/******************************************************************************/
//some definitions
/******************************************************************************/

#define NODEID        	2    			//unique for each node on same network

//#define TXDAILY
#ifdef TXDAILY
//time for the transmission of the databytes
#define TXTIME           23
#endif

#define CLOCKPRESC			clock_div_1 // reduce energy consumption, baudrate and
																		// delays need to be set accordingly!
#define EEPROM_CSPIN 		9					//EEPROM CS
#define RTC_CSPIN				8					//RTC Power
#define SENSOR_PWPIN		7					//Sensor Power
#define RXD							0					//Serial receive pin
#define TXD							1					//Seriel transmit pin (only for debugging)

#define SERIAL_BAUD 		1200			//must be 1200 baud for Decagon 5TM sensor!

#define RSETUPDELAY 		1					//delay for radio setup
#define RADIOPOWERLEVEL	31				//31: send with full power

#define INTPIN 					3					//pin for interrupt

#define STARTADDRESS    0x0010

/*******************************************************************************
Offsets for storing the data in the EEPROM
The storage string starts with an start indication character, followed by the 
date of the measurement. The values for the water content and the temperature
(three chars each) are both separated by indicators.
The string will be completed by a checksum for all previous values and the 
indicator for successful measurement and transmission 
*******************************************************************************/
#define BOFF            0         // Offset for the beginning of the string in 
                                  //EEPROM
#define YOFF						1					// Offset for the year of the measurement
#define MONOFF					2         // Offset for the month of the measurement
#define DOFF						3         // Offset for the day of the measurement
#define HOFF						4         // Offset for the hour of the measurement
#define MINOFF					5         // Offset for the minute of the measurement
#define W1OFF						6         // Offsets for the water content value
#define W2OFF						7
#define W3OFF						8
#define W4OFF           9
#define T1OFF						10        // Offsets for the temperature value
#define T2OFF						11
#define T3OFF						12
#define T4OFF           13
#define CHKOFF					14        // Offset for the checksum
#define SUCOFF					15        // Offset for the transmission success char

//set alarm to interrupt every full hour (i.e., interrupt everytime when
//xx:00:xx occurs)
#define MINUTE					00
#define HOUR						00
#define DAY							00
#define WEEKDAY         00
#define INI_ALARMTYPE		('m')

RV8523ALARM 	alarm;
RFM69 				radio;
RV8523 				rtc;
//SPIEEP 				eep(24,256,131072);	//for 1MBit model, library not suitable 
                                    //because variable type for full size
                                    //(here 131072) is int and thus too small
SPIEEP eep(16,128,65535);					//for 512kBit model, 
                                  //library author says: eep(16,128,65536)

/******************************************************************************/
//and now the variables
/******************************************************************************/
int 			crc;                    //variable for the crc-check

//arrays to store the values for the water content and the temperature
//char 		  wc[4] = {0x20,0x20,0x20,0x20}, temp[3] = {0x44,0x41,0x54};
//wt = {wc0,wc1,wc2,wc3,t0,t1,t2}
char wt[8] = {0x20,0x20,0x20,0x20,0x20,0x20,0x20,0x20};

//indicator for the length of the water content value
uint8_t 	wclength = 0, templength = 0;

//suc : success indicator
//
//suc == '0' : crc-check and transmission failed
//suc == '1' : crc-check successful, but transmission failed
//suc == '2' : crc-check failed, transmission successful
//suc == '3' : crc-check and transmission successful
char 			suc = 0x30;

//arrays to store the sensor data
//d[] is for the data directly coming from the sensor
//in e[], the data for the crc-check are stored
char 			e[13] = {0x00,0x00,0x00,0x00,0x00,0x00,0x00,0x00,0x00,0x00,0x00,0x00,
                  0x20};
char 			d[15] = {0x00,0x00,0x00,0x00,0x00,0x00,0x00,0x00,0x00,0x00,0x00,0x00,
									0x00,0x00,0x00};

//indicator for the completion of the sensor read-out
boolean 	stringcomplete = false, inttriggd = false;

//start address for writing on the eeprom
uint32_t	address = STARTADDRESS;
uint32_t  oldaddress = address;

//variable to store a checksum for the stored and transmitted values
char 	chksum = 0;

//variable to store the length of the string received from the sensor
uint8_t 	databytes;

//variable to store the time and date information of the measurement
uint8_t 	sec, minute, hour, day, weekday, month, yy;

//char determining the type of the alarm
//alarmtype can be chosen as:
//  - 'm' : alarm interrupt is triggered every hour at the specified minute
//  - 'h' : alarm interrupt is triggered every day at the specified hour
//  - 'd' : alarm interrupt is triggered every month on the specified day
char 			alarmtype;

byte 			sendSize = 30;//23; //22
char 			payload[] = {0x44,(char) yy, 0x2F, (char) month, 0x2F,(char) day,0x20,
                      0x74,(char) hour,0x3A,(char) minute,0x20,0x57,wt[0],wt[1],
                      wt[2],wt[3],0x20,0x54,wt[4],wt[5],wt[6],wt[7],0x20,
                      (char) chksum,0x20,suc,0x20,0x20,0x20};

/******************************************************************************/
//definition of interrupt routine
/******************************************************************************/
void intHandler()
{
  inttriggd = true;
}

/******************************************************************************/
//set up the microcontroller
/******************************************************************************/
void setup()
{
	uint16_t year;
	clock_prescale_set(CLOCKPRESC); // reduce clock to save energy

	//initialize I/O
	pinMode(INTPIN,INPUT_PULLUP);
	pinMode(RTC_CSPIN,OUTPUT);
	pinMode(SENSOR_PWPIN,OUTPUT);
	pinMode(SCL,OUTPUT);
	pinMode(RXD,INPUT);
	pinMode(TXD,OUTPUT);

  //initialize EEPROM
  eep.begin_spi(EEPROM_CSPIN);

	//send EEPROM to deep sleep
	eep.sleepmode();

  //enable serial port
	Serial.begin(SERIAL_BAUD);

  // disable ADC to save energy
  ADCSRA = 0;
	
	//send radio to sleep
	radio.sleep();
	
	//digitalWrite(RTC_CSPIN,HIGH); //not needed when jumper is set to VCC-supply

	alarm.resetCtrl();

	rtc.set24HourMode();
	rtc.start();
	rtc.batterySwitchOver(1);
	
	//set time of alarm
	alarm.setAlarmTime(MINUTE,HOUR,DAY,WEEKDAY);
	//set type of alarm
	alarm.setAlarmType(INI_ALARMTYPE);
	//make sure only the selected alarm type is activated
	switch (INI_ALARMTYPE)
	{
	  case 'm':
	    alarm.clearAlarmType('h');
	    alarm.clearAlarmType('d');
      alarm.clearAlarmType('w');
      break;
	  case 'h':
	    alarm.clearAlarmType('m');
	    alarm.clearAlarmType('d');
	    alarm.clearAlarmType('w');
	    break;
	  case 'd':
	    alarm.clearAlarmType('m');
	    alarm.clearAlarmType('h');
	    alarm.clearAlarmType('w');
	    break;
	  case 'w':
	    alarm.clearAlarmType('m');
	    alarm.clearAlarmType('h');
	    alarm.clearAlarmType('d');
	    break;
	  default:
	    break;
	}
  //activate the alarm
	alarm.activateAlarm();

	//get current time from RTC
	rtc.get(&sec, &minute, &hour, &day, &month, &year);
	alarm.getWeekday(&weekday);

	//print a welcome message
	Serial.print("\n*************\nhello!\n");

	Serial.print("Time read\n");
	delay(2000);
	//print current time and date
	Serial.print("Time: ");
	Serial.print(hour, DEC);
	Serial.print(":");
	Serial.print(minute, DEC);
	Serial.print(":");
	Serial.print(sec, DEC);
	Serial.print("\n");
  switch (weekday)
	{
	  case 0:
	    Serial.print("MON");
	    break;
	  case 1:
	    Serial.print("TUE");
	    break;
	  case 2:
	    Serial.print("WED");
	    break;
	  case 3:
	    Serial.print("THU");
	    break;
	  case 4:
	    Serial.print("FRI");
	    break;
	  case 5:
	    Serial.print("SAT");
	    break;
	  case 6:
	    Serial.print("SUN");
	    break;
	  default:
	    Serial.print("BAD");
	    break;
	}
	Serial.print(" ");
	Serial.print(year,DEC);
	Serial.print(" ");
	Serial.print(month,DEC);
	Serial.print(" ");
	Serial.print(day,DEC);
	Serial.print("\n");
	delay(1000);

  //reset alarm interrupt just in case
	alarm.resetInterrupt();
	
	//create an interupt for the rtc alarm
	attachInterrupt(1, intHandler, FALLING);
	
	getrtctime();
	delay(500);
	readsensor();
	delay(500);
	sender();
	
	//just being polite :-)
	Serial.print("good night!\n");
	delay(1000);
}

/******************************************************************************/
//the main loop
/******************************************************************************/
void loop()
{
	if (inttriggd == true)
	{	
		getrtctime();
		delay(500);
		readsensor();
		delay(500);
		#ifdef TXDAILY
		  writeToEEPROM();
		  if (hour == TXTIME)
		    sendData();
		#else
		  sender();
		  writeToEEPROM();
		  if (suc > '1')
        sendData();
    #endif

		databytes = 0;
		wclength = 0;
		templength = 0;
		//reset the success indicator and the trigger indicator
		suc = 0x30;
		alarm.resetInterrupt();
		delay(500);
		inttriggd = false;
		//send the microcontroller back to sleep
		LowPower.powerDown(SLEEP_FOREVER, ADC_OFF,BOD_OFF);
	}
	else //make sure the microcontroller is sent back to sleep
		LowPower.powerDown(SLEEP_FOREVER, ADC_OFF,BOD_OFF);
}

/******************************************************************************/
//get time from RTC module
/******************************************************************************/
void getrtctime()
{
	uint16_t year;
	//get time from RTC
  rtc.get(&sec, &minute, &hour, &day, &month, &year);
	#ifndef TXDAILY
	  //if transmission after every read-out is wanted, prepare the payload 
	  //accordingly
		payload[DD] = (char) day;
	  payload[MM] = (char) month;
	  //save space by just using the difference for the year
	  payload[YYP] = (char) (year - 2000);	
	  payload[HPOS] = (char) hour;
	  payload[MPOS] = (char) minute;
	#endif
}

/******************************************************************************/
//set the time and type of the alarm interrupt and activate it
/******************************************************************************/
void setalarm(uint8_t *minute, uint8_t *hour, uint8_t *day, uint8_t *weekday,
              char *alarmtype)
{
	alarm.setAlarmTime(*minute,*hour,*day, *weekday);
	alarm.setAlarmType(*alarmtype);
	alarm.activateAlarm();
	return;
}

/******************************************************************************/
//get data from sensor
/******************************************************************************/
void readsensor()//char *payload)
{
  uint8_t ckp = 0;	//position of checksum
  //cycle sensor to make a correct reading more propable
	digitalWrite(SENSOR_PWPIN,HIGH);
	delay(500);
	digitalWrite(SENSOR_PWPIN,LOW);
	delay(500);
	//switch sensor on and read the data
	digitalWrite(SENSOR_PWPIN,HIGH);
	serialEvent();
	if (stringcomplete == true)
	{
    //always use four digits for the water content value
    //if the sensor sends just two or three, add preceding zeros
		if (wclength == 3)
		{
		  wt[0] = 0x30;
			wt[1] = d[0];
			wt[2] = d[1];
			wt[3] = d[2];
		}
		else if (wclength == 2)
		{
			wt[0] = 0x30;
			wt[1] = 0x30;
			wt[2] = d[0];
			wt[3] = d[1];	
		}
		else
		{
		  strncpy(wt,d,4);
		}
    
    //the checksum is 8 or 9 places after the first space, depending on the 
    //temperature
		//if (templength == 3)
  	//	ckp = wclength + 8;
  	//else
  	//  ckp = wclength + 9;
    ckp = wclength + templength + 5;
    
    //copy all databytes before the checksum to verify the transmission
    //the data for the checksum provided by the sensor includes all chars
    //preceding the checksum
		strncpy(e,d,ckp);
    
    if (templength == 3)
    {
      wt[4] = 0x30;
      wt[5] = d[wclength+3];
		  wt[6] = d[wclength+4];
		  wt[7] = d[wclength+5];
    }
		else
		{
		  wt[4] = d[wclength+3];
      wt[5] = d[wclength+4];
		  wt[6] = d[wclength+5];
		  wt[7] = d[wclength+6];
		}
  
    //verify the checksum
		crc = checksum(e,ckp);
		chksum = checksum(wt,sizeof(wt));
		if (crc == d[ckp])
		{
			suc += 1;
		}
    #ifndef daily
		  payload[WPOS]   = wt[0];
		  payload[WPOS+1] = wt[1];
		  payload[WPOS+2] = wt[2];
		  payload[WPOS+3] = wt[3];
		  payload[TPOS]   = wt[4];
		  payload[TPOS+1] = wt[5];
		  payload[TPOS+2] = wt[6];
		  payload[TPOS+3] = wt[7];
		  payload[CHK]    = chksum;
		  payload[SPOS]   = suc;		  
		#endif

		stringcomplete = false; //reset the indicator for a complete receive
		
		//switch the sensor off again to save energy and allow a new reading
		digitalWrite(SENSOR_PWPIN,LOW);
		delay(500);
	}
	d[13] = 0x00;	//make shure no old data remains
	d[14] = 0x00;
	e[10] = 0x00;
	
}

/******************************************************************************/
//read out serial data (invoked by readsensor())
/******************************************************************************/
void serialEvent()
{
  //read the sensor data from the serial port
	uint8_t i = 0,first = 0;
	while (Serial.available())
	{	
		d[i] = (char)Serial.read();
		if (d[i] == 0x0D && first == 1)
		{
		  //save length of temperature string
		  templength = i - wclength - 3;
		  first = 2;
		}
		if (d[i] == ' ' && first == 0)
		{
		  //save the position of the first space
			wclength = i;
			first = 1;
		}

		if (d[i] == '\n')
		{
		  //line feed indicates the end of the transmission
			stringcomplete = true;
			databytes = i+1;
		}
		i++;
	}	
delay(1000);
}

/******************************************************************************/
//compute checksum of sensor data (invoked by readsensor())
//source: Decagon 5TM Integrator's Guide
/******************************************************************************/
char checksum(char * response, uint8_t length)
{
  //calculate the checksum of the received data
	int sum = 0, i;
	uint8_t crcsum;
	crcsum = 0;
	for (i = 0; i < length; i++)
		sum += response[i];
	crcsum = sum % 64 + 32;
	return crcsum;
}

/******************************************************************************/
//prepare to send the data and invoke the sending function
/******************************************************************************/
void sender()
{
  //set up the radio
  radiosetup();
  //wait a little bit so the radio can wake up
  delay(RSETUPDELAY);
  //send the data
  send();  
  delay(600); //mustn't be too low, definitely more than 500!
  //put radio back to sleep
  radio.sleep();
  //delay(500);
}

/******************************************************************************/
//send data if it is time for it
/******************************************************************************/
void sendData()
{
  //prepare and send the data collected since the last sending process
  //first wake up and initialize the radio
  radiosetup();
  delay(RSETUPDELAY);
  
  //set the address to the start value after the last transmission
  address = oldaddress;
  
  //read the data to be send and prepare the payload
  while (eep.read(address) == 'B' && eep.read(address+SUCOFF) == ('0' || '1'))
  {
    payload[DD]     = eep.read(address+DOFF);
  	payload[MM]     = eep.read(address+MONOFF);
  	payload[YYP]    = eep.read(address+YOFF);	
  	payload[HPOS]   = eep.read(address+HOFF);
  	payload[MPOS]   = eep.read(address+MINOFF);
   	payload[WPOS]   = eep.read(address+W1OFF);
	  payload[WPOS+1] = eep.read(address+W2OFF);
	  payload[WPOS+2] = eep.read(address+W3OFF);
	  payload[WPOS+3] = eep.read(address+W4OFF);
	  payload[TPOS]   = eep.read(address+T1OFF);
	  payload[TPOS+1] = eep.read(address+T2OFF);
	  payload[TPOS+2] = eep.read(address+T3OFF);
	  payload[TPOS+3] = eep.read(address+T4OFF);
	  payload[CHK]    = eep.read(address+CHKOFF);
	  payload[SPOS]   = eep.read(address+SUCOFF);
		//send the data
	  send();
	  delay(500);
	  //write success indicator to EEPROM to indicate whether the transmission was
	  //successful or not
	  if (suc == '2' || suc == '3')
	  {
	    write2eep(address+SUCOFF,suc);
		  oldaddress = address;
		}
		address += 0x10;
  }
  
  //put the radio back to sleep
  radio.sleep();
}

/******************************************************************************/
//set up the radio (invoked by sender())
/******************************************************************************/
void radiosetup()
{
  //initialize the radio with the desired frequency, nodeID and networkID
  radio.initialize(FREQUENCY,NODEID,NETWORKID);
  //set the transmission power to the maximum
  radio.setPowerLevel(RADIOPOWERLEVEL);
  //enable encryption for the communication
  radio.encrypt(ENCRYPTKEY);
  //radio.setFrequency(434000000); //set frequency to some custom frequency
		//didn't work in test
}

/******************************************************************************/
//actually send the data (invoked by sender())
/******************************************************************************/
void send()
{
  //send the payload, if successful add 2 to the indicator 
	if (radio.sendWithRetry(GATEWAYID,payload,sendSize,0))
	{
		suc += 2;
	}
	delay(500);
}



/******************************************************************************/
//write data to eeprom
/******************************************************************************/
void writeToEEPROM()
{
  eep.wakeup();
  //prevent previous data being overwritten after a power failure
  while (eep.read(address) == 'B')
  {
    address += 0x10;
  }
  //write the data to the EEPROM
  write2eep(address,'B');
  write2eep(address+YOFF,(byte) yy);
  write2eep(address+MONOFF,(byte) month);
  write2eep(address+DOFF,(byte) day);
  write2eep(address+HOFF,(byte) hour);
  write2eep(address+MINOFF,(byte) minute);
  write2eep(address+W1OFF,wt[0]);
  write2eep(address+W2OFF,wt[1]);
  write2eep(address+W3OFF,wt[2]);
  write2eep(address+W4OFF,wt[3]);
  write2eep(address+T1OFF,wt[4]);
  write2eep(address+T2OFF,wt[5]);
  write2eep(address+T3OFF,wt[6]);
  write2eep(address+T4OFF,wt[7]);
  write2eep(address+CHKOFF,(byte) chksum);
  write2eep(address+SUCOFF,suc);
  address += 0x10;
  eep.sleepmode();
}

/******************************************************************************/
//actually write the data to the eeprom, maximum three tries for successful 
//write
/******************************************************************************/
void write2eep(uint32_t add, byte val)
{
  //write data to EEPROM, maximum three tries
  //allows error handling by returning 1 or 0
  for (uint8_t i = 0; i<3; i++)
  {
    if (eep.write(add,val))
      return;
  }
}

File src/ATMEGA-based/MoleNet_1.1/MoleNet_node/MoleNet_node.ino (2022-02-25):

#include <avr/io.h>
#include <avr/power.h>
#include <LowPower.h>      //from: https://github.com/LowPowerLab/LowPower
#include <RFM69.h>         //from: https://www.github.com/lowpowerlab/rfm69
#include <SDI12.h>
#include <avr/interrupt.h>
#include "definitions.h"

#include "Wire.h"
#include <PCF8523.h>


#include <SPI.h>
#include <SPIEEP.h>        //from: https://bitbucket.org/spirilis/spieep/

#define SENSOR_PWPIN    7         // Sensor Power
#define SENSOR_PIN      8         // Sensor data pin
#define RTC_IRQ_PIN     3         // The Pin ID
#define RFM_IRQ_PIN     2         // The Pin ID

#define NODEID          5         // The ID should not be 1 -> the gateway is our number one!

#define EEPROM_CSPIN    9         // CS for EEPROM
#define CLOCKPRESC      clock_div_1 // reduce energy consumption, baudrate

#define SENDMINUTE      0         // Send every full hour

#define UTCOFFSET       2         // Time offset while programming this sketch to set the RTC to UTC

#if NODEID == 1
#error The node id is one but I am quite sure that this is not a gateway
#endif

// TODO:
// Use new flash lib?
// Use internal EEPROM (EEPROM.h) for config data


SDI12 mySDI12(SENSOR_PIN);

PCF8523 rtc;

SPIEEP eep(16, 128, 65535);

NodeData_v1 nodeData;

volatile boolean alarmTriggered = false;

uint8_t seq = 0; // A sequence number for the packets

RFM69 radio;

void setup() {
  //clock_prescale_set(CLOCKPRESC); // reduce clock to save energy. Results into problems with

  Serial.begin(115200);
  Serial.print("Sketch complied on: ");
  Serial.print(F(__DATE__));
  Serial.print(" ");
  Serial.println(F(__TIME__));
  randomSeed(analogRead(0));

  pinMode(RTC_IRQ_PIN, INPUT_PULLUP);

  Wire.begin();
  rtc.begin();
  if (! rtc.isrunning()) {
    Serial.println("RTC not running. Setting time to sketch compile time");
    rtc.setTime(DateTime(F(__DATE__), F(__TIME__)) - TimeSpan(UTCOFFSET * 60 * 60));
  } else {
    Serial.println("The RTC is running. Doing nothing");
  }

  rtc.setBatterySwitchover();
  rtc.setTwelveTwentyFourHour(eTWENTYFOURHOUR);
  rtc.setAlarm(SENDMINUTE);
  rtc.enableAlarm(true);

  Serial.print("RTC power low: "); Serial.println(rtc.rtcBatteryLow());


  init_radio();
  radio.sleep();

  eep.begin_spi(EEPROM_CSPIN);
  eep.sleepmode();

  pinMode(RTC_IRQ_PIN, INPUT);

  // Force reading the RTC state
  irqHandler();

  seq = random(0, 250); // Init sequence number with random value.

  Serial.println("### Setup done");
}

void loop() {
  detachInterrupt(digitalPinToInterrupt(RTC_IRQ_PIN));

  if (alarmTriggered) {
    Serial.println("Sending data");
    initData(&nodeData);
    getSensorData(&nodeData);
    getTime(&nodeData);

    sendData(&nodeData);
    printData_v1(&nodeData);

    //    alarm.resetInterrupt();
    alarmTriggered = false;

  }

  rtc.ackAlarm();

  //create an interupt for the rtc alarm
  attachInterrupt(digitalPinToInterrupt(RTC_IRQ_PIN), irqHandler, FALLING);

  // Go for deep sleep
  Serial.println("Going to sleep mode");
  Serial.flush();
  LowPower.powerDown(SLEEP_FOREVER, ADC_OFF, BOD_OFF);

}



/**
   Init the data structure with some basic information
*/
void initData(NodeData_v1 *nd) {
  seq++;
  nd->version = 1;
  nd->sent = false;
  nd->rssi = 0;
  nd->sender_id = NODEID;
  nd->sequence = seq;
}

/**
   Get the current time and store it to the data structure
*/
void getTime(NodeData_v1 *nd) {
  DateTime now = rtc.readTime();
  nd->sec = now.second();
  nd->minute = now.minute();
  nd->hour = now.hour();
  nd->day = now.day();
  nd->month = now.month();
  nd->year = now.year();
}


/**
   Send the data structure to the gateway
*/
boolean sendData(NodeData_v1 *nd) {
  init_radio();
  Serial.print("Size of packet "); Serial.println(sizeof(*nd));
  //nd->sent = radio.sendWithRetry(GATEWAYID, (byte*)nd, sizeof(*nd), (uint8_t)3, RFM69_ACK_TIMEOUT * 6);
  nd->sent = moleSendWithRetry(GATEWAYID, (byte*)nd, sizeof(*nd), (uint8_t)3, RFM69_ACK_TIMEOUT * 6); // MoleNet function, handle data from ACK packet -> timestamp
  nd->rssi = radio.RSSI;
  // Maybe add delay before going to slee? Was done so in previous version.
  radio.sleep();
  // Ensure uc is not woken up by radio in deep sleep
  // Will be enabled by init_radio again

}

/**
   Read out sensor data and store it to the data structure
*/
void getSensorData(NodeData_v1 *nd) {
  mySDI12.begin();
  pinMode(SENSOR_PWPIN, OUTPUT);
  digitalWrite(SENSOR_PWPIN, HIGH);
  delay(300);


  mySDI12.sendCommand("?I!");
  delay(300);

  String sensorId;

  while (mySDI12.available()) {
    sensorId = mySDI12.readStringUntil('\n');
  }

  String newCommand(sensorId[0]);
  newCommand += "M!";
  mySDI12.sendCommand(newCommand); // 0MC! -> Data from sensor 0 including checksum, exclude C for no checksum
  delay(300);

  String startMeasurements = mySDI12.readStringUntil('\n'); // 00013 -> sensor 0, 001 -> 1sec waiting for measurement, 3 data values
  while (mySDI12.available())mySDI12.read();
  delay(startMeasurements.substring(1, 4).toInt() * 1000); // SleepTime
  int numMeasurements = startMeasurements.substring(4).toInt();   // Number of measurements

  newCommand = sensorId[0];
  newCommand += "D0!";

  mySDI12.sendCommand(newCommand); // 0D0! -> Data from sensor 0 including checksum
  delay(300);

  String datastring = mySDI12.readStringUntil('\n'); // Data string
  while (mySDI12.available())mySDI12.read();

  Serial.print("Datastring from Sensor: "); Serial.println(datastring);

  // TODO: Change for sensors without conductivity, check with number of sensors variable
  nd->vwc = datastring.substring(getNIndexOf(datastring, '+', 0) + 1, getNIndexOf(datastring, '+', 1)).toFloat();
  nd->temp = datastring.substring(getNIndexOf(datastring, '+', 1) + 1, getNIndexOf(datastring, '+', 2)).toFloat();
  nd->cond = datastring.substring(getNIndexOf(datastring, '+', 2) + 1).toFloat();

  mySDI12.end();
  digitalWrite(SENSOR_PWPIN, LOW);
}

/**
   Initialize the radio and prepare for sending
*/
void init_radio()
{
  //initialize the radio with the desired frequency, nodeID and networkID
  radio.initialize(FREQUENCY, NODEID, NETWORKID);
#ifdef IS_RFM69HW_HCW
  radio.setHighPower(); //must include this only for RFM69HW/HCW!
#endif
  radio.setPowerLevel(RADIO_POWERLEVEL);
  //enable encryption for the communication
  radio.encrypt(ENCRYPTKEY);
  //radio.setFrequency(434000000); //set frequency to some custom frequency
  //didn't work in test
  delay(1); // TODO: Check
}
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

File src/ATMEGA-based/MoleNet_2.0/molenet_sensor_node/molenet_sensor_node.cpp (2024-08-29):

/******************************************************************************
 * MoleNet - A Wireless Underground Sensor Network
 *
 * Copyright (C) 2016, Communication Networks, University of Bremen, Germany
 *
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
 * This file is part of MoleNet
 *
 ******************************************************************************
 * ============================================================================
 *
 *       Filename:  molenet_sensor_node.cpp
 *
 *    Description:  The main library for MolneNet Sensor Node. It conatins 
 *                  all the functionalities of Multihop routing.
 *                  Implementation File.         
 * 
 *        Version:  1.0
 *        Created:  14/08/2016 10:00:00 
 *       Revision:  none
 *       Compiler:  gcc
 *
 *         Author:  Muhammad Haseeb (MSc. Student-IAE University of Bremen), 
 *                  mhaseeb@uni-bremen.de, 
 *                  hasee.b@hotmail.com
 *   Organization:  COMNETS, Communication Networks Department
 *                  University of Bremen, Bremen, Germany
 *
 * ============================================================================
 */

#include "molenet_sensor_node.h"

MoleNet_Node::MoleNet_Node() :
    Decagon5TM(Pin::SENSOR_PW,Pin::RX_SS, Pin::TX_SS ),
    CLOCKPRESC(clock_div_1), 
    ExternalEEPROM( static_cast<RFM69mh*>(this)),
    InternalEEPROM( static_cast<ExternalEEPROM*>(this)),
    messages( static_cast<RFM69mh*>(this) )
{
}

void MoleNet_Node::begin()
{
    loadStartupConfig();
   
    initializeSerial();
    initializeIO();
    RV8523_RTC::initializeRTC();   
    RFM69mh::initialize(config[StartupConfig::pos_NODEID]);
    ExternalEEPROM::initialize();
    
   applyStartupConfig(); 
}

void MoleNet_Node::send_typ_DECAGON5TM_SENSOR(const uint8_t &nextHop, const uint8_t &sinkID, const bool &ifConcatinate)
{
    if( !Decagon5TM::getChecksum() ) {          // if checksum is correct, only then proceed
        PRINT_ERROR_SENSOR_CHECKSUM_INCORRECT
        return;
    }

    PRINT_PACKET_SENT( RFM69::_address, nextHop)
    messages.decagon5tm.fillHeader( sinkID );    
    messages.decagon5tm.fillData( (uint32_t)4 , 
                                  (uint32_t)Decagon5TMData::DATA_POS_START,
                                  (uint32_t)RV8523_RTC::getClockTime(),
                                  (uint32_t)Decagon5TM::getDielectric(),
                                  (uint32_t)Decagon5TM::getTemperature() );
    messages.decagon5tm.debug_Header_AND_Message();

    transmitOrSave(nextHop, Decagon5TMData::DATA_SIZE, ifConcatinate);         
}

void MoleNet_Node::send_typ_MOISTURE_TEMP_SENSOR(const uint8_t &nextHop, const uint8_t &sinkID, const bool &ifConcatinate)
{
    PRINT_PACKET_SENT( RFM69::_address, nextHop)    
    messages.moistureTempData.fillHeader( sinkID );    
    messages.moistureTempData.fillData( 
                                  (uint32_t)4 , 
                                  (uint32_t)MoisutreTempData::DATA_POS_START,
                                  (uint32_t)RV8523_RTC::getClockTime(),
                                  (uint32_t)analogRead(A0),
                                  (uint32_t)analogRead(A1) );
    messages.moistureTempData.debug_Header_AND_Message();

    transmitOrSave(nextHop, MoisutreTempData::DATA_SIZE, ifConcatinate);         
}
void MoleNet_Node::send_typ_DATA_PLUS_INFO(const uint8_t &nextHop, const uint8_t &sinkID, const bool &ifConcatinate)
{
    if( !Decagon5TM::getChecksum() )           // if checksum is correct, only then proceed
        return;
    
    PRINT_PACKET_SENT( RFM69::_address, nextHop)  
    messages.dataPlusInfo.fillHeader( sinkID );
    messages.dataPlusInfo.fillData( 
                                  (uint32_t)5 , 
                                  (uint32_t)DATA_PLUS_INFO::DATA_POS_START,
                                  (uint32_t)RV8523_RTC::getClockTime(),
                                  (uint32_t)Decagon5TM::getDielectric(),
                                  (uint32_t)Decagon5TM::getTemperature(),
                                  (uint32_t)ExternalEEPROM::nextAddress );
    messages.dataPlusInfo.debug_Header_AND_Message();
          
    transmitOrSave(nextHop, DATA_PLUS_INFO::DATA_SIZE, ifConcatinate);          
}




void MoleNet_Node::send_typ_RX_TX_INFORMATION(const uint8_t &nextHop, const uint8_t &sinkID, const bool &ifConcatinate)
{
    PRINT_PACKET_SENT( RFM69::_address, nextHop)  
    messages.rxTxInfomration.fillHeader( sinkID );    
    messages.rxTxInfomration.fillData(
                                (uint32_t)3 , 
                                (uint32_t)RX_TX_INFORMATION::DATA_POS_START,
                                (uint32_t)RV8523_RTC::getClockTime(),
                                (uint32_t)ExternalEEPROM::nextAddress );
    messages.rxTxInfomration.debug_Header_AND_Message();
     
    transmitOrSave(nextHop, RX_TX_INFORMATION::DATA_SIZE, ifConcatinate);       
}
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

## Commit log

2016-03-31 PCB layouts added
    [MoleNet_v1.brd, MoleNet_v1.sch, MoleNet_v2.brd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]
2016-04-02 added measurement and send cycle to setup routine to avoid empty spaces in payload at first transmission after boot
    [MoleNet_node.ino]
2016-04-07 corrected SMA connector of MoleNet v1
    [MoleNet_v1.brd, MoleNet_v1.sch]
2016-04-18 Add a TODO section and fix some bugs (temperature bug)
    [MoleNet_node.ino]
2016-04-19 Add pdf version of schematics
2016-04-28 copied MoleNet_v2 for further modifications, WiP
    [MoleNet_v21.brd, MoleNet_v21.sch]
2016-04-28 MoleNet version 2.1 ready
    [MoleNet_v21.brd, MoleNet_v21.sch]
2016-04-28 MoleNet version 2.1 rtm
    [MoleNet_v21.brd, MoleNet_v21.sch]
2016-04-28 v2.1 now really rtm :-)
    [MoleNet_v21.brd]
2016-04-30 added/corrected part values in all layouts; created partlist for version 2.1
    [MoleNet_v1.brd, MoleNet_v1.sch, MoleNet_v2.brd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]
2016-05-04 added ordering information for RS in partlist
    [partlist.ods]
2016-05-04 update pdf of partlist
    [partlist.ods]
2016-10-11 MoleNEt v3.0 Files Added
    [MoleNet_v3.0.brd, MoleNet_v3.0.sch]
2017-01-25 MoleNet v3.0 schematic updated
2017-01-25 Updated schematic and board file v3.0
    [MoleNet_v3.0.brd, MoleNet_v3.0.sch]
2017-01-31 redundant files removed
    [MoleNet_v3.0.brd, MoleNet_v3.0.sch]
2017-02-09 Main sensor node with the sensor, routing and sink example added
2020-04-03 Data added
    [Path Loss in WUSN with increase in soil moisture.csv]
2020-04-04 Field experiment data added
    [Field experiment data_VWC_UG2AG_UG2UG.csv]
2020-04-05 Path loss w.r.t vwc
    [Path Loss in WUSN with increase in soil moisture.csv]
2021-04-13 added modified library
    [LasercutCase_R3.dxf, SonarMote_lasercut plans_1.75mm acrylic.dxf]
2021-07-12 - replace self-written alarm lib - use rtc lib from library manager - set rtc according to the upload time of the sketch - cleanup
    [MoleNet_node.ino]
2021-07-13 Assuming all nodes use the same transceiver -> set power mode globally
2021-07-13 - Set the tx power correctly - Show the data as a base64 encoded string
    [MoleNet_gateway_simple.ino]
2021-07-13 Global config: Powerlevel
2021-07-13 Set radio power level according to config.
2021-07-16 Prettier datetime print function
2022-02-25 Use sequence number, reduce timeout: Will not happen too later after RFM69 lib is fixed on esp8266 side.
    [MoleNet_node.ino]
2022-03-01 MoleNet_v5 Schematic added
    [MoleNet_v5.0.brd, MoleNet_v5.0.sch]
2022-03-15 MoleNet_v5 PCB Schematic updated
    [MoleNet_v5.0.sch]
2022-03-22 SD card added, unused pins organiged
    [MoleNet_v5.0.brd]
2022-03-29 Added footprints for the SDI-12 interface components
    [MoleNet_v5.0.sch]
2022-03-30 Schematic and PCB updated
    [MoleNet_v5.0.brd, MoleNet_v5.0.sch]
2022-03-30 Merged schematic with SDI-12 interface footprints
    [MoleNet_v5.0.sch]
2022-04-04 componens inconsistency errors fixed, components on PCB arranged
    [MoleNet_v5.0.brd, MoleNet_v5.0.sch]
2022-04-05 ERC errors and warnings are fixed
    [MoleNet_v5.0.brd, MoleNet_v5.0.sch]
2022-04-12 a KiCad design file added, named MoleNet_v5.01
    [MoleNet_v5.0.brd, MoleNet_v5.0.sch, MoleNet_v5.01.kicad_pcb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]
2022-04-19 sch and kicad_pcb done, ERC and DRC checked
    [MoleNet_v5.01.kicad_sch, MoleNet_v5.01.sch]
2022-04-25 Legends added
    [MoleNet_v5.01.kicad_pcb, MoleNet_v5.01.kicad_sch]
2022-05-09 PCB updated
    [MoleNet_v5.01.kicad_pcb]
2022-05-09 u-fl connector updated
    [MoleNet_v5.01.kicad_pcb, MoleNet_v5.01.kicad_sch]
2022-05-09 pdf of schematic added
2022-05-09 Start of software redesign for MoleNet first version
    [MoleNet_gateway_WiFi.ino, MoleNet_node.ino, RV8523custom.cpp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]
2022-05-17 BOM added
    [MoleNet_v5.01.csv, MoleNet_v5.01_BOM.csv]
2022-08-07 antenna footprint updated, ERC & DRC checked
    [MoleNet_v5.01.kicad_pcb]
2022-08-10 routing updated
    [MoleNet_v5.01.kicad_sch]
2022-08-10 Added MoleNet_V5.2 PCB Design
    [MoleNet_V5.2.kicad_pcb, MoleNet_V5.2.kicad_sch]
2022-10-03 Added PCB Enclosure
    [PCB_Enclosure-Body.step, PCB_Enclosure-Body001.step, PCB_Enclosure-Body002.step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]
2023-03-30 Add gitignore for KICAD
2023-03-30 Add last version: Ordered from JCPCB
    [MoleNet_PCB_V5_2_2_BOM.csv, MoleNet_V5,2_Eurocircuits_BOM.xls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]
2024-02-16 Tested SD Card
    [MoleNet_V6_18_1_2024.kicad_pcb, MoleNet_V6_18_1_2024.kicad_sch, bom.csv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]
2024-02-22 Issue 18: Tested LoRa succesfully
    [main.py]
2024-05-22 Create Power measurement tests
2024-05-22 Add files via upload
    Power measurement code for MoleNet board
2025-02-26 Added 3D printable mounts for MoleNet V6 and V6.1
    [Molenet_V6_style_previousversion_2mm_Pillars.stl, Molenet_V6_style_previousversion_2mm_holes.stl, Simple_Molenet_Desk_Saver.stl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]
2025-05-12 unified the naming of the PCB layouts
    [JLC PART List.xlsx, JLC Part List V6.2.csv, MoleNet_PCB_V5_2_2_BOM.csv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]
2025-05-12 Further renamings
    [MoleNet_V6_18_1_2024.kicad_pcb, MoleNet_V6_18_1_2024.kicad_sch, MoleNet_v1.brd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]
2025-05-12 Make sure all layouts contain the schematic
    [MoleNet_v5.0.brd, MoleNet_v5.0.sch]
2025-05-12 Mv Arduino-libs to the corresponding src dir
2025-05-12 Further renaming
    [Field experiment data_VWC_UG2AG_UG2UG.csv, Field_experiment_2020_06_12.ods, Field_experiment_2020_06_16.ods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]
2025-05-12 Further cleanup
    [Molenet_V6_style_previousversion_2mm_Pillars.stl, Molenet_V6_style_previousversion_2mm_holes.stl, PCB_Enclosure-Body.step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]
2025-05-12 Rename boxes dir
    [Molenet_V6_style_previousversion_2mm_Pillars.stl, Molenet_V6_style_previousversion_2mm_holes.stl, PCB_Enclosure-Body.step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]
2025-05-13 Minimal Arduino doc
2025-05-16 Add files via upload
    - Label corrections.
    - Pull-up resistor (R18) for Lora Module Reset pin is removed. Instead GPIO15 used for it.
    - Additional logos on the backside.
    [Molenet_V6.3_15_05_25.kicad_pcb, Molenet_V6.3_15_05_25.kicad_sch]
2025-05-16 Add files via upload
    Production files uploaded
    [bom.csv, designators.csv, positions.csv]
2025-05-17 Add hint to intergalactic circuits to the readme
2025-08-04 Schematic in proper A3 landscape format

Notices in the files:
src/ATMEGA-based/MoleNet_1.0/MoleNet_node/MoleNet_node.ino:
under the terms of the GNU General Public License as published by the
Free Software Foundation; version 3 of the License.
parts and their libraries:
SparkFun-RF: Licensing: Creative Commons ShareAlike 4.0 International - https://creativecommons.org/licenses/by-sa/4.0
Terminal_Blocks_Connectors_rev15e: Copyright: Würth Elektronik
